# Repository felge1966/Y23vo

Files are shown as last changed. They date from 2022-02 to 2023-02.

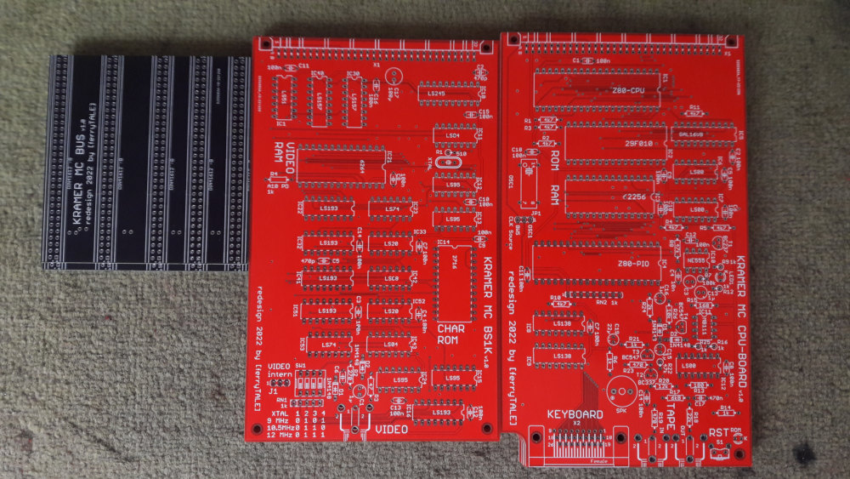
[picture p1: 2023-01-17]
Redesign-2022/KRAMER2022/KRAMER2022_v1.0.jpg

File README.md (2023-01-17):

# Y23vo
Neudesign des Mikrocomputers M.Kramer

Bisher sind folgende Baugruppen realisiert:
- CPU mit RAM und EPROM 
- BWS mit 2K Zeichengenerator 
- Floppycontroller mit u8272 (nach FA 07/1990)
- Grafikdisplaycontroller mit U82720 (nach FA 07/1990)
- 2PIO
- SIO mit U856, U857 und 8251
- Backplane mit 8 Steckplätzen

Alle Baugruppen können mit EFS 29 (A-B oder A-C) Steckverbindern oder alternativ mit DIN 41612 C 2*32 bestückt werden.

Bei CPU, 2PIO und SIO sind GALs als Decoder in Verwendung. 
Die Erstellung erfoolgte mit WinCUPL. Die Sourcen liegen im Verzeichnis

Die Verzeichnisse Redesign 2020 und Redesign 2022 stammen von der Nachetwicklung im Robotrontechnik-Forum.
-> ferrytale

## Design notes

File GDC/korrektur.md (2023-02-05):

GDC Korrektur

GDC U8 Pin 2 (DBin) zur U1 Pin11 Verbindung fehlt
U2720DC02 ist verwendbar

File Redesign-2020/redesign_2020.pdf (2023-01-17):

2022/12/17 14:11 | 1/7 | Redesign 2020

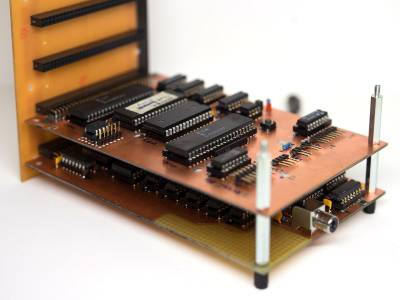
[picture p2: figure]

Homecomputer DDR - https://hc-ddr.hucki.net/wiki/

# Redesign 2020

Wie im robotron-Forum angekündigt (https://www.robotrontechnik.de/html/forum/thwb/showtopic.php?threadid=18678) möchte ich mein Redesign des Kramer-MCs aus dem ersten Corona-Lockdown 2020 gern veröffentlichen. Im Moment existieren 3 Platinen als als Quasi einseitige Layouts zum Selberätzen als Prototyp-Platinen um die etwas abgewandelte Schaltung zu testen und Korrekturen vorzunehmen, bevor dann zweiseitige Layouts zur professionellen Fertigung erstellt werden. Ich möchte damit einen einfachen Nachbau dieses interessanten Rechners auch für andere ermöglichen, ohne jedes mal ausgehend von den Originalschaltplänen von Vorne beginnen zu müssen. Die veröffentlichten Schaltplan- und Layoutdateien können anderen Bastlern gerne auch als Funktionsgrundlage für eigene Modifikationen und Erweiterungen dienen. Ich hoffe, es ist möglich, die Eagle-Dateien in andere Layout-Formate (KiCad, ) zu transformieren, denn aufgrund der Platinengröße sind die Dateien wohl nicht mehr mit der Free-Licence von Eagle veränderbar. Ich kann aber bis jetzt leider nichts anderes

als Eagle. Ich hoffe, ich schaffe es, bis Sommer 2021 die 3 hier präsentierten Module als zweiseitige, funktionierende Platinenlayouts zur Verfügung zu stellen.

Hier schon mal einiges zu dieser ersten Prototyp-Variante:

Eagle-Dateien: (https://hc-ddr.hucki.net/wiki/lib/exe/fetch.php/homecomputer/kramermc/redesign2020/kramermc_ferrytale2020_proto_eagle.zip)

kramermc_ferrytale2020_proto_eagle.zip

## CPU Board mit Tastaturinterface

einseitiges Layout auf zweiseitiger Platine, Top-Layer dient als GND, Durchkontaktierung an GND-Pins von Fassungen und Bauteilen, oder durch Draht
fehlende Verbindungen (später im 2. Layer) durch Drahtbrücken auf Leiterseite
ICs z.T. durch aktuellere Typen ersetzt:
RAM: 32kB 62256

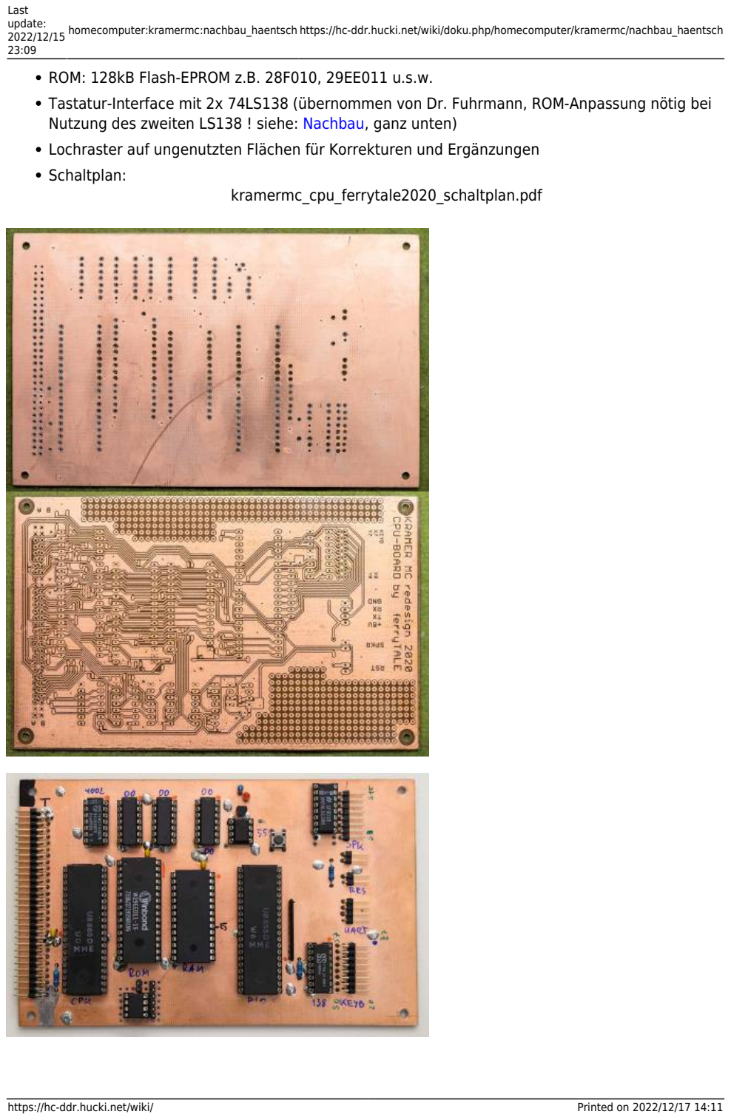
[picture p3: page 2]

Last
update:
homecomputer:kramermc:nachbau_haentsch https://hc-ddr.hucki.net/wiki/doku.php/homecomputer/kramermc/nachbau_haentsch
https://hc-ddr.hucki.net/wiki/ | Printed on 2022/12/17 14:11

ROM: 128kB Flash-EPROM z.B. 28F010, 29EE011 u.s.w.
Tastatur-Interface mit 2x 74LS138 (übernommen von Dr. Fuhrmann, ROM-Anpassung nötig bei Nutzung des zweiten LS138 ! siehe: Nachbau, (https://hc-ddr.hucki.net/wiki/doku.php/homecomputer/kramermc/nachbau) ganz unten)
Lochraster auf ungenutzten Flächen für Korrekturen und Ergänzungen
Schaltplan:
kramermc_cpu_ferrytale2020_schaltplan.pdf

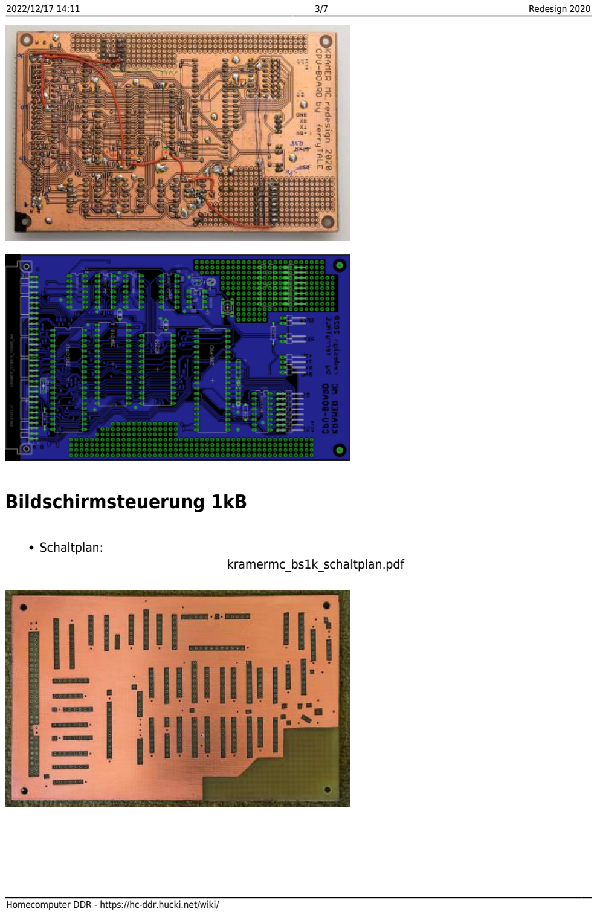
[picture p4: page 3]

2022/12/17 14:11 | 3/7 | Redesign 2020

## Bildschirmsteuerung 1kB

Schaltplan:
kramermc_bs1k_schaltplan.pdf

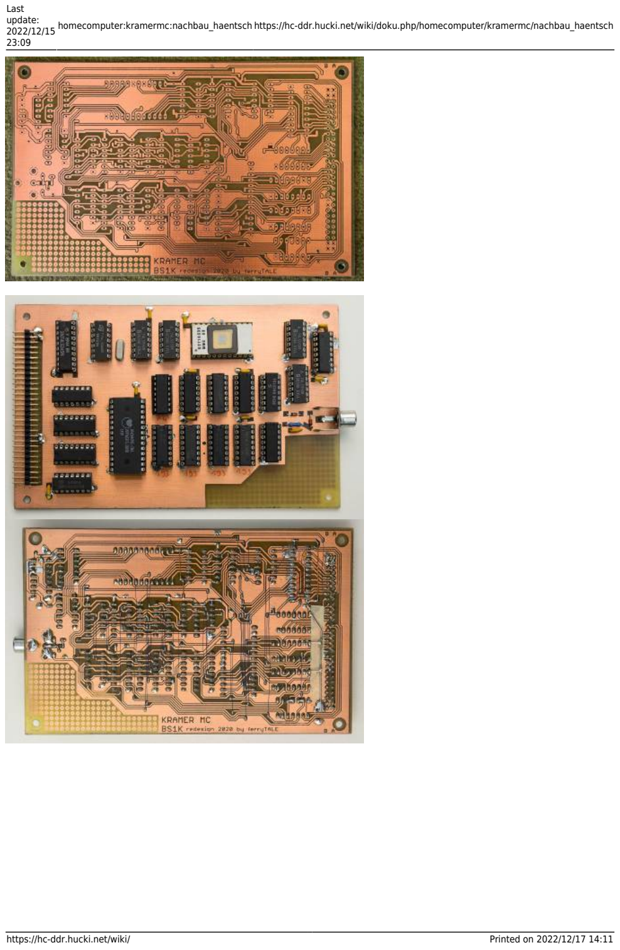
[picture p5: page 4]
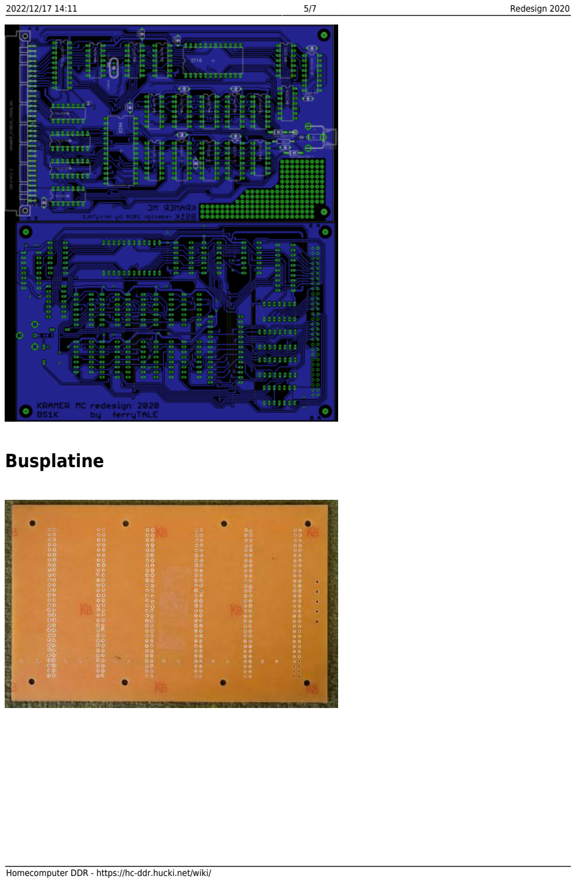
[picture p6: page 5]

2022/12/17 14:11 | 5/7 | Redesign 2020

## Busplatine

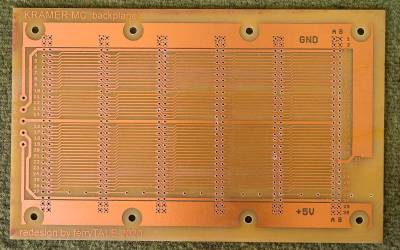
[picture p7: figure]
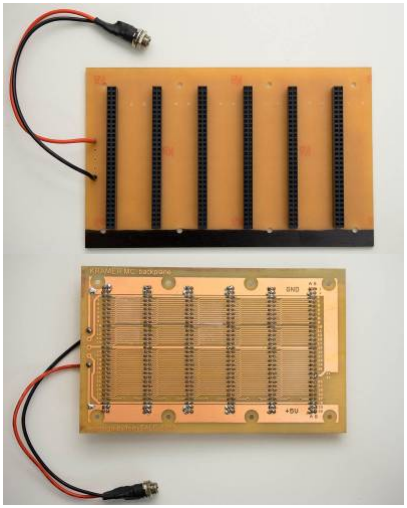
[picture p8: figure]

# 2-Layer Platinenlayouts 2022 v1.0

Ende 2022 habe ich es endlich geschafft, die zweiseitigen Platinenlayouts für CPU-Board, 1kB-Bildschirmansteuerung und eine Busplatine für 5 Karten fertigzustellen. Die ersten 5 Platinensätze sind heute, am 15.12.2022 bei mir eingetroffen. Sicher wird da noch der eine oder andere Fehler dabei sein, sicher ist noch hier und da was zu verbessern oder zu optimieren, aber zumindest kann

2022/12/17 14:11 | 7/7 | Redesign 2020
nun ein Basissystem relativ einfach reproduziert werden.

Auf dem CPU-Board habe ich nun noch das Kassetteninterface gemäß dem Schaltplan von Dr. Fuhrmann untergebracht
der Bestückungsdruck beinhaltet auch gleich die Bauteilwerte, so dass zum Aufbau kein Schaltplan benötigt wird (wenn alles gut geht)

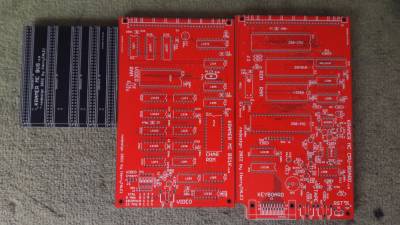
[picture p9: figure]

Eagle-Dateien und Schaltpläne als PDF: kramer2022.zip

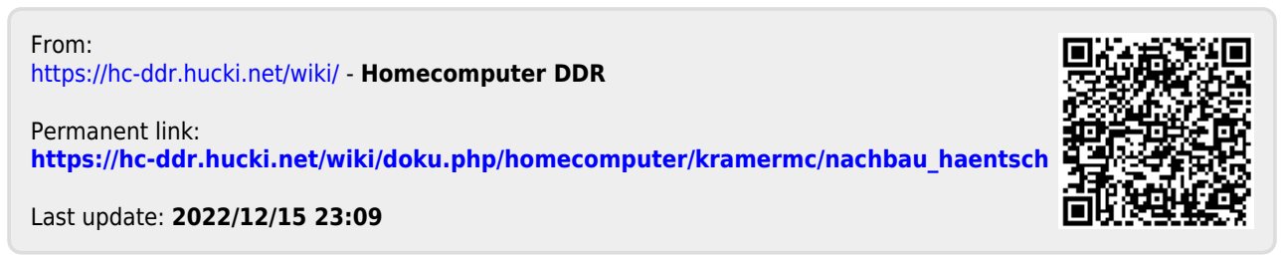
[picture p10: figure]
From: https://hc-ddr.hucki.net/wiki/ - Homecomputer DDR; Permanent link: https://hc-ddr.hucki.net/wiki/doku.php/homecomputer/kramermc/nachbau_haentsch; Last update: 2022/12/15 23:09

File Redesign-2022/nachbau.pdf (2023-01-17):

2022/12/12 14:16 | 1/4 | Nachbau

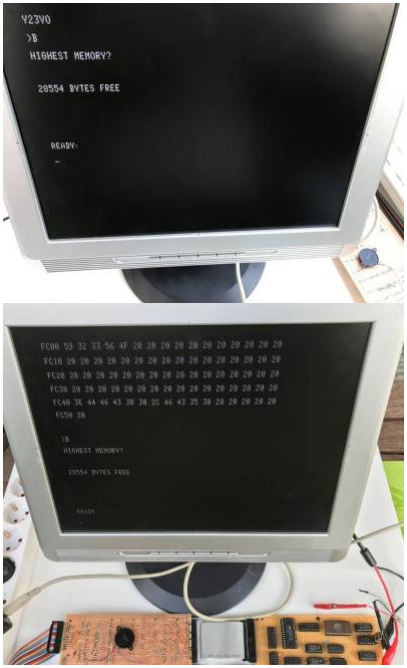
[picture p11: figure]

Homecomputer DDR - https://hc-ddr.hucki.net/wiki/

# Nachbau

Dr. B. Fuhrmann hat 2019 einen Kramer-PC aufbauend auf der im Buch beschriebenen Hardware original nachgebaut. Der Aufbau erfolgte auf Lochraster-Platinen mit Handverdrahtung. Es wurden teilweise modernere Schaltkreise verwendet (RAM, ROM). Zur Adressdekodierung kam ein GAL zum Einsatz.

Gut zu sehen ist die Bilderzeugung mit je einer Text- und einer Dunkelzeile.

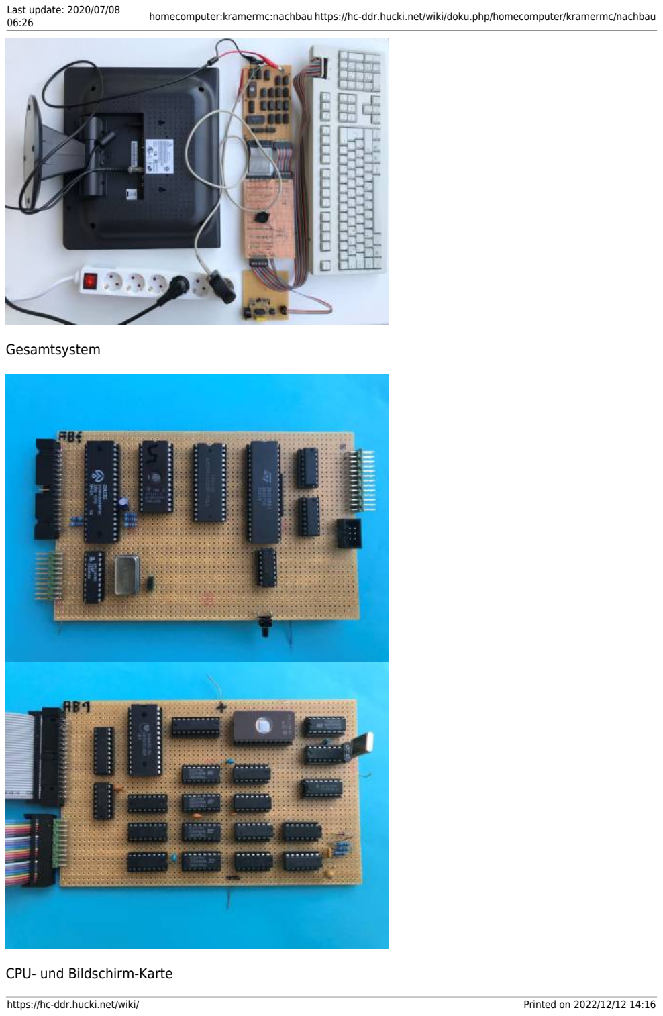
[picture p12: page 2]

Last update: 2020/07/08
06:26 | homecomputer:kramermc:nachbau https://hc-ddr.hucki.net/wiki/doku.php/homecomputer/kramermc/nachbau
https://hc-ddr.hucki.net/wiki/ | Printed on 2022/12/12 14:16

Gesamtsystem

CPU- und Bildschirm-Karte

2022/12/12 14:16 | 3/4 | Nachbau

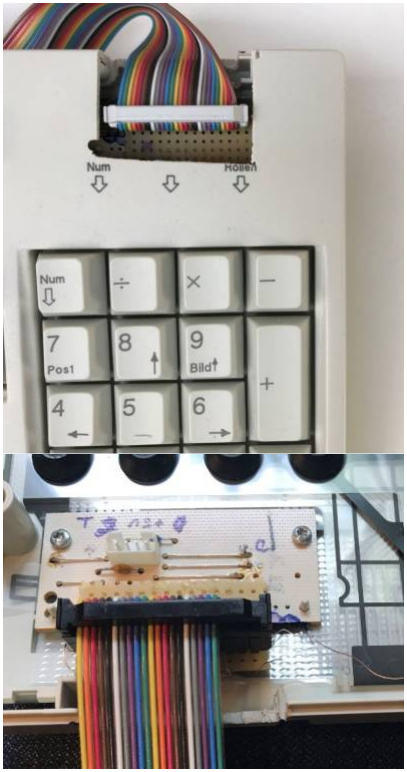
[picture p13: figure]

Homecomputer DDR - https://hc-ddr.hucki.net/wiki/

Last update: 2020/07/08
06:26 | homecomputer:kramermc:nachbau https://hc-ddr.hucki.net/wiki/doku.php/homecomputer/kramermc/nachbau

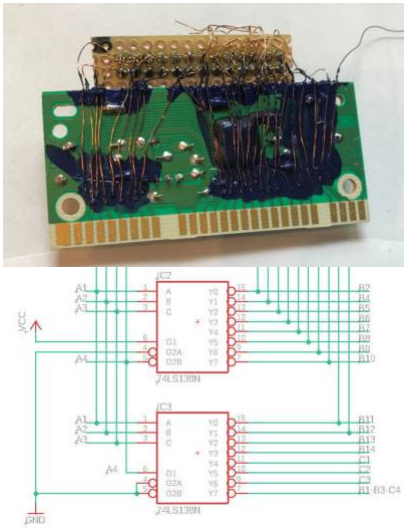
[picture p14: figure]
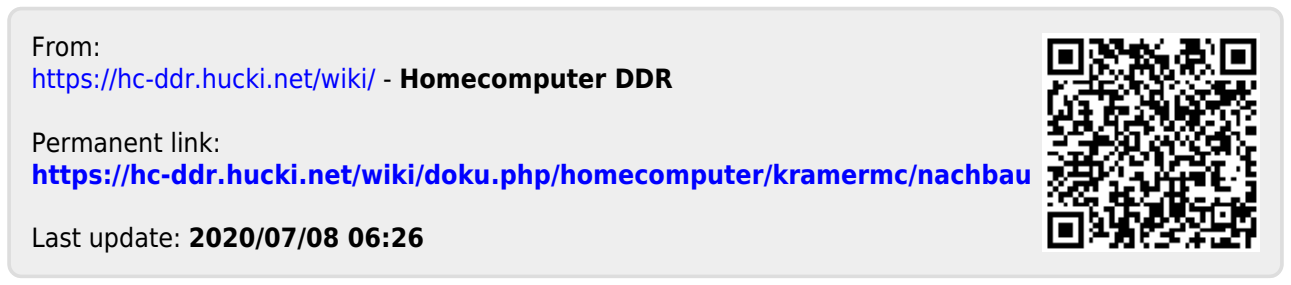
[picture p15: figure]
From: https://hc-ddr.hucki.net/wiki/ - Homecomputer DDR; Permanent link: https://hc-ddr.hucki.net/wiki/doku.php/homecomputer/kramermc/nachbau; Last update: 2020/07/08 06:26

https://hc-ddr.hucki.net/wiki/ | Printed on 2022/12/12 14:16

Als Tastatur wurde eine normale PC-Cherry-Tastatur genutzt. Der enthaltene Controller wird nicht genutzt. Im IO-System wurde die Tastaturmatrix entsprechend angepasst (neue TTAB).

* (https://hc-ddr.hucki.net/wiki/lib/exe/fetch.php/homecomputer/kramermc/tastatur_fuhrmann.zip)

tastatur_fuhrmann.zip
Unterlagen zum Tastaturanschluss

Aktuell ist die CP/M-Ausbaustufe (https://hc-ddr.hucki.net/wiki/doku.php/homecomputer/kramermc/ausbaustufe2) in Arbeit. Es gibt inzwischen 4 Platinen: CPU, Bildschirm, Floppymodul sowie Schrittbetrieb mit Anzeige. Das CP/M 2.2 ist mit dem Kramer-BIOS verheiratet.

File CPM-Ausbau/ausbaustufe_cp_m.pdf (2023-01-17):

2022/12/12 14:12 | 1/7 | Ausbaustufe CP/M

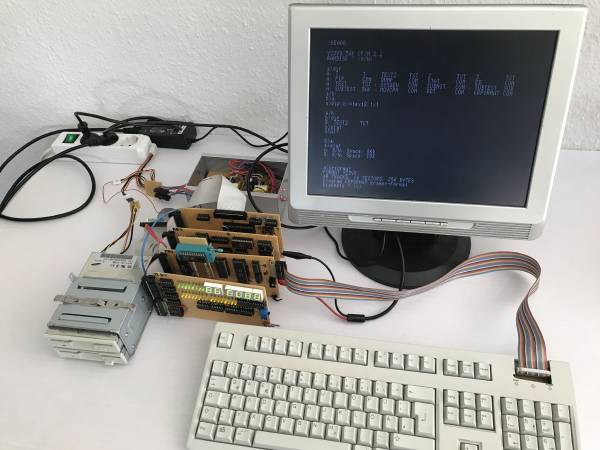
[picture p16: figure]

Homecomputer DDR - https://hc-ddr.hucki.net/wiki/

# Ausbaustufe CP/M

die Ausbaustufe CP/M ist im Buch nicht vollständig beschrieben. Die abgedruckten Programme passen nicht ganz zusammen. Das ganze ist eher ein Rezeptbuch als eine Nachbauanleitung, aber als solche ist es im Buch auch nicht gedacht. Dr. Fuhrmann hat seinen Nachbau 2019 (https://hc-ddr.hucki.net/wiki/doku.php/homecomputer/kramermc/nachbau) ausgebaut und CP/M-fähig gemacht.

Vielen Dank an Dr. Fuhrmann für die Arbeit, die Bilder und die ganzen Unterlagen!

Karten von vorn nach hinten:

Einzelschritt-Karte
CPU-Karte mit EPROM-Adapter Bildschirm-Karte
Floppy-Karte

Der Bus ist über Flachbandkabel realisiert.

## Beschreibung

April 2020. Dr. Fuhrmann schreibt:

Die Bildschirmkarte habe ich modifiziert, mittels Jumpern kann die Platine jetzt zwischen 1kB und 2kB

Last update:
2020/07/08 10:30 | homecomputer:kramermc:ausbaustufe2 https://hc-ddr.hucki.net/wiki/doku.php/homecomputer/kramermc/ausbaustufe2
https://hc-ddr.hucki.net/wiki/ | Printed on 2022/12/12 14:12

Bildwiederholspeicher, also 32 Zeilen x 64 Zeichen, umgesteckt werden, siehe Schaltplan. Eine ordentliche Anschlussbuchse für den Monitor gibt es noch immer nicht. Die CPU-Platine hat noch einen 4MHz Quarz bekommen, ein externes FF für die Speicherumschaltung und eine RESET-Taste. Neu sind die Platinen Einzelschrittsteuerung und natürlich die Floppy-Steuerung. Die Einzelschrittsteuerung hat eine einfache Anzeige mit einer Diode pro Bit sowie 7-Segmentanzeigen mit V40511 für Adress- und Datenbus. Als Diskettenlaufwerke benutze ich zwei nach https://honi.hucki.net/ umgebaute 3,5-Laufwerke. Das Kramer-CP/M benutzt nur ein Laufwerk, Ihr FORMATZ beide. Die Formatierung mit Ihrem Programm, hatte ich ja bereits erwähnt, funktioniert zur Zeit nur mit dem zweiten Laufwerk.

Die Platzierung der Bauelemente auf der Floppy-Platine habe ich dem Modul von Herrn Sander nachempfunden. https://www.sax.de/~zander/index2h.html

Anbei auch die Programme.

Es gibt jetzt 4 EPROM/GAL-Versionen:

1kB Bildwiederholspeicher (BWS) Ausbaustufe 1
2kB BWS Ausbaustufe 1
1kB BWS Ausbaustufe CP/M CTAB ab 0F800H Monitor-RAM ab 0FB00H
2kB BWS Ausbaustufe CP/M CTAB ab 0D000H Monitor-RAM ab 0D300H

Zur Erzeugung des EPROM-Abbildes gibt es jeweils Batch-Dateien mit dem JKCemu.

kramer-jkcemu-1k.bat
kramer-jkcemu-2k.bat
CPM-EPROM-1k.bat
CPM-EPROM-2k.bat

CP/M

Das CBIOS/CPP/BDOS sowie der Monitor werden mittels Kopierprogramm copy2.asm (Aufruf G1000) vom EPROM in den RAM geladen. Zur Zeit wird das CP/M danach durch zwqeimaligen Sprung auf 0EA00H (CBIOS) gestartet. Dadurch wird BDOS und CPP nochmal von der Systemdiskette geladen.

Formatierung einer Diskette:

G1000 CBIOS/CPP/BDOS und Hilfsprogramme in den RAM laden.
GEA00 einmal ausführen
G8800 Disketten-init starten

Erstellung der Systemdiskette:

CBIOS/CPP/BDOS mit G1000 in den RAM laden. Im CBIOS RFLOP Call zu WFLOP ändern wie in den Kommentaren im Kramer-CBIOS beschrieben:

Mit dem S(ubstitute) Kommando dazu ab 0EB0FH

CD 6C EB | CALL RFLOP | ändern in
CD C6 EB | CALL WFLOP

2022/12/12 14:12 | 3/7 | Ausbaustufe CP/M
und das CP/M mit GEA00 starten.Systemspuren werden auf die formatierte Diskette geschriebenkann man eine Systemdiskette erzeugen.

Einige transiente CP/M-Kommandos aus http://www.classiccmp.org/cpmarchives/cpm/Software/rlee/D/DIGITAL%20RESEARCH/CPM_2-2/SYSTEM/ (http://www.classiccmp.org/cpmarchives/cpm/Software/rlee/D/DIGITAL%20RESEARCH/CPM_2-2/SYSTEM/) habe ich zunächst nacheinander auf EPROM gebrannt, mit dem Monitorkommando Move auf Adresse 100H kopiert und dann im CP/M mit dem save-Kommando auf Diskette gespeichert. Ebenfalls auf der Diskette ist das Formatierungsprogramm aus dem Buch Disketten-Init (KRFORMAT.COM) ab Adresse 100H.

Mit dabei mein Z80-Crossassembler von 1991, mit Delphi7 neu übersetzt, sowohl für die Kommandozeile als auch mit grafischer Umgebung. Den habe ich aktualisiert, um die Listfiles zu erzeugen und bedingte Compilierung zu ermöglichen, weil das der JKCemu nicht leistet.

## Downloads

2020-04-14-assembler.zip

in den Ordnern mit jkcemu-0.9.7.txt muss der jkcemu-0.9.7.jar von http://www.jens-mueller.org/jkcemu/download.html abgelegt werden! 2020-04-14-eagle.zip
2020-04-14-gals.zip

## Bilder

Alle Karten sind auf Lochrasterplatten aufgebaut und handverdrahtet (gefädelt).

Einzelschritt-Karte
CPU-Karte mit EPROM-Adapter
Bildschirm-Karte
Floppy-Karte

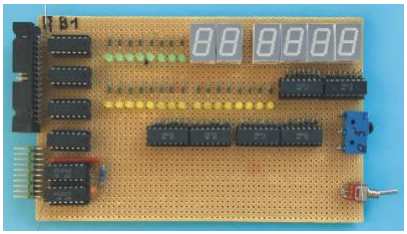
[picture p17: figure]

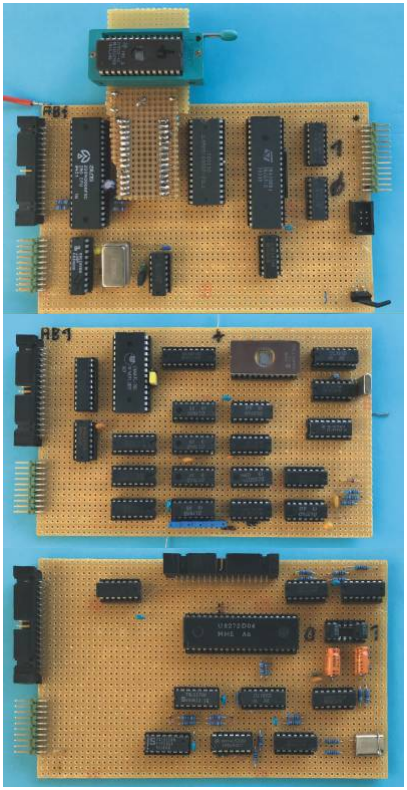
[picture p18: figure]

Der EPROM auf der CPU-Karte ist zum einfachen Wechsel über einen kleinen Adapter nach oben herausgeführt:

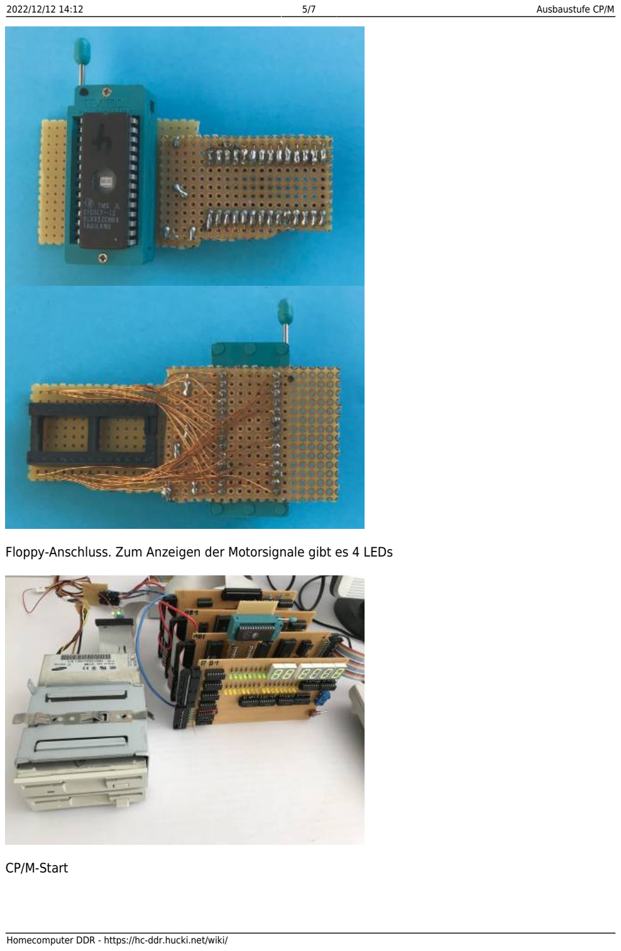
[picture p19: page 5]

2022/12/12 14:12 | 5/7 | Ausbaustufe CP/M

Floppy-Anschluss. Zum Anzeigen der Motorsignale gibt es 4 LEDs

CP/M-Start

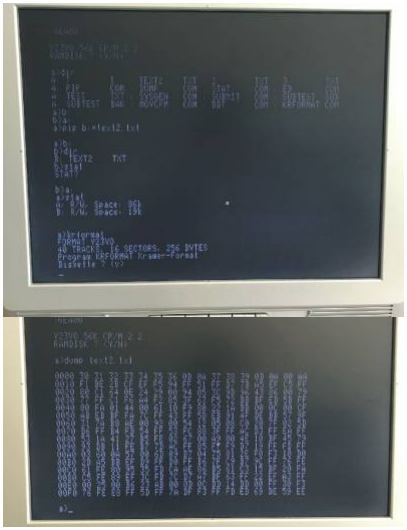
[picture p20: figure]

## Buch

Informationen aus dem Buch zur dort beschriebenen Ausbaustufe CP/M.

Die orig.Programme aus dem Buch (korrigiert bzw. ergänzt) sind im Basis-Download-Paket enthalten ( downloads) (https://hc-ddr.hucki.net/wiki/doku.php/homecomputer/kramermc#downloads)

Ausbaustufe CP/M (S.119)

Takt 2.625 MHz (10.5 MHz:4) RAM ab 0000
Monitor ab F000

Nach Einschalten ist Monitor auf 0000 ansprechbar, der RAM ist deaktiviert. Ein Sprung auf Adresse F003 schaltet den Monitor auf Adresse F000 und aktiviert den RAM.

Einbeziehung Kassetteninterface mit USART nach Bild 4.1 in die Monitorroutinen RI und WO. Das CBIOS wird von Kassette geladen.

FC00-FFFF Bildwiederholspeicher
F800-FBFF Monitor-RAM

2022/12/12 14:12 | 7/7 | Ausbaustufe CP/M
F000-F7FF Monitor (ohne Disassembler)
E200-EFFF CBIOS
D400-E1FF BDOS
CC00-D3FF CCP
0100-C000 freier RAM (TPA)
0000-00FF freier RAM (Zero-Page)

Das Listing im Buch auf S. 199 ist falsch. Der Bereich 400h-7FFh (rechtes Listing) ist DE.ASM der originalen Version. Das kann so nicht funktionieren!!

nicht beschriebene externe Kommandos:

Kdo A jp C800
Kdo Y jp F7B0

FDC-Laufwerk K5600.10 (MFS 1.2)

32 Records/Spur, 3 Systemspuren mit CP/M 74 Blöcke a 2K = 148K Disk Phys. Sektoren a 256 Byte, 40 Spuren mit 16 Sektoren

Port 78h, 7Ch, 7Dh FDC U8272 (S. 124)
Port 7eh, 7fh USART 8255 (Kassetteninterface S. 111)

RAM-Disk 7000h-BFFFh

26 Records/Spur, 20 Blöcke a 1K = 20K Disk

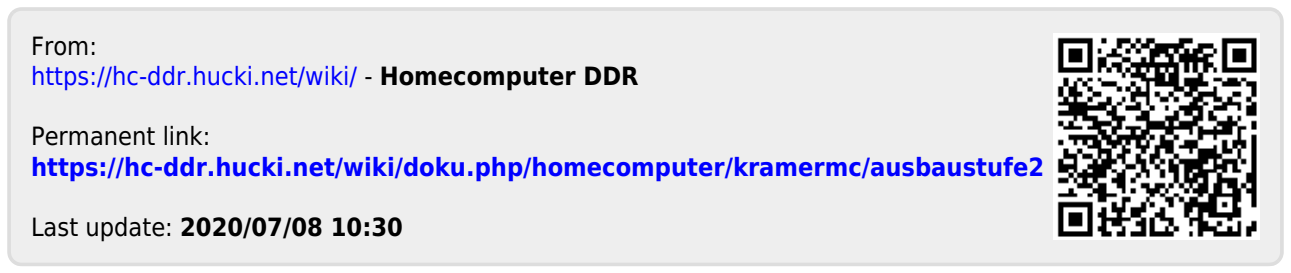
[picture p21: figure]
From: https://hc-ddr.hucki.net/wiki/ - Homecomputer DDR; Permanent link: https://hc-ddr.hucki.net/wiki/doku.php/homecomputer/kramermc/ausbaustufe2; Last update: 2020/07/08 10:30

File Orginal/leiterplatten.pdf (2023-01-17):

# Leiterplatten

## Besitzer: J. Felgentreu

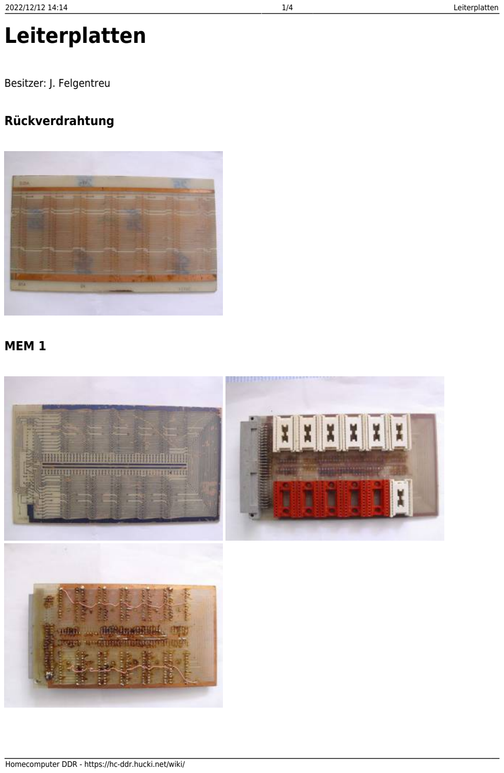
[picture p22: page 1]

2022/12/12 14:14 | 1/4 | Leiterplatten

Homecomputer DDR - https://hc-ddr.hucki.net/wiki/

## Rückverdrahtung

## MEM 1

## MEM 2

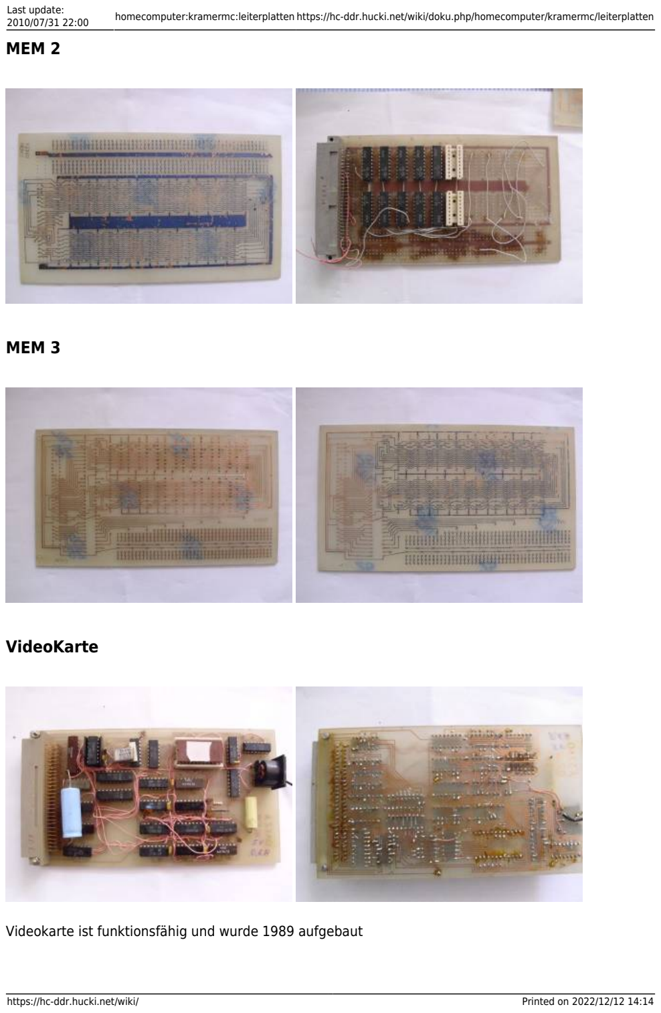
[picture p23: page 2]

Last update:
2010/07/31 22:00 | homecomputer:kramermc:leiterplatten https://hc-ddr.hucki.net/wiki/doku.php/homecomputer/kramermc/leiterplatten
https://hc-ddr.hucki.net/wiki/ | Printed on 2022/12/12 14:14

## MEM 3

## VideoKarte

## Videokarte ist funktionsfähig und wurde 1989 aufgebaut

## CPU-Karte

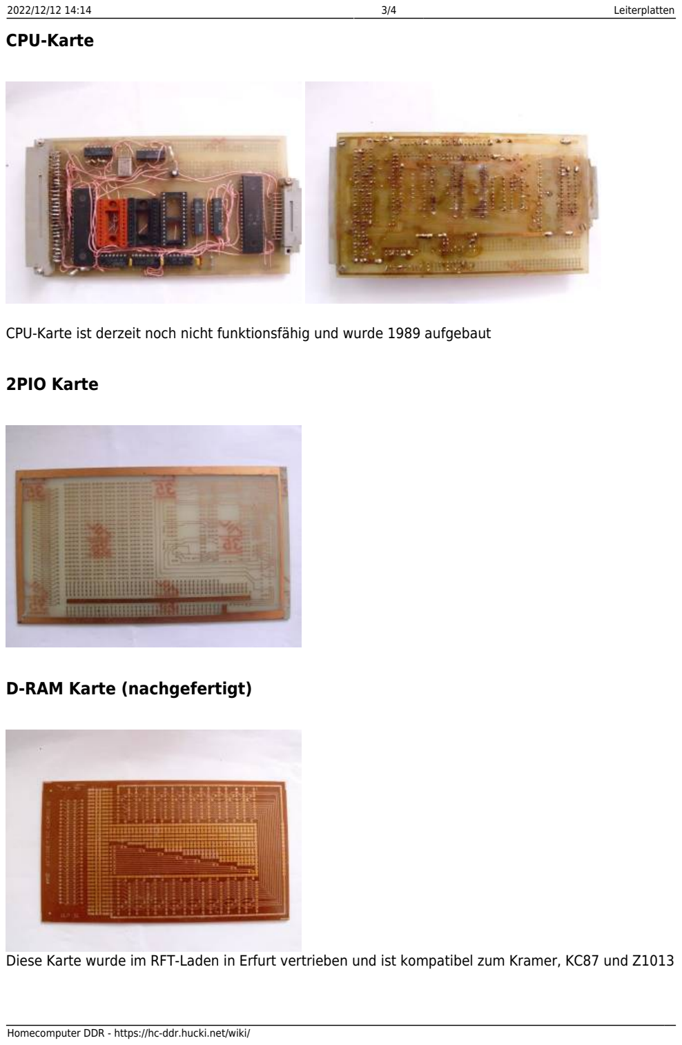
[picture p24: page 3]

2022/12/12 14:14 | 3/4 | Leiterplatten

Homecomputer DDR - https://hc-ddr.hucki.net/wiki/

## CPU-Karte ist derzeit noch nicht funktionsfähig und wurde 1989 aufgebaut

## 2PIO Karte

## D-RAM Karte (nachgefertigt)

Diese Karte wurde im RFT-Laden in Erfurt vertrieben und ist kompatibel zum Kramer, KC87 und Z1013

Last update:
2010/07/31 22:00 | homecomputer:kramermc:leiterplatten https://hc-ddr.hucki.net/wiki/doku.php/homecomputer/kramermc/leiterplatten

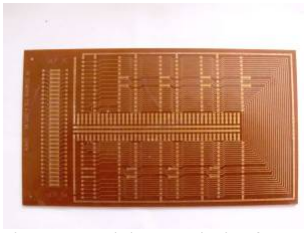
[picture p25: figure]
From:; Permanent link:; Last update: 2010/07/31 22:00

https://hc-ddr.hucki.net/wiki/ | Printed on 2022/12/12 14:14

## EPROM Karte (nachgefertigt)

Diese Karte wurde im RFT-Laden in Erfurt vertrieben und ist kompatibel zum Kramer, KC87 und Z1013

## Floppycontroller

unvollendeter Nachbau entsprechend der Beschreibung im Buch Praktische Mikrocomputertechnik

## vom M.Kramer

### https://hc-ddr.hucki.net/wiki/ - Homecomputer DDR

### https://hc-ddr.hucki.net/wiki/doku.php/homecomputer/kramermc/leiterplatten

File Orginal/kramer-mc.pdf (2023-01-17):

# Kramer-MC

## Systembeschreibung


2023/01/11 15:18 | 1/4 | Kramer-MC

Homecomputer DDR - https://hc-ddr.hucki.net/wiki/

Manfred Kramer http://www.dl2kmk.de veröffentlichte 1987 ein Buch Praktische Mikrocomputertechnik in der Reihe Amateurbibliothek des Militärverlags der DDR. In diesem wurde Hard- und Software eines 8-Bit-Mikrocomputers beschrieben.

Buch und originaler MC von OM Kramer Y23VO, erweitert um Floppy und Vollgrafik (aus FA 3/88, III US)

Bildschirmanzeige (B. Fuhrmann).

Last update: 2022/12/27 12:08 | homecomputer:kramermc https://hc-ddr.hucki.net/wiki/doku.php/homecomputer/kramermc
https://hc-ddr.hucki.net/wiki/ | Printed on 2023/01/11 15:18

Bilder der Leiterplatten siehe Leiterplatten (https://hc-ddr.hucki.net/wiki/doku.php/homecomputer/kramermc/leiterplatten) .

## technische Daten

Grundmodell lt. Kapitel 1 bis 3.1)

Merkmal | Beschreibung
CPU | U880
RAM/ROM | 64 KByte
Takt | 1.5 MHz
Anzeige | 64 x 16 Zeichen s/w Darstellung auf TV, 1 KByte Bildwiederholspeicher
Tastatur | alphanum.
Peripherie 1 PIO für Tastaturansteuerung, Beeper, und serielle Ein- und Ausgabe
Software | Monitor, Debugger, Reassembler, Editor, Assembler, BASIC

Speicheraufteilung

Speicherbereich Inhalt | | Buchhinweise
0000-03FF | Monitor | S. 44ff
0400-07ff | Debugger | S. 66
0800-0BFF | Reassembler
0C00-0FFF | System-RAM
1000-FBFF | freier RAM
4000-7FFF | Textspeicher f. Editor
8000-AFFF | BASIC | S. 41ff
C000-C3FF | Editor | S. 72
C400-DFFF | Assembler | S. 74
FC00-FFFF | Bildwiederholspeicher

Im Buch ist auch der Ausbau zum CP/M-Computer begonnen Ausbaustufe CP/M (https://hc-ddr.hucki.net/wiki/doku.php/homecomputer/kramermc/ausbaustufe2)

## Literatur

1. Manfred Kramer: Praktische Mikrocomputertechnik, Militärverlag der DDR, Reihe Amateurbibliothek, 1987, Softcover, ISBN 3327003610
2. Manfred Kramer: Praktische Mikrocomputertechnik, Militärverlag der DDR, Reihe Amateurbibliothek, 2. berichtigte Auflage 1988, Softcover, ISBN 3327003610

## Downloads

kramer.zip
8.12.2019
neu: Disassembler Source, 15.8. BASIC Source, Editor Source, Ausbaustufe 2 (nach Buch) Unterlagen aus dem Buch, Korrektur zum Buch (Funkamateur 8/87)

2023/01/11 15:18 | 3/4 | Kramer-MC

Homecomputer DDR - https://hc-ddr.hucki.net/wiki/

Software aus dem Buch (Dank an Torsten Paul fürs Abtippen des BASIC und Korrektur des ASSEMBLERs)
Einen Bitmap-Font mit dem Zeichensatz des KramerMC
Technische Daten zum Rechner

Mein Emulator für Windows incl. Hilfe krameremu.zip (https://hc-ddr.hucki.net/wiki/lib/exe/fetch.php/kramermc/krameremu.zip)
(Version test8, es geht schon einiges; KCEMU und JKCEMU emulieren auch den Kramer-MC) die aktuellste Software von Manfred Kramer y23vo.zip (https://hc-ddr.hucki.net/wiki/lib/exe/fetch.php/kramermc/y23vo.zip)

der Assembler funktioniert nicht. Falls jemand eine funktionierende Version hat oder im Vergleich mit dem Abdruck im Buch einen Fehler gefunden hat, möge mir bitte die Version zukommen lassen

## Bedienung

s. Bedienung (https://hc-ddr.hucki.net/wiki/doku.php/homecomputer/kramermc/bedienung)

Kurz:

>OT | Ausgabe auf Terminal (Bildschirm)
>IT | Eingabe von Terminal (Bildschirm)
>OL | Ausgabe auf Kassettenrekorder (Standard nach Reset)
>IL | Eingabe von Kassettenrekorder (Standard nach Reset)

>Waadr,eadr Ausgabe auf Out-Kanal (z.B. Kassettenrekorder)
>Esadr | Startadr. anfügen
>R | einlesen
>Radr | einlesen auf andere Adresse
>B | Basic, Ende mit Ctrl-X
>T | Texteditor

sonstiges:

Das BASIC ist das TDL-BASIC V2.1, angepasst an den Kramer-MC.
Der Assembler verarbeitet die robotron-SYPS-K1520-Mnemonik (s.a. syntax) (https://hc-ddr.hucki.net/wiki/doku.php/z9001/software/edas#syntax)

## Sonstiges

Last update: 2022/12/27 12:08 | homecomputer:kramermc https://hc-ddr.hucki.net/wiki/doku.php/homecomputer/kramermc

From: https://hc-ddr.hucki.net/wiki/ - Homecomputer DDR; Permanent link: https://hc-ddr.hucki.net/wiki/doku.php/homecomputer/kramermc; Last update: 2022/12/27 12:08

https://hc-ddr.hucki.net/wiki/ | Printed on 2023/01/11 15:18

mein Emulator, (https://hc-ddr.hucki.net/wiki/lib/exe/fetch.php/kramermc/krameremu.zip) die Bedienung des KramerMC ist in der Hilfe zum Emulator beschrieben. Den Sourcecode (Delphi) gibts auf Anfrage.

Ich habe es nie leider geschafft, einen wie im Buch beschriebenen Mikrorechner zu bauen (das war zum einen eine Materialfrage und zum anderen hatte ich ja meinen Z1013), aber die Ideen und vor allem die Software des Buches waren sehr interessant.

Mit modernerer Rechentechnik ist es heute wesentlich einfacher als vor 15 Jahren, die Listings zu digitalisieren (sprich zu scannen) und auch die Hardware kann in einem Emulator nachgebildet werden.

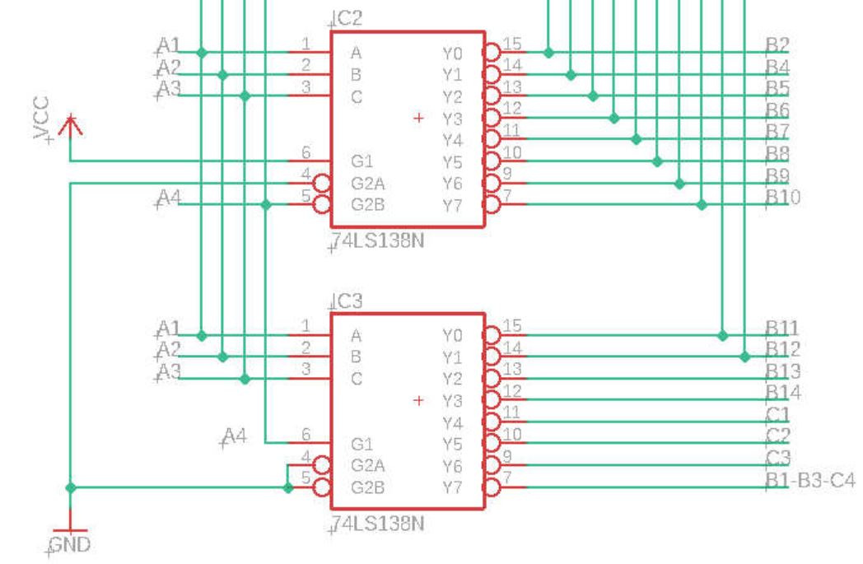
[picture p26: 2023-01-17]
Redesign-2020/tastatur_fuhrmann/Tastaturansteuerung.JPG

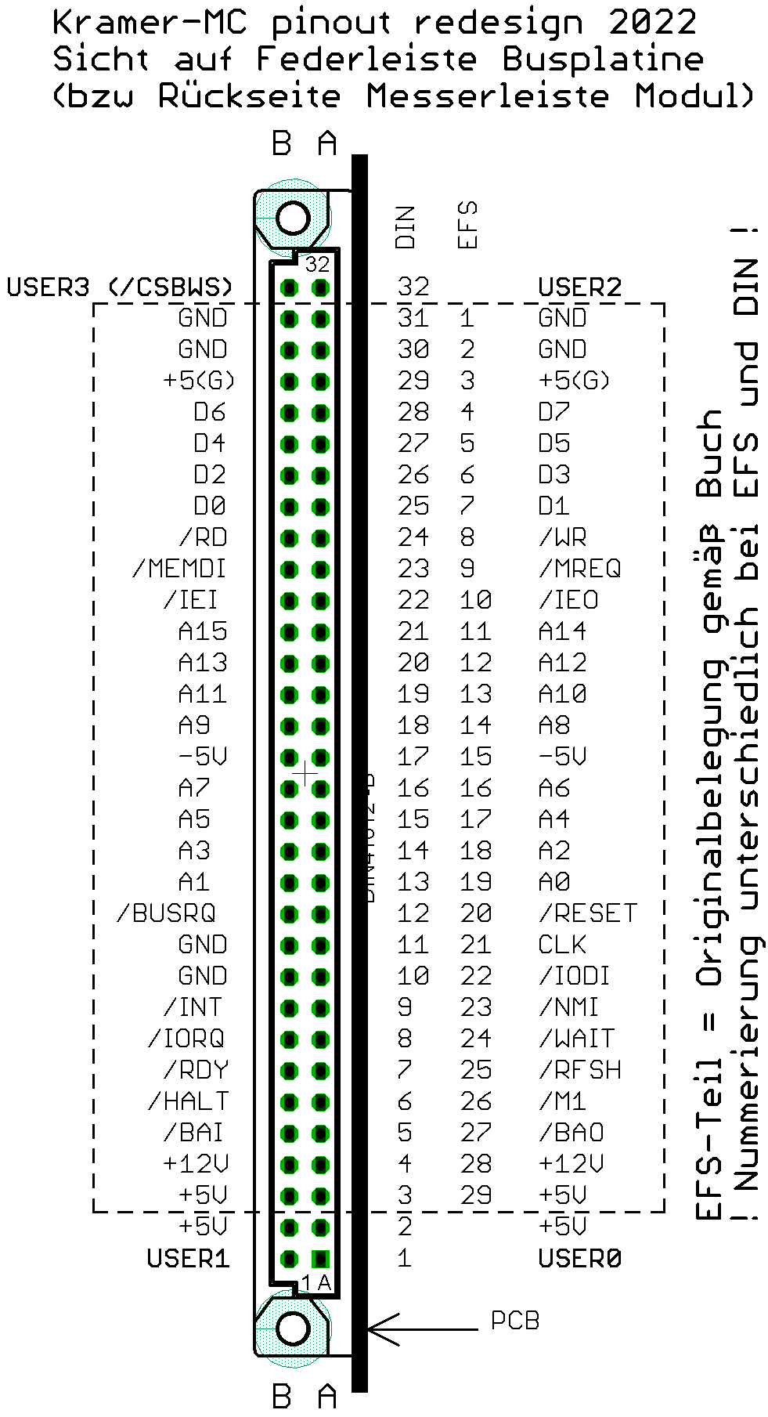
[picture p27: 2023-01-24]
Redesign-2022/kramermc_bus-pinout.png

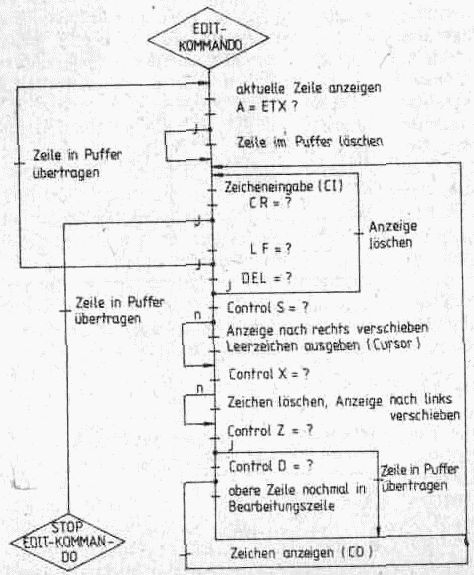
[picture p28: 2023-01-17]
Orginal/kramer/buch/bid 2.8.jpg

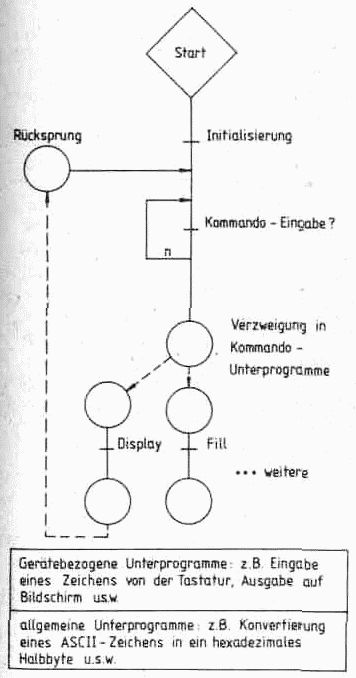
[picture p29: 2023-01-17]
Orginal/kramer/buch/bild 2.7.jpg

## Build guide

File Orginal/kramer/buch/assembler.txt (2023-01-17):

10C40000C3B0C4C345220040000F06000BDD461B2D
10C41000DD46B0DD70B1DD70BFDD365F01006F114C
10C42000007F21008F31001E3A007E2A00E1320099
10C43000E722006EED5B9FDD219EDD2AAEFD2A8E98
10C44000ED7BAFFD21E5ED43E6ED535EED4BE9DD20
10C4500022EAFD22E8ED731C0A001D1A00C1020049
10C46000D1120087F90089DDF98AFDF913ED57141F
10C47000ED5F31ED4741ED4F00000000000000008E
10C480004100420043004400450048004C00460083
10C49000490052004D0042434445414653505043E9
10C4A00049584959484C00000000000000000000B5
10C4B0002100C411001001AF00EDB02180C5118032
10C4C0001501AF18EDB0C30310FFFFFFFFFFFFFF23
10C4D000FFFFFFFFFFFFFFFFFFFFFFFFFFFFFFFF6C
10C4E000FFFFFFFFFFFFFFFFFFFFFFFFFFFFFFFF5C
10C4F000FFFFFFFFFFFFFFFFFFFFFFFFFFFFFFFF4C
10C50000FFFFFFFFFFFFFFFFFFFFFFFFFFFFFFFF3B
10C51000FFFFFFFFFFFFFFFFFFFFFFFFFFFFFFFF2B
10C52000FFFFFFFFFFFFFFFFFFFFFFFFFFFFFFFF1B
10C53000FFFFFFFFFFFFFFFFFFFFFFFFFFFFFFFF0B
10C54000FFFFFFFFFFFFFFFFFFFFFFFFFFFFFFFFFB
10C55000FFFFFFFFFFFFFFFFFFFFFFFFFFFFFFFFEB
10C56000FFFFFFFFFFFFFFFFFFFFFFFFFFFFFFFFDB
10C57000FFFFFFFFFFFFFFFFFFFFFFFFFFFFFFFFCB
10C5800000000000414443205B414444205A414E96
10C5900044205D4245522066424954205443414361
10C5A000203943414C4C3A43414D203B43414E439B
10C5B0003C43414E5A3D434150203E434150453F4C
10C5C0004341504F4043415A20414343462000439A
10C5D0004D50206143504420184350445219435059
10C5E00049201A435049521B43504C2001444120DA
10C5F00020654441412002444220206444454320B8
10C600005944454620684449202003444A4E5A3143
10C610004549202004454A454369454E44206B4521
10C6200051552067455820204A45584146054558F0
10C6300058200648414C5407494D30201C494D3183
10C64000201D494D32201E494E202037494E43209F
10C6500058494E44201F494E445220494E462023FB
10C66000494E492021494E4952224A4D5020574AAD
10C67000504320424A504D20434A504E43444A5072
10C680004E5A454A505020464A505045474A50500D
10C690004F484A505A20494A522020324A52432099
10C6A000334A524E43344A524E5A354A525A203631
10C6B0004C442020624C444420244C444452254C99
10C6C000444920264C444952274E454720284E4F86
10C6D0005020084F5220205F4F524720634F544450
10C6E000522A4F5449522C4F555420384F555444D8
10C6F000294F5554492B504E20206C504F50204B01
10C70000505553484C524320200C5245532055520B
10C7100045542009524554492F5245544E30524CED
10C7200020204D524C41200A524C43204E524C4343
10C73000410B524C44202D524D20200D524E43208F
10C740000E524E5A200F52502020105250452011A8
10C7500052504F2012525220204F52524120145218
10C76000524320505252434115525244202E5253AC
10C77000542017525A202013534243205C534346FF
10C7800020165345542056534C41205153524120BA
10C790005253524C2053535542205E5449544C6AD4
10C7A000584F5220603F2F27F3FB08D97600C91756
10C7B00007D8F8D0C0F0E8E0C81F0F37C7A9B9A163
10C7C000B146565EAABAA2B270A8B8A0B044ABBB3C
10C7D000A3B36F674D45101838302028DBD3DCCD6C
10C7E000FCD4C4F4ECE4CCDAFAD2C2F2EAE2CAE352
10C7F000C1C5100018082028384080C0E904058011
10C800008898A090B0A8B840000000000000000088
10C810000000381A17501A18951A31A51A37D41A69
10C8200039211B4A471B4BFA1B4D501C54AE1C5759
10C83000ED1C58501D5AE61D5B9D1E5DD91E627988
10C840001F63552164832165D22166EC2167732023
10C85000685E21695E216A5E216BDE206C101A6DB4
10C860001E40216E137EB7C001BF16CDC41860698B
10C87000016A131604CD08277E6069BE3810200AAD
10C88000CD1A2703231520ED7EC90E0118020E00D4
10C89000217810462366687B0F5F3003C601C90705
10C8A0000783477D0D2817803001244F443E17B879
10C8B000380720B73EA3B930B2CDC41818CC903099
10C8C000EA2518E7217810712370C921F9130E03A6
10C8D0000680780F47CDA52470CD5129CDB1240D08
10C8E00020F03601185516012130137E2C46823077
10C8F0000104702D771E8021F91373CD891A16005B
10C90000280ACD911A200CCD5129160121F9137254
10C91000C38319CD2D27160218F2160218CA160362
10C9200018C6160418C2210012AF4FCD9F24210053
10C930001436002336312106143600212C130ECD77
10C94000AFCD9F24CDE822CD6018280F1620CD1A38
10C95000220000000EC721321318E5FE6C20ED21E5
10C960006F137ECD962430E45F2C7ECD9624D48D3B
10C970002430D9213313772D732E2A36012C36001B
10C98000C35E212134130EC5AFCD9F242E2ACD774F
10C99000272E32541E59010200EDB02E31462D4E85
10C9A0002D702D71CDE8222164137EFE3BCA5E21DD
10C9B000FE20CA5E21FE1ECA331AFE00284D1E5BF1
10C9C00054010500EDB0CD60182045D667CA73202C
10C9D000D604DA5E21CADE202158137EFE08300517
10C9E000CD762D2805CD18221821CD6E282019CD01
10C9F000891A2005CD2D2218122160131E2E540EE7
10CA000002CD6F2420EE1803CDD828CD6018280B56
10CA1000CD35222134133604C3221921A5174785A9
10CA20006F7830012446211118235E235623BE302F
10CA3000F8EBE93600C35E21CDD81CCD441AC439C9
10CA400022C3E618216F137EB7C02195137EB7C9A4
10CA5000CDD81CCD891ACAE618CD5C2B2020CD106C
10CA600022201BCD4A1A2016790F0F0FFE08300E18
10CA700007070721341336012C8677C3E6182135C2
10CA8000133600CD3922C3E6180E01217B107EB982
10CA9000C90E0218F6CDE11C36ED2C70CD441AC437
10CAA0003922C31A19CDE11CCD5C2BC29C1B21FB82
10CAB00013462C7EB0200236FF05057EB7280FC630
10CAC00001C29C1BB0F29C1B2E3670C31A19B0FA1F
10CAD0009C1B18F4CD891ACA1A19CDE11CCD4A1A2B
10CAE000C29C1BCD5C2B201121FB13462C7EB7C2B0
10CAF0009C1B21361370C31A19CDEF2AC29C1B212F
10CB0000FE137EB7C29C1B2DCDAE1B472135137E75
10CB100036EDFEDB0E4028010C7807070781471829
10CB2000D1CDE51CCD4A1A2013CD5C2B200E21FB64
10CB3000131E3654010200EDB0C31E192135133601
10CB400000CD3922C31E19CDE11CCDEF2A204D2185
10CB50006F137EFE282EFE7E2031FE50203ECD5BE0
10CB60002D203921FE137EFE5806DD2806FE5906CB
10CB7000FD2006213513C32A1D1600FE4C201D2161
10CB8000341336012C7EB277C3E618FE45200DCD56
10CB90005B2D200821FE137E160818DF2135133681
10CBA00000CD3922C31A19CDAE1BC8FE06C97ED6E8
10CBB000412812D601FE043002BFC9D602FE04C8C5
10CBC000D603FE05C93E07C97E0E03FE46C80DFE0C
10CBD0004CC80DFE45C80DFE43C97E0E03FE50C86D
10CBE00018EC16017E0E03FE50C80D1516582802CB
10CBF0001659BAC818DC160018EACDE11CCD4A1A3D
10CC0000C29C1B2E6F7EFE28CA9C1BCDEF2AC29CA5
10CC10001B21FE13CDA524CDC81B200879070707CB
10CC200007C3731ACDB124CDE21B201706DD79FEB0
10CC300003CA9C1B070707072135134E702C817709
10CC4000C31A19CDB124CDF61B06FD28E1C39C1BE8
10CC5000CDE91CCD4A1AC29F1CCDEF2AC29F1C21D0
10CC60006F13CDA52421FE137EB720162DCDA71B53
10CC7000C29F1C21341336022C4636CB802377C347
10CC80001A19CDB1247EFE28C29F1C21FE13CDC1EE
10CC90001DC29F1C36CB2C712CC60677C3221921CE
10CCA00035133600CD392221341356C3E818CDE9A7
10CCB0001C2E707EB7C29F1C2D7ED630DA9F1CFEC4
10CCC00008D29F1C2135130707078677CD5B2DC23D
10CCD0009F1C219513C3621C0E01213413712C700B
10CCE000C90E0218F50E0318F10E0418EDCDE51C5F
10CCF000CD4A1AC23C1BCDEF2A203E21FD137EFEF9
10CD00004D20072E343601C3E618216F137EFE280E
10CD1000C23C1B2EFE7EFE5806DD201321FB137E37
10CD20002CB6C23C1B2E3436022C7E70C37D1CFEFA
10CD300059C23C1B06FDC31C1DCD5C2BC23C1B21F4
10CD4000FB134E2C462E3536C32C712C70C31E1986
10CD5000CDE51CCD4A1AC23C1BCDEF2AC23C1B219B
10CD6000FE137EB7200D2DCDA71BC23C1B07070766
10CD7000C3731A216F137EFE2828342E357E360B9E
10CD8000FE052802360321FE13CDDA1B20047907A5
10CD900018DB7E06DDFE582807FE5906FDC23C1B47
10CDA00021341336022C7E702CC62077C31A191634
10CDB0003021FE13CDC11DC23C1B82772C71C31ED6
10CDC000197EFE5806DD2805FE5906FDC021FB131D
10CDD0004E2C7EB7280CC601C0B1F02E357E702CCB
10CDE000BFC9B1F818F5CDE51CCD4A1A2042CDEFE8
10CDF0002A2821CD5C2BC2911E21FB13462C7EB725
10CE000028043CC2911E2E3436022C7EC646772C56
10CE100070C31A1921FE137EB720072DCDA71BC39F
10CE2000731A216F137EFE28C23C1B1606C3B11D68
10CE30002135133609CDEF2AC23C1B21FE137EFE9D
10CE40005816DD2806FE59203216FD21341336020D
10CE50002C46722C70CD5B2D20372135137E2EFE93
10CE6000FEDD2811CDF61B202879070707072E368F
10CE70008677C31A19CDE21BC3671EFE4C2012CD64
10CE80005B2D200D21FE13CDDA1B20057907C36D24
10CE90001D21341336022C2C3600C39C1BCDE51CFF
10CEA000CD4A1ACAEE1DCDEF2AC23C1B21FE137ECD
10CEB000FE4CC23C1BCD5B2DC23C1B21FE13CDDAC8
10CEC0001BC23C1B2E3436022C7E36EDFE980642E9
10CED0002802064A2C70C3691ECDE51CCD4A1AC231
10CEE0003C1BC3EE1D11FB13EB4E2C462E53712C35
10CEF00070EB160E7EFE283E00C814C9216F13CDBC
10CF0000A5242EFE7EB7201A2D7E1604FE52281070
10CF100015FE49280B15CDA71BFE06C815300115B7
10CF2000BFC9CDDA1B20153E058157CDB1247EFE49
10CF30002820073E06BAD8148257AFC9FE581609F2
10CF4000280114CDB1247EFE2820EF160BCDCD1D77
10CF5000C02137137118E32139133601C9CD5C2B79
10CF6000C4571F216F13CDE51E1825CD662DC4575C
10CF70001F219513CDE51E1831CDE91CCD441ACAE9
10CF80009F1CCDEF2A20D6CDFC1EDA6720C4571F88
10CF9000217C10722307070777CD5B2D20CD2195CB
10CFA00013CDFF1EDA6720C4571F217D10B6772BE3
10CFB0007EFE03300C82FE043E00380B7AFE0F2802
10CFC000067E07070707B24F210410062705CA6728
10CFD0002023237E23B920F53E26904756235E2149
10CFE0003613732D72160278FE20D25B2015FE1BBD
10CFF000D25B201604FE07DA0E200E37FE0F300239
10D00000150D2E535E2C7E69732C77C35B20FE06B4
10D01000CA192015FE02DA2E202E97FE04DA2220ED
10D020002E717E2E35FE58280236FD2C180616026B
10D03000B720011545217D107E261368B6772C791F
10D04000E60FFE0F2015B1EA4B202C4D2EFC7EB7CB
10D0500028043CC4571F2EFB5E69732E39AFB62ED1
10D0600034722003C3E818AF213613772C772C775E
10D07000C39F1CCD762D2806CD1822C35E212158D2
10D08000137EFE0830F22E5B7EB728ECCD4A1AC222
10D090005B212E581E4954010800EDB0CD5C2BC217
10D0A0005B212149131E5854010800EDB021FB13E8
10D0B0001E2E54010200EDB0CD6E28201BCD891A22
10D0C0002006CD2D22C35E21216013541E2E0E0298
10D0D000CD6F2420EDC35E21CDD828C35E2121640D
10D0E000137EB7C41822CD441AC43922CD911A2018
10D0F0002E21F9133604CD512921F82411201501D0
10D100001E00EDB02A2C13222813ED432C13CD6200
10D1100026211713113215010500EDB0CDE32A21A8
10D12000B722CDF72D000000CD4421CDE0DFFE5920
10D13000F54FCDE6DFF1CA5419217B107EB7CACA7C
10D1400027C35C22215313224913224B13000000F2
10D1500000C9000000CD4A1ACA6321CD39221E0839
10D16000C3F718CD5C2BC25B2121FB134E2C461E4E
10D1700008213013712C702E6A7EE6020F2EF8778C
10D18000C3F718CDD81CCD4A1A20442E6F7EFE2737
10D19000202C2C7E541E35120622132C7EB7282FED
10D1A000FE27280B1205F29A21CD412204180523EF
10D1B0007EB7201B3E23902E34774FAF1843CD5CB3
10D1C0002B200CCD1022200721351371C3E618C384
10D1D0007E1ACDE11CCD4A1AC29C1BCD5C2BC29C91
10D1E0001B21FB13462C7E2E35C32B1DCD4A1A283E
10D1F00008CD39221E04C3F718CD5C2B20F3CD10C7
10D2000022472E307E2C814F7E88471E04C3712119
10D2100021FB134E2C7EB7C9162121FA13723A7BDB
10D2200010B720062A3213221B15C35129162218C3
10D23000E9162318E5162418E1162518DD16261818
10D24000D9162718D52100312E00247E47AF77BE8E
10D250007028F7B7010D00ED42227E10CD1D2E2162
10D2600007130E103E30CD9F2421C322CDF72DCDC4
10D270004421CDE0DFFE51C84FCDE6DF79217B10A0
10D28000FE313601CA2619FE4F3600CA3619FE5045
10D290003602CACB1818D2000000000000000000BF
10D2A000000000000000000000000000000000007E
10D2B000000000000000000D0A4C494E4B3F2028A2
10D2C0005929000D0A415353454D424C45520D0A10
10D2D000504153533A20200000000000000000009D
10D2E00000000000000000002100150664482B36F5
10D2F0000010FB0663040D2823CD012EE67F00FEFF
10D300000C28F6FE0D2815FE0A2811FE1E280DFE1B
10D310000920023E20770528DC2318DD361E21FA7D
10D3200023362C21F1233620211E24363B21422492
10D33000362716640E47219C1406007EFE3BCA3138
10D3400024FE1E200A78B7204E216413361EC9FE23
10D3500020200678B72040181CFE3A20130E0678CD
10D36000B7C4BF23444DC602215813776069181A09
10D37000FE3B280504237E18C878B7201AEB2164E9
10D380001336202C363BEBC32D2406FF04237EFEF0
10D3900020202278B728F6EB0E04216E132D3620BC
10D3A0000D20FAEB78B728060E0553CDBF237EFE7D
10D3B0001EC82B1832FE1E28DEFE3B20CF18D8CD0B
10D3C000A5247D906F30012578B930014806005AB8
10D3D0001613EDB07BCDB1245F78B9C9EB36002BC5
10D3E0007EFE2028F8EBC9166F0E2606FF04237E6A
10D3F000FE20200478B728F67EFE2C2020545D21E4
10D40000FA23360021F12336002195133620626B72
10D41000166F78B7C4BF2316950E2718CEFE3B2093
10D420001C78B7C4BF23DCDC237EFE3BC016BC0ED9
10D430003C2B06FF04237EFE1E20F918E4FE1E2866
10D44000E0FE27200CAF32FA23321E243242241889
10D450009CFE2720983E3B321E241891FE40D8C6E1
10D46000F9C9E60F0707070777C9E60FB677C94678
10D47000EB78BEC023EB230D20F5C97E0F0F0F0FF5
10D48000E60FF630FE3AD8C607C97E18F3FE3AD04A
10D49000573E2FBA7AC9FE5BD0573E40BA7AC97759
10D4A000230D20FBC95D7C21BD24702371237323D0
10D4B0007721BD2446234E235E23666BC9000000FE
10D4C00000415353454D424C455250524F544F4BDF
10D4D0004F4C4C42465A20202020202020204F42F2
10D4E0002E434F4445202020205A45494C452020BA
10D4F0002020205155454C4C50524F4752414D4DE4
10D5000020454E544841454C542020202A2A2A20A8
10D510004645484C4552204845583D3D44455A21D2
10D5200028132D7EFE2028FAFE48CAA825000000F8
10D5300000000000000000FE42CA3726FE44200121
10D540002D7DFE1C3054CD9D25C847CD9C25C8B7E8
10D55000280778C60A471D18F7CD9C25C8B71600BE
10D56000280B78C664477ACE00571D18F3CD9C254A
10D57000C8B7280B78C6E8477ACE03571D18F3CDF5
10D580009C25C8B77A280D78C610477ACE27573819
10D59000091D18F12E28702C77C9AFC92D7ED63001
10D5A00038F8FE0A5FD8AFC97DFE1C30ED2DCDBF27
10D5B00025C8432DCDBF25C82E28702C731810CD3B
10D5C000D325C85F2DCDD325C807070707835F3E46
10D5D00001B7C97ED63038C2FE0AD8D607FE0A384F
10D5E000B9FE10D8AFC90000000000000000000024
10D5F000000000000000000000000000000000002B
10D60000000000000000000000000000000000001A
10D61000000000000000000000000000000000000A
10D6200000000000000000000000000000000000FA
10D6300000000000000000CD4726C847CD4726C89F
10D640002E28702C770CC90E08AF572D7ED630DAF5
10D650009A25FE02D29A25C6FF7ACE000F0D20EA47
10D660000CC9212913562D462116130E0078D61009
10D67000477ADE275738030C18F378C610477ACE5E
10D6800027CDC52678D6E8477ADE035738030C182D
10D69000F378C6E8477ACE03CDC52678D664477AB4
10D6A000DE005738030C18F378C664477ACE00CDF5
10D6B000C526CDCE26C60A477ACDC5263E30802C5B
10D6C000772C3644C95779C6302C770E00C978D6E6
10D6D0000A47D80CC3CE262129135E2D46211B13E1
10D6E00036482DCDEC262D43CDEC26C978E60FCD5E
10D6F00000277778E6F007070707CD00272D77C9C1
10D70000C630FE3AD8C607C9E5210013732C722C27
10D71000712C702CC1702C712C772106137E2D4E2C
10D720002D46C52D462D4E2D562D5EE1C9210614E0
10D730007EB7CC442821F8137EB7C27C272E347ED6
10D74000B7C821071436352105145E1C1C732E063C
10D7500036022E076E542613CD0328212E13CD77C3
10D7600027210814347EFE40CC9027210714342151
10D77000341335C24727C934C02334C92130135468
10D780001E2E010200EDB02106147EFE02C2C1274A
10D79000210814541E12CD03282E0836002E0636FA
10D7A00001CD14282E046EC54ECDE9DFC15D2E05D6
10D7B0006E2C2C2C7DBBCABE276B2CC3A727CD4457
10D7C00028212F13111414C309282106147EFE02E8
10D7D000CC90270E3ACDE9DF0E1E06150000CDFADB
10D7E00027CDF627CDF627CDF62700000000000054
10D7F000000000C35C22063216003E304ACDE9DF4D
10D8000010F8C946EB2CC3EC264BCDDA265901049F
10D8100000EDB0C921121406007ECD5C24E60F078E
10D820000707074F2C7ECD5C24E60FB180472D5DA6
10D830002E057EBB28056B2C2C18DEAF90475413A9
10D8400013C30428CDF627210814AF0E07CD9F245B
10D85000361E2C36202C363A2E0636012E140E0695
10D860003E30CD9F242E0536182E043611C921597D
10D87000131E05462C560E087A175778173002EEFD
10D8800031470D20F32C561D20EC21FF1370682624
10D89000127EB7281F256E6711581346EB7EB828F5
10D8A0001678C603300114835F300114EB7E2366C3
10D8B0006FB420E4F601C9234EEB237EB9EB200EB2
10D8C0000520F4EB23116013010200EDB0C904043C
10D8D000EB230520FCC3AD28212E13541E6001024A
10D8E00000EDB021FF136E26127EB72856256E6715
10D8F0007EC604300124856F3001247E2BB62806B5
10D900007E23666F18EAEB210014010200EDB021BE
10D9100000145E2C562158134E0C0600EDB0216009
10D9200013010400EDB0210014732C722A7E107CC8
10D93000BA280AD01628CD1A22C9C300007DBBDA46
10D940003429C9EB2100147E2C666FEB7225731805
10D95000C421F9137EFE01CABF2AFE02CAA72AFE0D
10D9600004CADB29FE08CA022AFE10CAA729FE2023
10D97000CA9929FE40CA8829FE80CABF29C9C3D4D2
10D980002D00000000000000CD7E2921C124111FC0
10D9900015011200EDB0C3E32A21D324110A1501A9
10D9A0002D00EDB0C3E32A2104153E3D0E4BCD9F63
10D9B00024211725110815010800EDB0C3E32A2121
10D9C0003413111315462CCD7B244FEB712CEBCD6A
10D9D0008A244FEB712C2CEB0520EB212E13541EC7
10D9E00028010200EDB0CDD726211713110715012C
10D9F0000400EDB0CD6226211713110C15010500AE
10DA0000EDB0212A13541E28010200EDB0CD62268C
10DA1000211713112015010500EDB02164137EFEBE
10DA20003B2862FE202866B728111127150606CD6F
10DA30009B2A28030520F8626B363A216A13112EBF
10DA4000150605CD9B2A28030520F8216F131133F5
10DA500015CD9B2A20FB2195137EB7280AEB362C87
10DA60002CEBCD9B2A20FB21BC13EB3E47BD38029B
10DA70002E47EB063CCD9B2A28697BFE703064055F
10DA8000C2752A185E1127150648C3752A2C7EFE1A
10DA90003B20A821471511BC1318D77EB7C84F2CBF
10DAA000EB712CEBF601C9212A131E285401020048
10DAB000EDB0CD62262E17112015010500EDB02125
10DAC0002C133420022C34210C25110415010B00D9
10DAD000EDB021FA13CD7B244FEB712CEBCD8A24D2
10DAE0004FEB71C3A22D00000000000000000021D8
10DAF0006F13CDA5240625CD372CC0CDB124CD691B
10DB00002CCAAF2BCDB1247EFE2820012CCDA5241C
10DB1000CD532C0405CAAF2B05281A05282D05283E
10DB20002ACDB12401020011FD13EDB07EB7C8FE6D
10DB300029C02C18F7CDB1242C2C7EFE2920E2EB35
10DB400021FD13364D2C3600EB18E121FB13360076
10DB50002C3600CD212BC8CDA5241819216F13CD4B
10DB6000A52406257EFE27285ACD372CC0CDB1240A
10DB7000CD692C283D21FB1336002C3600CDB12475
10DB8000CDA5247EFE28282E0600FE2D200104218E
10DB9000021470CDB1247EFE2D2821FE2B281DFEFF
10DBA000232835CD2B2CDA7F2CCD312CDA0B2DF61A
10DBB00001C9CDB1242C2CCDA52418B92CCDA52478
10DBC0007E18DC2C11FB13010100EDB0EB3600EBED
10DBD0007EFE27C02C7EB7C92CCDA524212E134E46
10DBE0002C462102147EB72807AF914F3E0098477C
10DBF00021FB137E81772C7E8877CDB1247EFE2B8E
10DC0000CA802BFE2DCA802BFE2920022C7EB7C095
10DC10002103147EB7C8FE48280721FC133600AF45
10DC2000C921FC137E36002D77AFC94ACD96245109
10DC3000C94ACD8D2451C90E007EFE28280BFE292D
10DC4000280D2C0520F379B7C90C0DC00C18F30D65
10DC5000C018EF562C5E218010061405C87E234E96
10DC600023BA20F779BB20F3C97EFE482804FE4C76
10DC700020054F2C7EFE282103143600C071C92CCC
10DC80002C7EFE2ECAED2C2132131E5954010200A7
10DC9000EDB0CDB1241E5B547ECD2B2CD2AF2B0129
10DCA0000100EDB0CDCC2C2034CDCC2C2030CDCC0F
10DCB0002C202CCDCC2C2028CDA5243E07902158FB
10DCC0001377CD6E28C0216013C3DF2B7ECD2B2CA4
10DCD000D4312CD2AF2B010100EDB0AFC904040444
10DCE00004EB4836002C0D20FAEBC3B82CCDB12440
10DCF0001E5954010100EDB07ECD2B2CD4312CD215
10DD0000AF2B010100EDB02CC3952C1E175401114F
10DD100000EDB0CDB1241E175406117ECD2B2CD4AE
10DD2000312C302A2C1C0520F2CDA5242117137E7E
10DD3000FE30200E1E1854EB011000EDB0EB362023
10DD400018EACD1F25CAAF2B212813C3DF2BEB36D2
10DD5000202C0520FAEBCDA52418D1219513CDA5B3
10DD6000240626C3F72A3ABB13B7C0219513CDA5C5
10DD7000240626C3642B21641306047ECD2B2CD2EB
10DD8000AF2B2C7EB7280CCD2B2CD4312CD2AF2B23
10DD90000520EF78FE0338082E64CD532C0405C906
10DDA000AFC9210415C5F5018000E5097E2BFE20D1
10DDB00028FAE5D1E1E5EBED52450404E14ECDEC66
10DDC000DF2310F92104153E20770180001105158D
10DDD000EDB0F1C1C50E0DCDECDF0E0ACDECDFC10B
10DDE000CDEFDFE6C0C0D90DD9C0D90E0ED9CDE038
10DDF000DFFE20C8C35C227EB7C84FCDE6DF231804
10DE0000F6CDEFDFE60FC2E3DFD97DB420030000DB
10DE1000007E2BCB77C41A2ED9C9CBAFC9D92A30F3
10DE20000D0E0ED9C9000000000000000000000027
10DE300000000000000000000000000000000000E2
10DE400000000000000000000000000000000000D2
10DE500000000000000000000000000000000000C2
10DE600000000000000000000000000000000000B2
10DE700000000000000000000000000000000000A2
10DE80000000000000000000000000000000000092
10DE90000000000000000000000000000000000082
10DEA0000000000000000000000000000000000072
10DEB0000000000000000000000000000000000062
10DEC0000000000000000000000000000000000052
10DED0000000000000000000000000000000000042
10DEE0000000000000000000000000000000000032
10DEF0000000000000000000000000000000000022
10DF00000000000000000000000000000000000011
10DF10000000000000000000000000000000000001
10DF200000000000000000000000000000000000F1
10DF300000000000000000000000000000000000E1
10DF400000000000000000000000000000000000D1
10DF500000000000000000000000000000000000C1
10DF600000000000000000000000000000000000B1
10DF700000000000000000000000000000000000A1
10DF80000000000000000000000000000000000091
10DF90000000000000000000000000000000000081
10DFA0000000000000000000000000000000000071
10DFB0000000000000000000000000000000000061
10DFC0000000000000000000000000000000000051
10DFD0000000000000000000000000000000000041
10DFE000C3E000C3E300C3E600C3E900C3EC00C321
10DFF000F20000000000000000000000000000002F

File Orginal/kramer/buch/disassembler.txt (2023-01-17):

10180000CDC704C103DDE1110000DDE5E17D917C80
1018100098D0193AFF0FFEC0C4900AD93E03CD46B6
101820000A1E00DD7E00FEDD20041E801806FEFD7F
10183000200A1EC0DD7E0208DD2318E721ED08FE28
10184000ED2813FECB2018CBC32E7ECB7B280BDDDF
1018500023DD7E0118092E9E1E20DD23DD7E00572C
10186000CB7E2328FB7AAE23A62320F4CDEA09CD34
10187000420ADD23D918937A0F0F0FA1C9FDE900A1
10188000C07B02F440C042495402682CF480C0522C
10189000455302682CF4C0C053455402682CF440F0
1018A000C71A03F641C71B02F642CF1F02122CEBE8
1018B0004ACF1D02122CEB4BCF016B0A70A943CF0C
1018C0000128700BEB44C74E45C74DCF08C945CF23
1018D00008CE46FF0DB056FF0DB15EFF0DB247E7D3
1018E00001F867F777C4A0E46AFA00002AF276FFED
1018F00048414CD440C001762CF406C701762CEF49
1019000002E701F93AFF01410A70A932FF0128708C
101910000BC101CF016B2CF02AFF01750A70A922BF
10192000FF0128700BF5F9FF01132CF5F5FF058475
10193000C5CF05EBF1FF0684C1CF06EB20E74A5285
101940007E20F118FF4A5203F110FF444A4E5A20FC
10195000F1CDFF07F0C4C743417D20F0C9FF88C027
10196000C752FDE9FF4A4D5020ED04C669F609CF84
101970001C02752CEB03CF16EB0BCF17EB80C07F4F
1019800002F4C6C77F02EFC3FF4A4D5002F0C2C740
101990000C7D20F0EBFF09112C92D9FF4558D80897
1019A000FF455884E3FF0928130BF507E77CC1DBEB
1019B000FF1A03306FC8D3FF1B02306FC827FF44E4
1019C00041C12FFF19CC3FFF4343C6F3FF44C9FB7E
1019D000FF45C937FF5343C6C7C7525354026CC8AB
1019E00000FF4E4FD0E1CB7E23C07EE5E67F21E5B0
1019F00009E5FE203850FE60384A0E07C6893807D0
101A0000212A0A856F6EE9213B0B856F6ECD770821
101A10003CCB7E2328FB3D20F818CF2AA1A6B14B52
101A20006567546A793342CBADC6CD7708C5CD958D
101A3000041865CB7B2806DD7EFECD4E0A6A26EDB6
101A4000184E3E1E185021430B18C57AE638C5CDF6
101A5000B504C1C9DD233E30CD960ADD7E00CD4EF2
101A60000A3E481831AF08791864DD23DD23CD9D87
101A70000ADD6600DD6EFF1817DD23D9D5D9E1DD5B
101A8000E5C10923CD9D0A0A4F170600300105095B
101A9000C5CDB004C1C9C54FCDEC00C1C93E4D187C
101AA000F521720B180321800B7AA1189C3E0218B5
101AB00004CD77081F216E0BFE02208DCB7B28EB17
101AC000C602CB7328E5CD770818017A3CA1CB7B01
101AD0002827CB43204FFE05381F477AEE70E67863
101AE000283D7AEE46E6C7283678B92004CBCBDD10
101AF00023C603CB732802C60321E80BCD100ACB03
101B00004BC8CB8B08B72813473E2BF2140B78ED4C
101B100044473E2DCD960A78CD4E0A3E291880784E
101B2000B928CA18D4F579CDED0AF1B9C8477AEECB
101B300040E640C8AFCD460A7818BE9ADCCCABA3CD
101B40009FBCB6892681188320A002A041C65055AB
101B50005348A0504F508243414C4CA05245D4456D
101B600058832CA829AC4AD0494D8352CC52D2423A
101B7000C344C548CC53D049D849D91A43821143EC
101B8000824CC443D049CE4F55D44144C44144C390
101B90005355C25390414EC4584FD24F52A019A032
101BA000FBFB8E8F0EC30FC30EA00FA0534CC1536F
101BB00052C1534CD3538EC9C449D244D24EDA5A7F
101BC000A04EC343A050CF50C550A04DA028100B2D
101BD000C1410A10A928110BC1410A11A9492CC100
101BE000522CC1412CC9412CD2C1C2C3C4C5C8CCDE
101BF0002812A948D84CD8289448D94CD92895FF00

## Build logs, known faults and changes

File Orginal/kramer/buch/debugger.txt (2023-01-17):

10140000F3E5D5C5F5DDE5FDE5ED57F508D9E5D5FD
10141000C5F5D90821180039060BEB21E40F2B7212
101420002B73D110F9C10BF921EB0F7E912320040E
101430007E98280C23237E912320047E9828010384
1014400021E50F7323722EE9712370C5CD21014070
10145000E1CDB00421EB0F16024EAF772346772380
1014600079B028027E02231520EFC34800D1C1F1D4
10147000DDE1FDE108D9F1ED47E1D1C1F1D908E1A4
10148000F9C3E40F237CB537C87B957A9CC9E34E3A
1014900023E3C3E900E60FC69027CE40274FC923B8
1014A0005E160F2346231ACDB50405F81B1A18053E
1014B0007CCDB5047DF50F0F0F0FCD9504CDEC005D
1014C000F1CD9504C3EC00CDD704E3E50D30032046
1014D00003C920F3C34100CD180528F8C521000039
1014E0004C47CD060538134779291729172917299D
1014F000174F78B56FCD0C0118E778CD1B0520D4B8
10150000E360E379C1C9D630D8C6E9D8C606F2147B
1015100005C607D8C60AB7C9CD0C01FE20C8FE2CE7
10152000C8FE0D37C83FC9C5CDE300CD0605070786
1015300007074FCDE300CD0605B14F825779C1C9EA
101540007CCD45057D5F0F0F0F0FCD9504CDE900D4
101550007BCD9504CDE9007B8257C9CD8E040DCD9E
101560008E040AC9CDC704D1E1CDFB02CDB0040E73
1015700020CD02037ECDB504CD8404DAFB027DE6E6
101580000F20EC18E40DCDC704CD8E043AAF57CD33
101590004505E1CD40053E01CD4505AF92CD450560
1015A000063CCD8E040010FAC90CCDC704C1D1E1B0
1015B00071CD840430FAC9216D04E3CD1805280AE1
1015C000CDDC04EB21EA0F722B733825110200CD1C
1015D00021012DCDD704E51438061D20F2D241009B
1015E00021EB0FC1712370230A77233EFF021520E0
1015F000F2C32D03CDC704CD2D03D1E1E519CDB044
1016000004CDFD01E1B7ED52C3B0040CCDC704C158
10161000D1E17E0203CD6D00CD840430F5C90DCD3E
10162000C704CD2D03CDE300FE3A20F9AF57CD27F7
1016300005282F5FCD270567CD27056FCD27054BE3
10164000E52100FF39CD270577231D20F8CD27059B
10165000C24100D1E3EB19060009EBE32B1BEDB807
1016600018C321EA0FCD2705772BCD270577E1C9D0
10167000CDD704D87ECDB504CD21012DCD1805D808
101680002807EBCDDC04EB73D82318E8CDC704069C
1016900000D1E1E57DACA877CD840430F7E17DACE5
1016A000A8BE2057CD840430F5C9CDC704CD2D0385
1016B000D1E1CD8E043A011000E5040D2805CD845A
1016C0000430F7E1D5160078CD4505CD4005AFCD06
1016D00045057ECD45052310F9AF92CD4505D12BAB
1016E000CD5B05CD840430CAC90CCDC704C1D1E19E
1016F0000ABE200703CD840430F6C9CD2D03CDB03A
1017000004C9215707CD180538370E0BBE28092309
1017100023230D20F7C34100CDFD01CD9F04CD2132
10172000012DCD1805D82810E5C5CDDC047D12F1BA
10173000B7FA3707137C12E1AFB6F878FE0DC81878
10174000DACD2D03CDFD01AFB6F84ECDE600CD21AB
10175000013DCD9F0418ED41D30042D10043D0009C
1017600044CF0045CE0046D20048E6004CE5004D8F
10177000E60150EA0153E301FF218607CD18053841
10178000C00E0BC30C0741E10042DF0043DE004402
10179000DD0045DC0046E00048DB004CDA0049D9BA
1017A0000058D50159D701FFFFFFFFFFFFFFFFFFE3
1017B000FFFFFFFFFFFFFFFFFFFFFFFFFFFFFFFF39
1017C000FFFFFFFFFFFFFFFFFFFFFFFFFFFFFFFF29
1017D000FFFFFFFFFFFFFFFFFFFFFFFFFFFFFFFF19
1017E000FFFFFFFFFFFFFFFFFFFFFFFFFFFFFFFF09
1017F000FFFFFFFFFFFFFFFFFFFFFFFFFFFFFFFFF9

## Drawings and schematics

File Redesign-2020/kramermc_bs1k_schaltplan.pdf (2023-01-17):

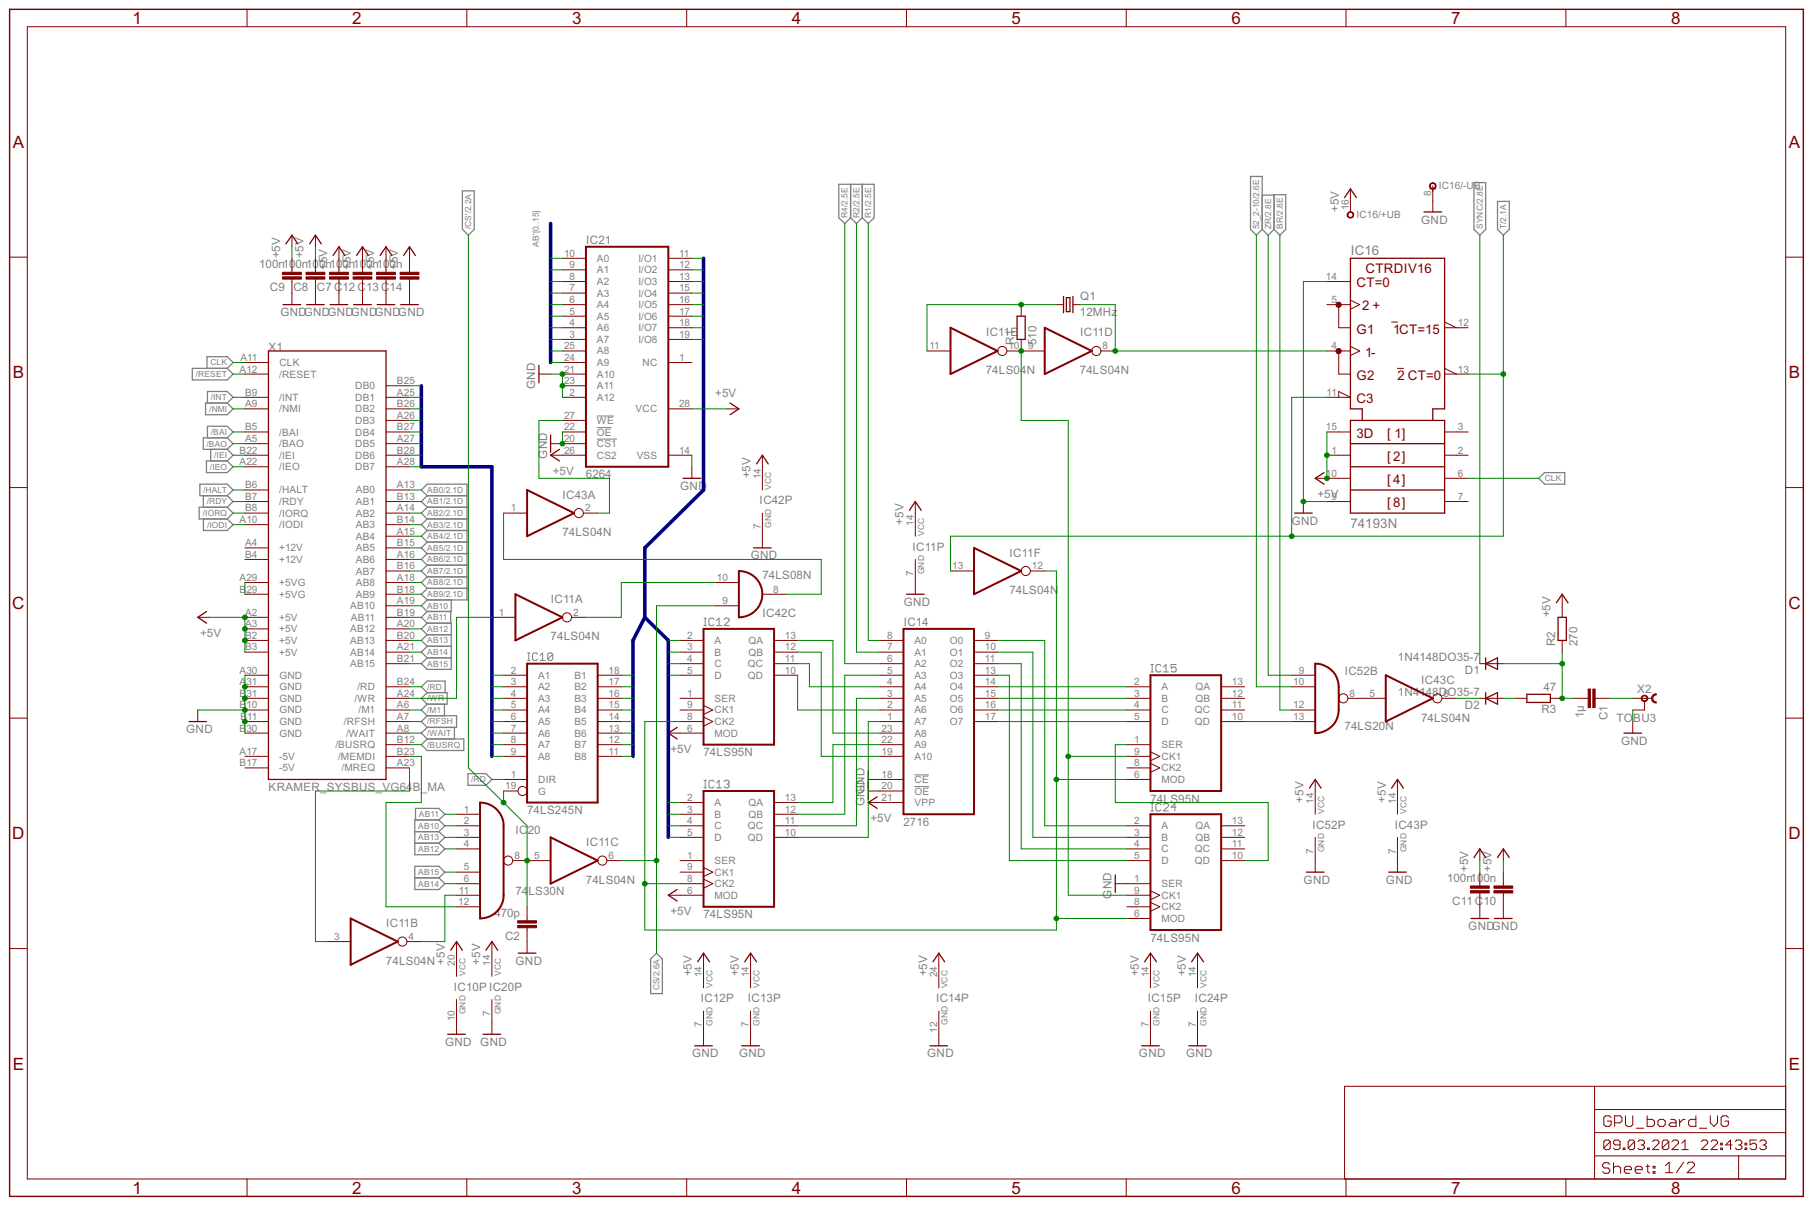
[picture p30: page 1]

1µ 470p +5V GND KRAMER_SYSBUS_VG64B_MA 100n+5V GND 100n+5V GND 100n+5V GND 100n+5V GND 6264 74LS245N 2716 74LS95N 74LS95N 74LS95N 74LS95N 74193N 12MHz 510 74LS04N 74LS04N 74LS04N 74LS04N 74LS04N 74LS04N 74LS30N 74LS20N 74LS08N 74LS04N 74LS04N 270 47 1N4148DO35-7 1N4148DO35-7 TOBU3 +5V GND GNDGND GND +5V GND GND +5V +5V +5V +5V GND GND +5V +5V +5V +5V +5V +5V +5V +5V +5V +5V +5V GND GND GND GND GND GND GND GND GND GND +5V GND GND 100n+5V GND 100n+5V GND 100n+5V GND 100n+5V GND +5V GND C1 C2 GND A30 GND A31 GND B31 +5VG A29 DB7 A28 DB5 A27 GND B10 +5VG B29 DB6 B28 DB4 B27 DB3 A26 DB2 B26 DB1 A25 /WR A24 /MREQ A23 /IEO A22 DB0 B25 /RD B24 /MEMDI B23 /IEI B22 AB14 A21 AB15 B21 AB12 A20 AB10 A19 AB8 A18 -5V A17 AB13 B20 AB11 B19 AB9 B18 -5V B17 AB6 A16 AB7 B16 AB4 A15 AB2 A14 AB0 A13 /RESET A12 AB5 B15 AB3 B14 AB1 B13 /BUSRQ B12 CLK A11 GND B11 /IODI A10 /NMI A9 /WAIT A8 /RFSH A7 GND B30 /INT B9 /IORQ B8 /RDY B7 /M1 A6 /HALT B6 /BAO A5 +12V A4 +5V A2 +5V B2 /BAI B5 +12V B4 +5V A3 +5V B3 X1C9 C8 C11 C10 IC21A0 10 A1 9 A2 8 A3 7 A4 6 A5 5 A6 4 A7 3 A8 25 A9 24 A10 21 A11 23 A12 2 WE 27 OE 22 CS1 20 I/O1 11 I/O2 12 I/O3 13 I/O4 15 I/O5 16 I/O6 17 I/O7 18 I/O8 19 VSS 14 VCC 28 NC 1 CS2 26 DIR 1 A1 2 A2 3 A3 4 A4 5 A5 6 A6 7 A7 8 A8 9 B8 11 B7 12 B6 13 B5 14 B4 15 B3 16 B2 17 B1 18 G 19 IC14A7 1 A6 2 A5 3 A4 4 A3 5 A2 6 A1 7 A0 8 O0 9 O1 10 O2 11 O3 13 O4 14 O5 15 O6 16 O7 17 CE 18 A10 19 OE 20 VPP 21 A9 22 A8 23 SER 1 A 2 B 3 C 4 D 5 MOD 6 CK2 8 CK1 9 QD 10 QC 11 QB 12 QA 13 SER 1 A 2 B 3 C 4 D 5 MOD 6 CK2 8 CK1 9 QD 10 QC 11 QB 12 QA 13 SER 1 A 2 B 3 C 4 D 5 MOD 6 CK2 8 CK1 9 QD 10 QC 11 QB 12 QA 13 SER 1 A 2 B 3 C 4 D 5 MOD 6 CK2 8 CK1 9 QD 10 QC 11 QB 12 QA 13 IC16 910115 3267 11514 12 4 13 Q1 R1 IC11A 1 2 IC11B 3 4 IC11C 5 6 IC11D 9 8 IC11E 11 10IC11F 13 12 IC20 123456 8 1112 9 IC52B 101213 8 IC42C 910 8 IC43A 1 2 IC43C 5 6 R2 R3 D1 D2 X2 IC16/+UB 16 IC16/-UB 8 IC11P GND VCC 7 14 IC42P GND VCC 7 14 IC20P GND VCC 7 14 IC12P GND VCC 7 14 IC13P GND VCC 7 14 IC14P GND VCC 12 24 IC15P GND VCC 7 14 IC24P GND VCC 7 14 IC52P GND VCC 7 14 IC43P GND VCC 7 14 C7 C12 C13 C14 IC10P GND VCC 10 20 AB'[0..15] CLK CLK /RESET /INT /NMI /BAI /BAO/IEI /IEO /HALT /RDY /IORQ /IODI /RD /RD /WR /M1 /RFSH /WAIT /BUSRQ AB15 AB15 AB13 AB13 AB14 AB14 AB0/2.1D AB1/2.1D AB2/2.1D AB3/2.1D AB4/2.1D AB5/2.1D AB6/2.1D AB7/2.1D AB8/2.1D AB9/2.1D AB10 AB10 AB11 AB11 AB12 AB12 /CS'/2.2A CS/2.6A R4/2.5E R2/2.5E R1/2.5E T/2.1A SYNC/2.8E BR/2.8E ZR/2.8E 52_2-10/2.6E CT=0[ 1] [ 2] [[ ]] 48 3DC3 1 G2 2 1G12-+ CT=0 CTRDIV16 CT=15 ABCDE 1 2 3 4 5 6 7 8 ABCDE 1 2 3 4 5 6 7 8

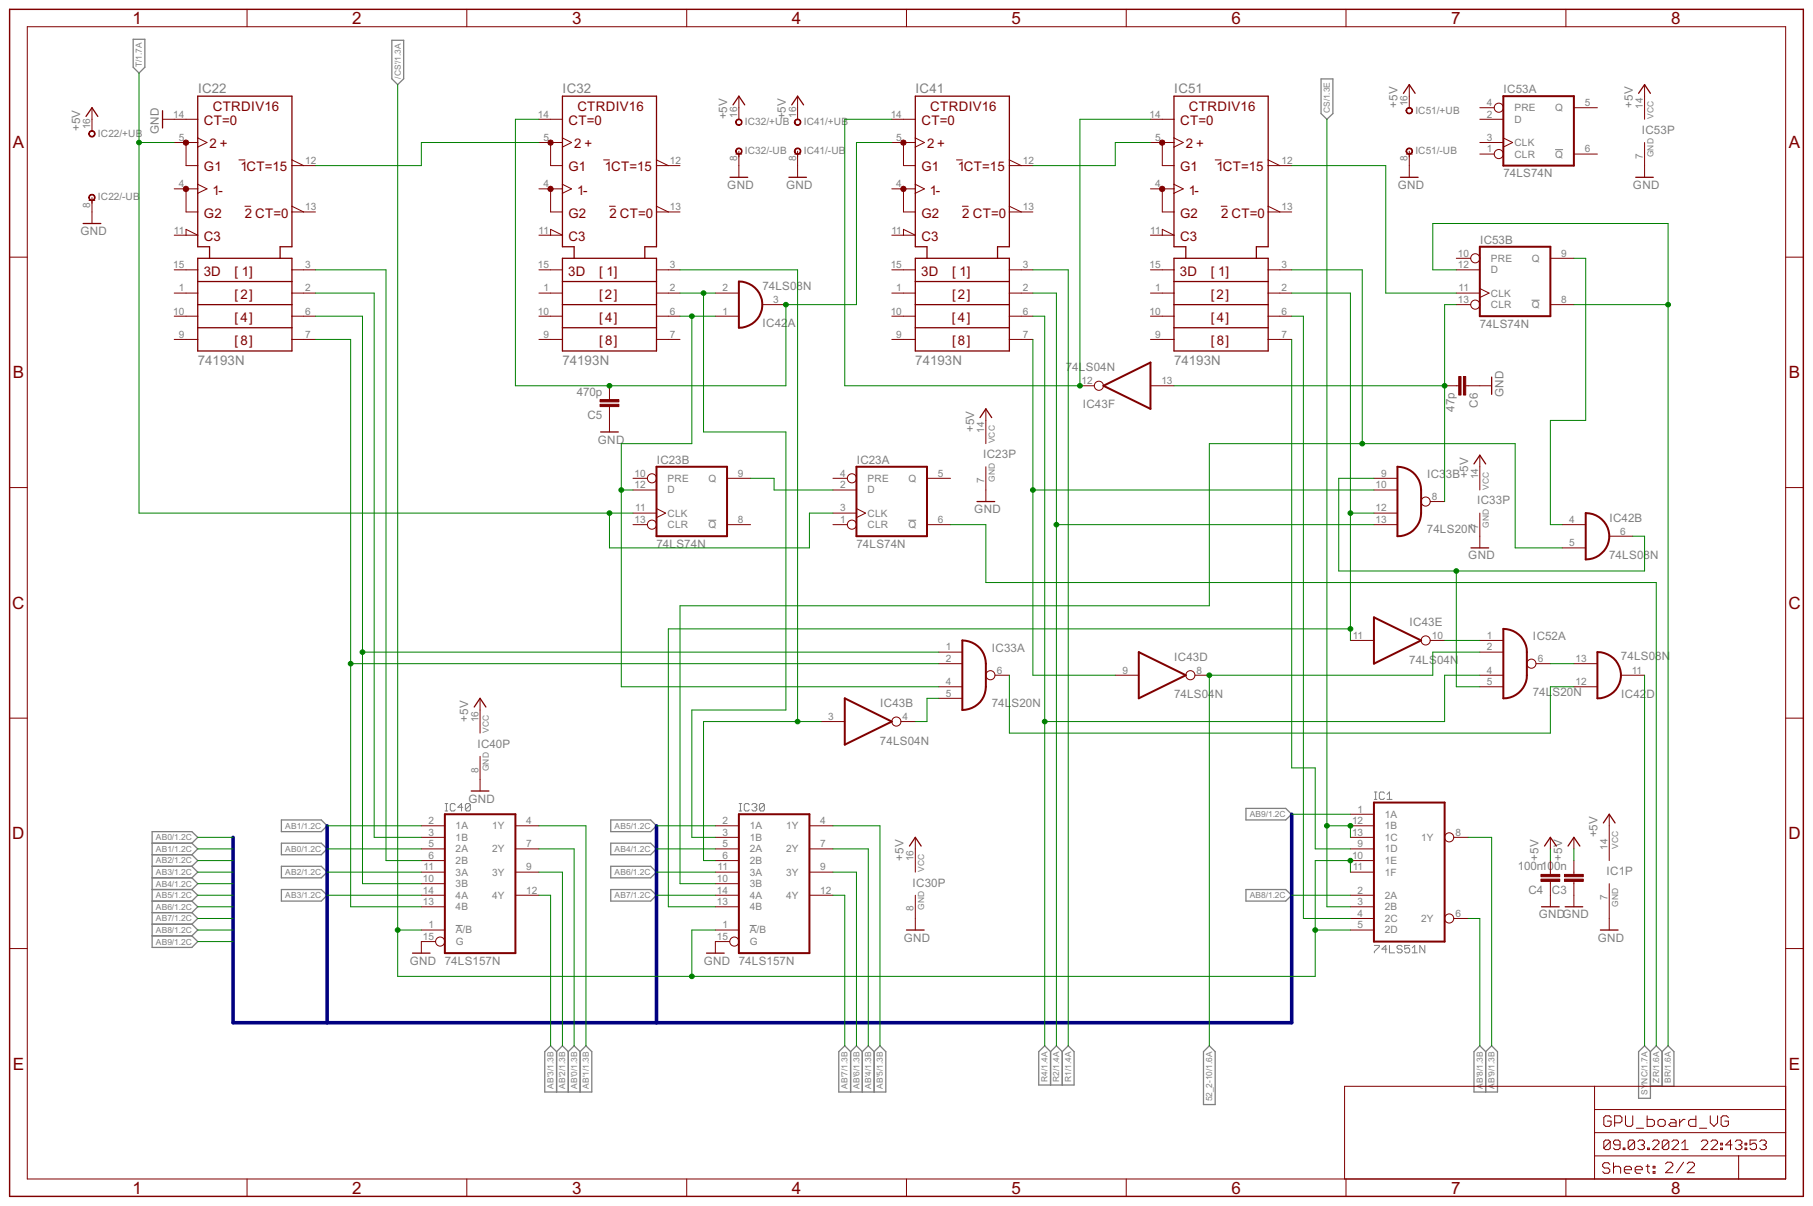
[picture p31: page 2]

IC40P GND | 4

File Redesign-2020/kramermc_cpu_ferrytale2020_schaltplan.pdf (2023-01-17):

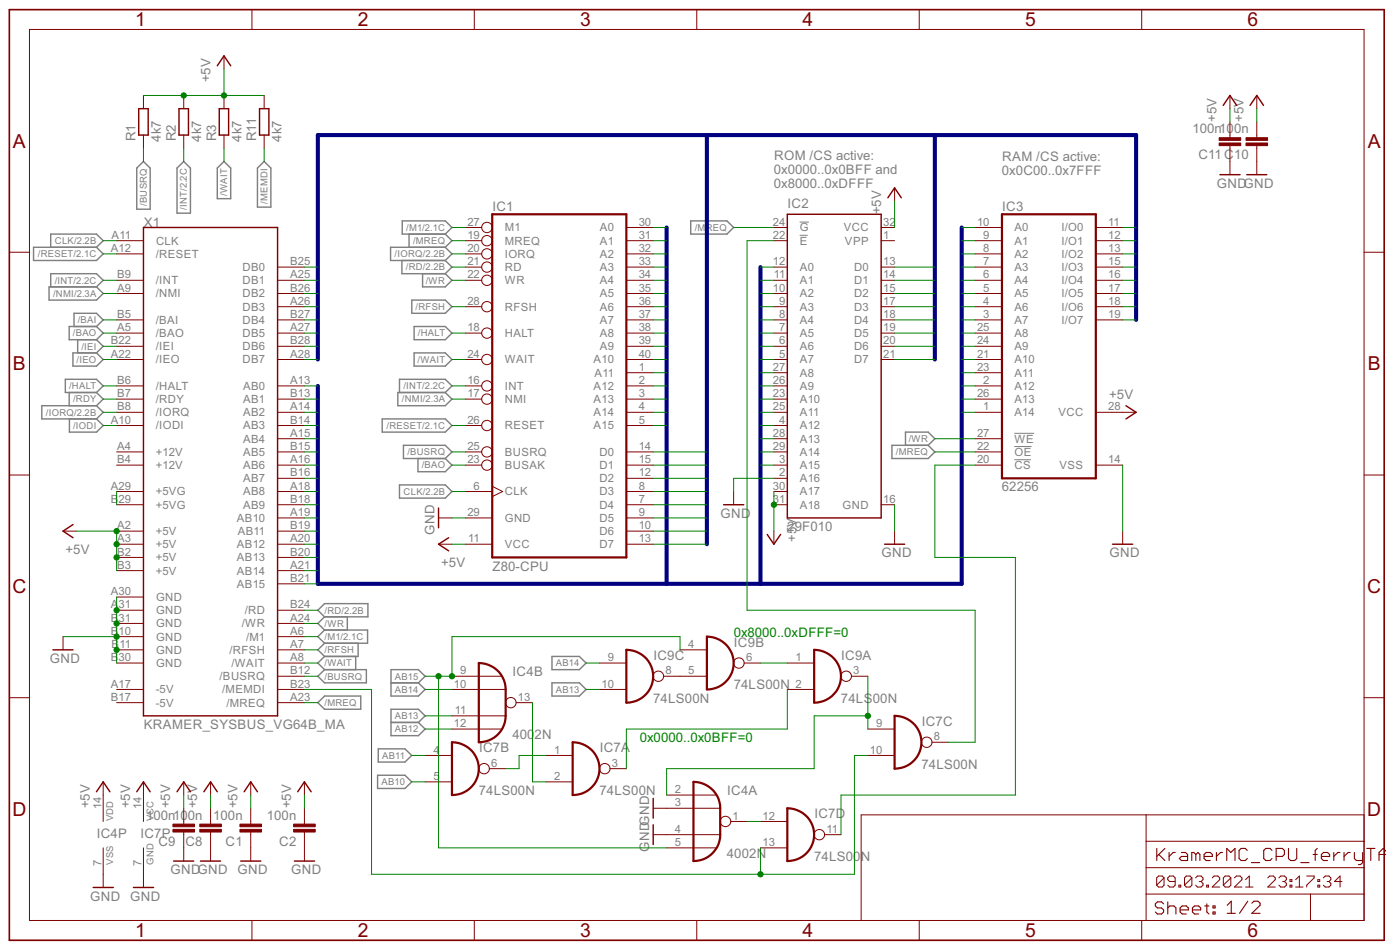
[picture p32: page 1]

ROM /CS active: 0x0000..0x0BFF and

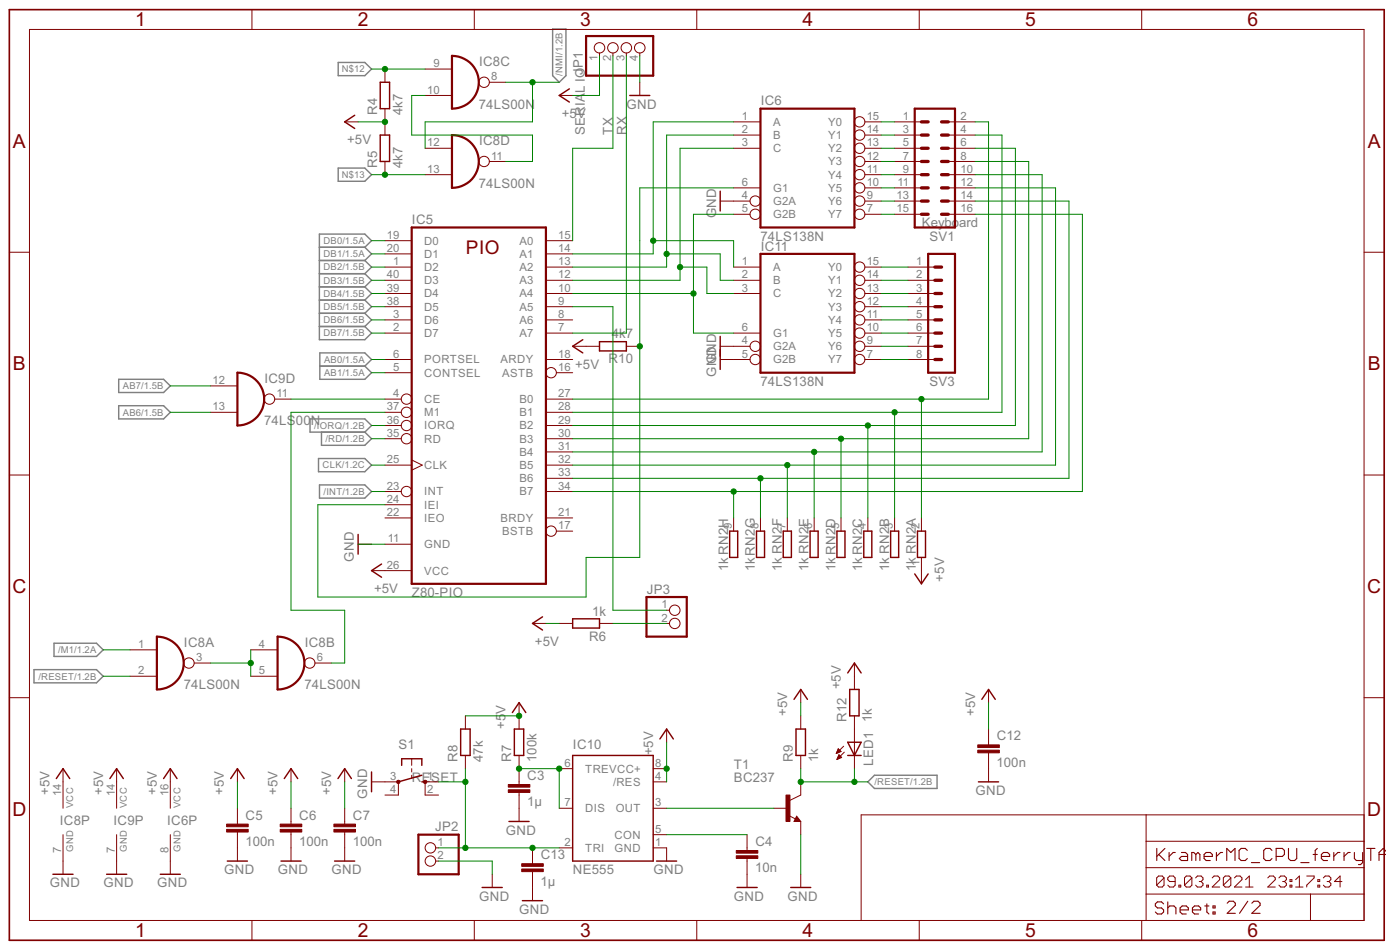
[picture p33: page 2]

SERIAL IO TXRX Keyboard RESET Z80-PIO 74LS138N 4k7 74LS00N 74LS00N 4k7 +5VGND +5V +5V GND74LS00N 74LS00N +5V GND GND +5V 1k1k1k1k1k1k1k1k +5V NE555 100k 1µ GND GND +5V +5V 10n GND 47k BC237 1k GND +5V +5V GND +5V GND GND 100n 100n 100n +5V +5V +5V GND GND GND 1k +5V 74LS00N 4k7 100n +5V GND 1µ GND 1k +5V GND 74LS138N GND GND IC5D0 19 D1 20 D2 1 D3 40 D4 39 D5 38 D6 3 D7 2 A0 15 A1 14 A2 13 A3 12 A4 10 A5 9 A6 8 A7 7 B0 27 B1 28 B2 29 B3 30 B4 31 B5 32 B6 33 B7 34 ARDY 18 ASTB 16 BRDY 21 BSTB 17 PORTSEL 6 CONTSEL 5 CE 4 M1 37 IORQ 36 RD 35 CLK 25 INT 23 IEI 24 IEO 22 GND 11 VCC 26 IC6A 1 B 2 C 3 G2A 4 G2B 5 G1 6 Y7 7 Y6 9 Y5 10 Y4 11 Y3 12 Y2 13 Y1 14 Y0 15 SV1 135 246 79 810 111315 121416 IC6PGND VCC 8 16 R4 12 IC8D 13 11 9 IC8C 10 8 R5 1 IC8A 2 3 4 IC8B 5 6 IC8PGND VCC 7 14 RN2A 1 2 RN2B3 RN2C4 RN2D5 RN2E6 RN2F7 RN2G8 RN2H9 IC10TRE 6 OUT 3 DIS 7 TRI 2 VCC+ 8 GND 1 CON 5 /RES 4 R7 C3 C4 R8 T1 R9 IC9PGND VCC 7 14 JP11234 JP2 12 C5 C6 C7 JP312 R6 12 IC9D 13 11 R10 C12 C13 R12 LED1 S1 3 1 4 2 IC11A 1 B 2 C 3 G2A 4 G2B 5 G1 6 Y7 7 Y6 9 Y5 10 Y4 11 Y3 12 Y2 13 Y1 14 Y0 15 SV3 12345678 DB0/1.5A DB1/1.5A DB2/1.5B DB3/1.5B DB4/1.5B DB5/1.5B DB6/1.5B DB7/1.5B AB0/1.5A AB1/1.5A /IORQ/1.2B /RD/1.2B CLK/1.2C /INT/1.2B /NMI/1.2B N$12 N$13 AB7/1.5B AB6/1.5B /M1/1.2A /RESET/1.2B /RESET/1.2B ABCD 1 2 3 4 5 6 ABCD 1 2 3 4 5 6 PIO

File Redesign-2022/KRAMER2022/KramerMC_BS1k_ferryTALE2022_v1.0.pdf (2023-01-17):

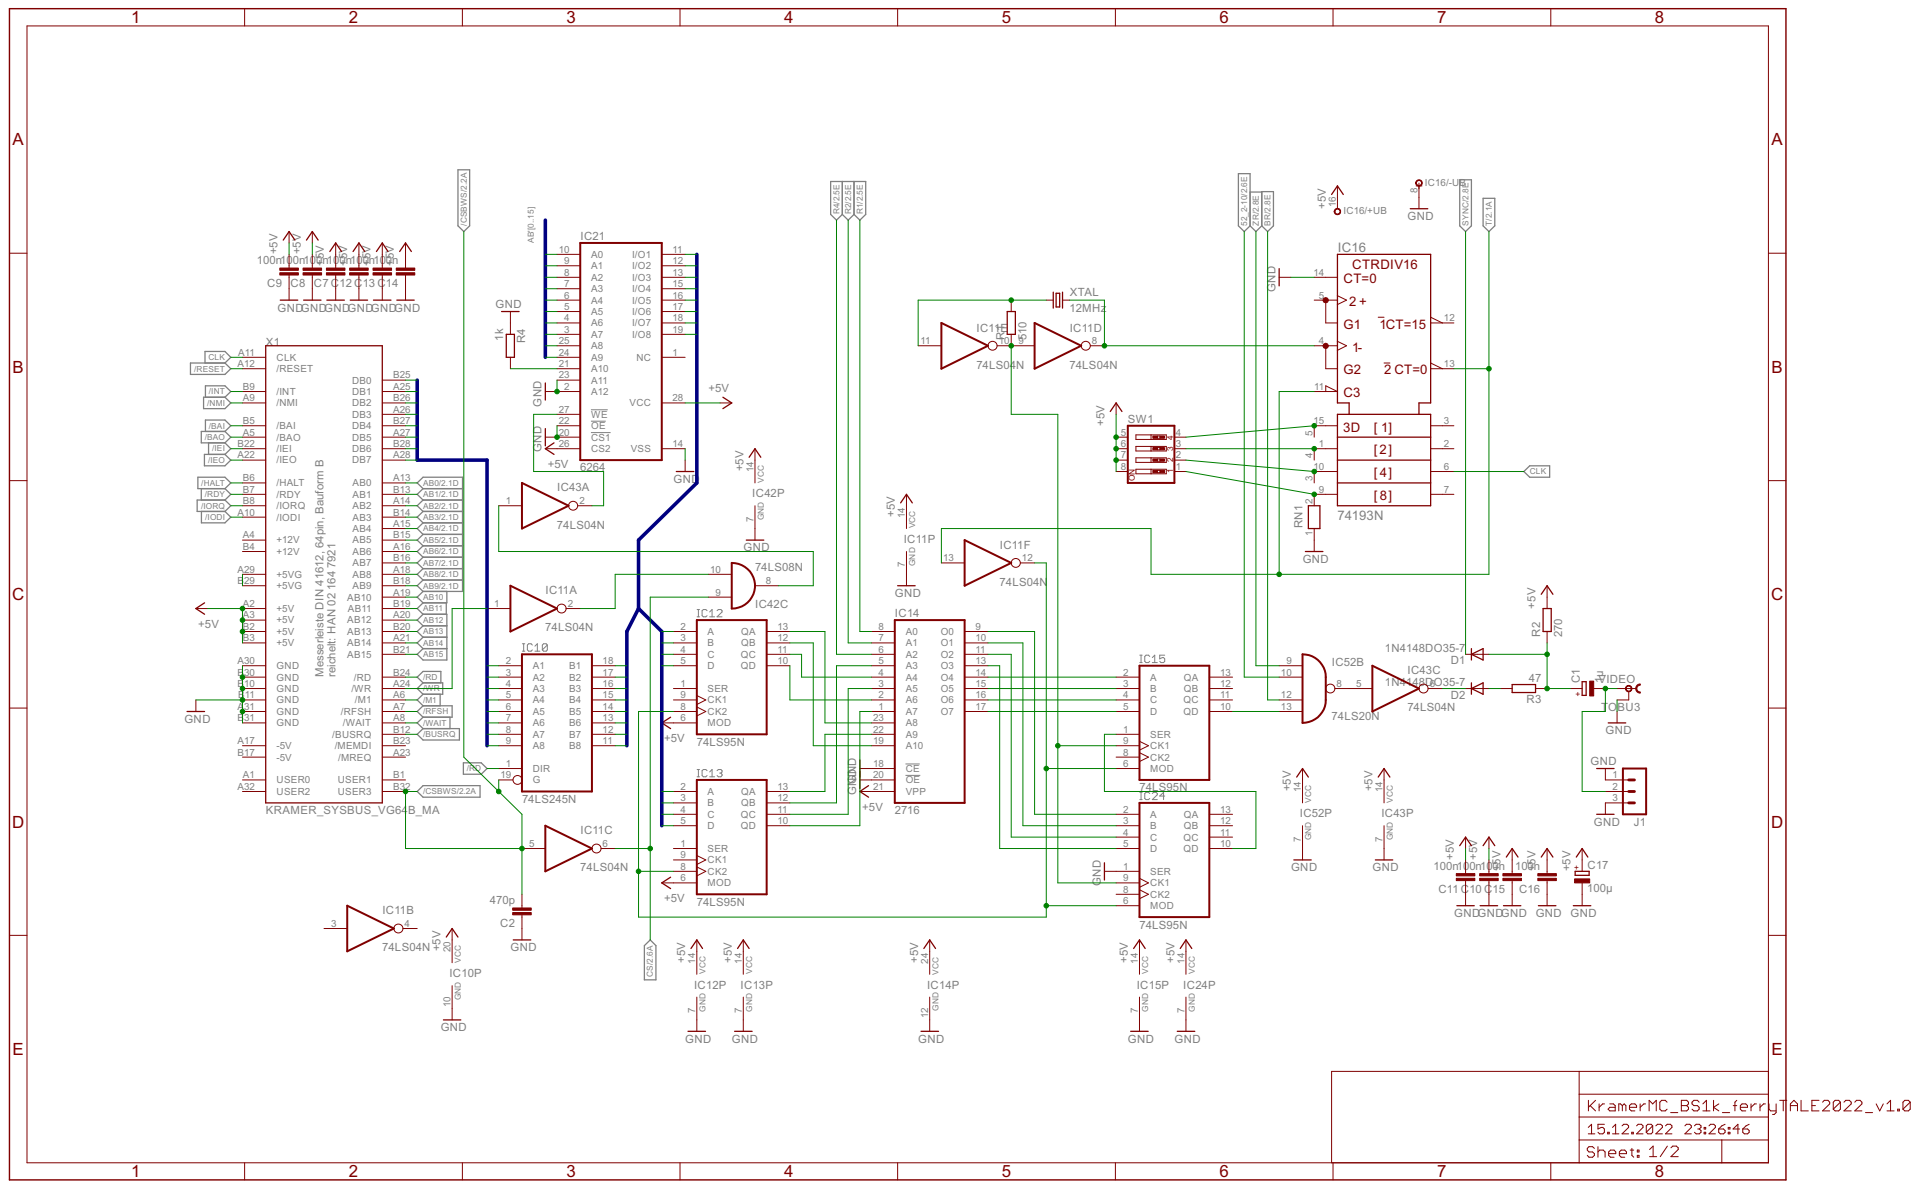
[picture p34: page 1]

Messerleiste DIN 41612, 64pin, Bauform B reichelt: HAN 02 164 7921 1µ 470p +5V GND KRAMER_SYSBUS_VG64B_MA 100n+5V GND 100n+5V GND 100n+5V GND 100n+5V GND 6264 74LS245N 2716 74LS95N 74LS95N 74LS95N 74LS95N 74193N 12MHz 510 74LS04N 74LS04N 74LS04N 74LS04N 74LS04N 74LS04N 74LS20N 74LS08N 74LS04N 74LS04N 270 47 1N4148DO35-7 1N4148DO35-7 TOBU3 GND GND GND +5V GND GND +5V +5V +5V +5V GND GND +5V +5V +5V +5V +5V +5V +5V +5V +5V +5V GND GND GND GND GND GND GND GND GND +5V GND GND 100n+5V GND 100n+5V GND 100n+5V GND 100n+5V GND +5V GND 100n+5V GND GND +5V 100n+5V GND 100µ +5V GNDGND GND GND 1k GND C1 C2 GND A30 GND B30 GND B10 +5VG A29 DB7 A28 DB5 A27 GND B11 +5VG B29 DB6 B28 DB4 B27 DB3 A26 DB2 B26 DB1 A25 /WR A24 /MREQ A23 /IEO A22 DB0 B25 /RD B24 /MEMDI B23 /IEI B22 AB14 A21 AB15 B21 AB12 A20 AB10 A19 AB8 A18 -5V A17 AB13 B20 AB11 B19 AB9 B18 -5V B17 AB6 A16 AB7 B16 AB4 A15 AB2 A14 AB0 A13 /RESET A12 AB5 B15 AB3 B14 AB1 B13 /BUSRQ B12 CLK A11 GND A31 /IODI A10 /NMI A9 /WAIT A8 /RFSH A7 GND B31 /INT B9 /IORQ B8 /RDY B7 /M1 A6 /HALT B6 /BAO A5 +12V A4 +5V A2 +5V B2 /BAI B5 +12V B4 +5V A3 +5V B3 X1USER0 A1 USER1 B1 USER2 A32 USER3 B32 C9 C8 C11 C10 IC21A0 10 A1 9 A2 8 A3 7 A4 6 A5 5 A6 4 A7 3 A8 25 A9 24 A10 21 A11 23 A12 2 WE 27 OE 22 CS1 20 I/O1 11 I/O2 12 I/O3 13 I/O4 15 I/O5 16 I/O6 17 I/O7 18 I/O8 19 VSS 14 VCC 28 NC 1 CS2 26 DIR 1 A1 2 A2 3 A3 4 A4 5 A5 6 A6 7 A7 8 A8 9 B8 11 B7 12 B6 13 B5 14 B4 15 B3 16 B2 17 B1 18 G 19 IC14A7 1 A6 2 A5 3 A4 4 A3 5 A2 6 A1 7 A0 8 O0 9 O1 10 O2 11 O3 13 O4 14 O5 15 O6 16 O7 17 CE 18 A10 19 OE 20 VPP 21 A9 22 A8 23 SER 1 A 2 B 3 C 4 D 5 MOD 6 CK2 8 CK1 9 QD 10 QC 11 QB 12 QA 13 SER 1 A 2 B 3 C 4 D 5 MOD 6 CK2 8 CK1 9 QD 10 QC 11 QB 12 QA 13 SER 1 A 2 B 3 C 4 D 5 MOD 6 CK2 8 CK1 9 QD 10 QC 11 QB 12 QA 13 SER 1 A 2 B 3 C 4 D 5 MOD 6 CK2 8 CK1 9 QD 10 QC 11 QB 12 QA 13 IC16 910115 3267 11514 12 4 13 XTAL R1 IC11A 1 2 IC11B 3 4 IC11C 5 6 IC11D 9 8 IC11E 11 10IC11F 13 12 9 IC52B 101213 8 IC42C 910 8 IC43A 1 2 IC43C 5 6 R2 R3 D1 D2 VIDEO IC16/+UB 16 IC16/-UB 8 IC11P GND VCC 7 14 IC42P GND VCC 7 14 IC12P GND VCC 7 14 IC13P GND VCC 7 14 IC14P GND VCC 12 24 IC15P GND VCC 7 14 IC24P GND VCC 7 14 IC52P GND VCC 7 14 IC43P GND VCC 7 14 C7 C12 C13 C14 IC10P GND VCC 10 20 C15 SW1 5678 1234 RN1 1 2 3 4 5 C16 C17 J1 123 R4 AB'[0..15] CLK CLK /RESET /INT /NMI /BAI /BAO/IEI /IEO /HALT /RDY /IORQ /IODI /RD /RD /WR /M1 /RFSH /WAIT /BUSRQ AB15 AB13 AB14 AB0/2.1D AB1/2.1D AB2/2.1D AB3/2.1D AB4/2.1D AB5/2.1D AB6/2.1D AB7/2.1D AB8/2.1D AB9/2.1D AB10 AB11 AB12 CS/2.6A R4/2.5E R2/2.5E R1/2.5E T/2.1A SYNC/2.8E BR/2.8E ZR/2.8E 52_2-10/2.6E /CSBWS/2.2A /CSBWS/2.2A + CT=0[ 1] [ 2] [[ ]] 48 3DC3 1 G2 2 1G12-+ CT=0 CTRDIV16 CT=15 ABCDE 1 2 3 4 5 6 7 8 ABCDE 1 2 3 4 5 6 7 8 1 2 3 4 ON +

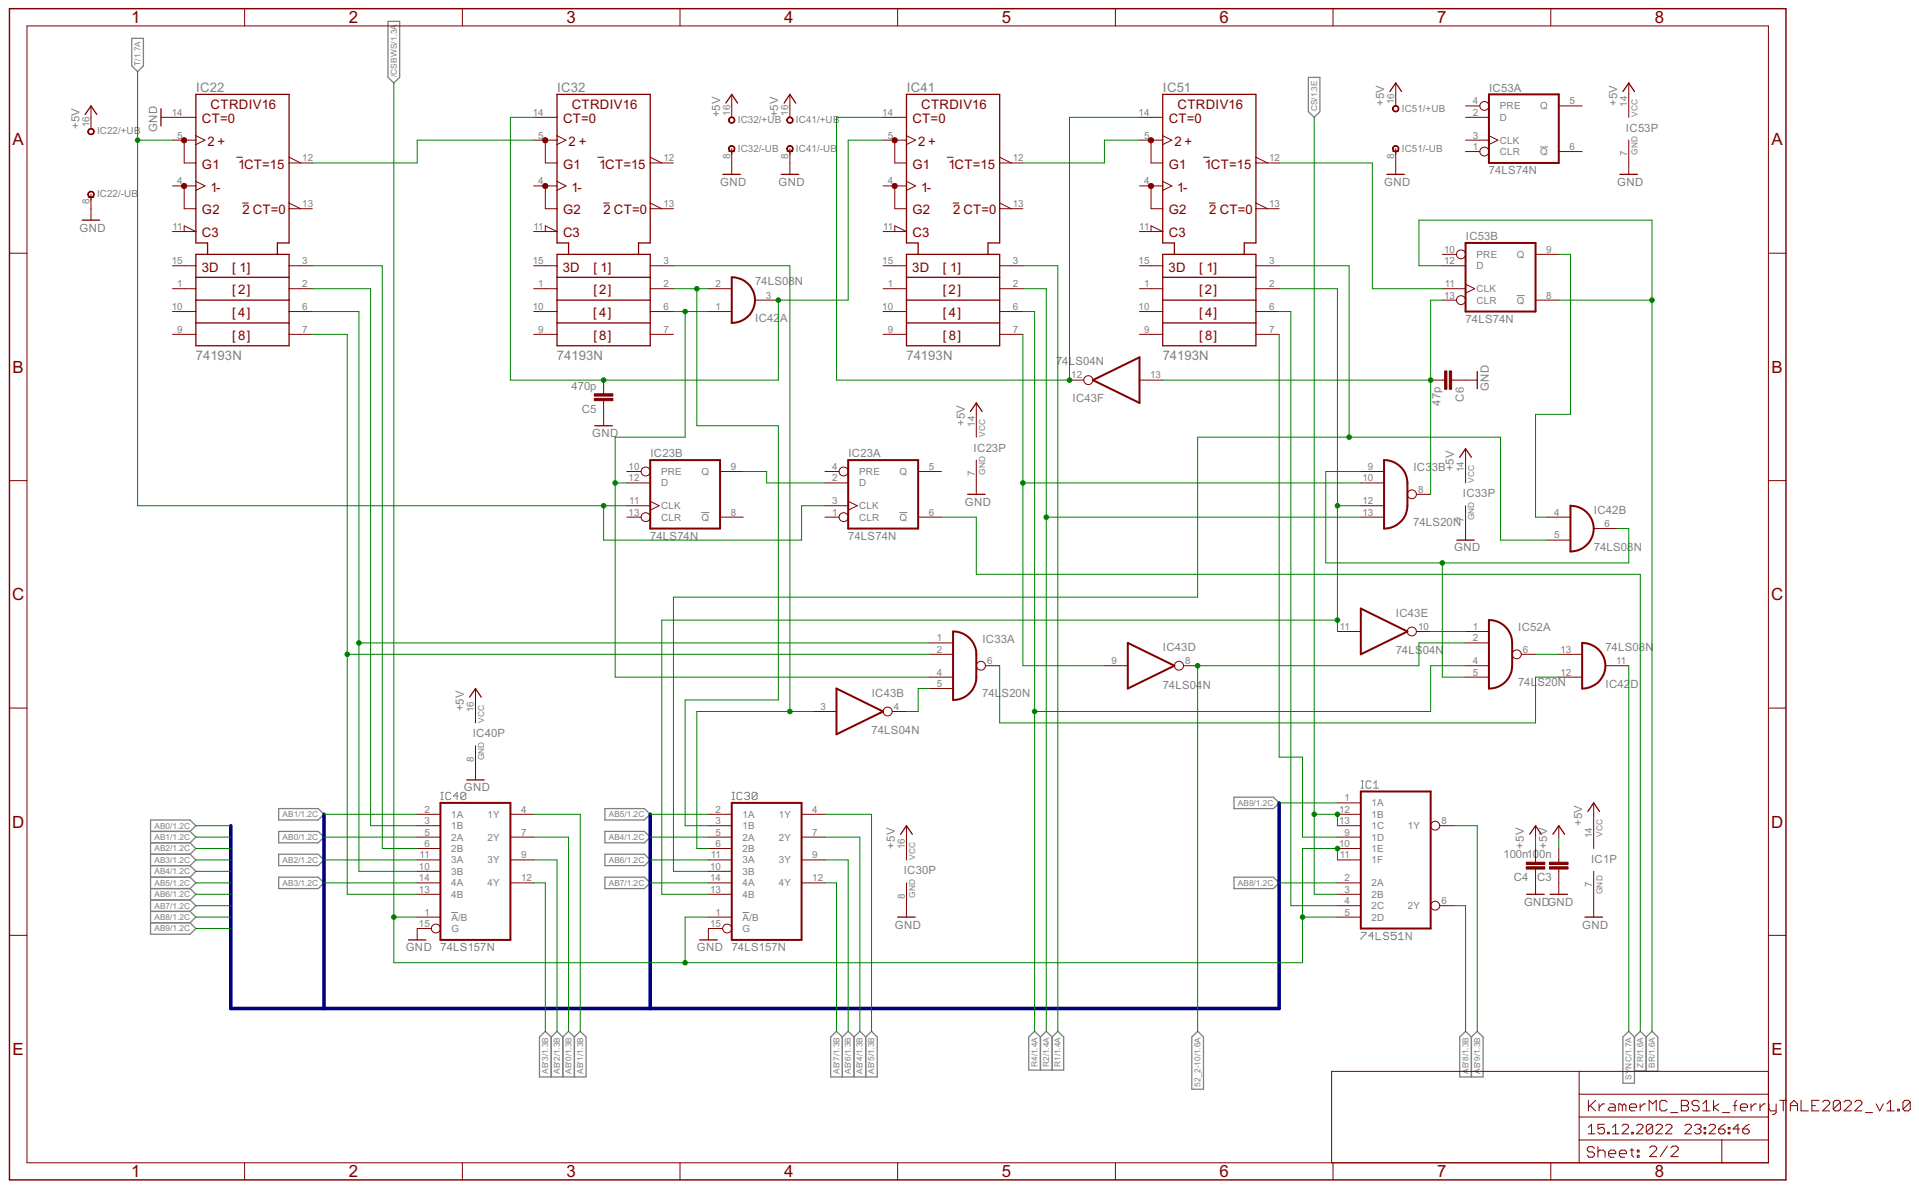
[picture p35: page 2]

IC40P GND | 4

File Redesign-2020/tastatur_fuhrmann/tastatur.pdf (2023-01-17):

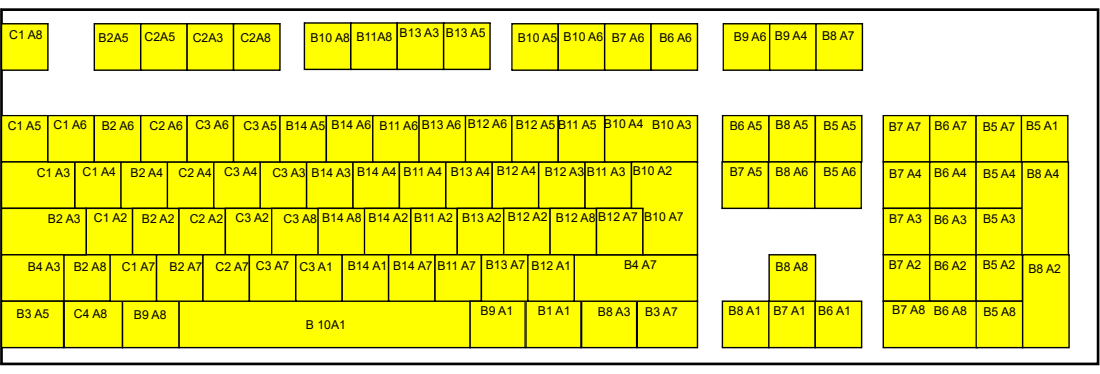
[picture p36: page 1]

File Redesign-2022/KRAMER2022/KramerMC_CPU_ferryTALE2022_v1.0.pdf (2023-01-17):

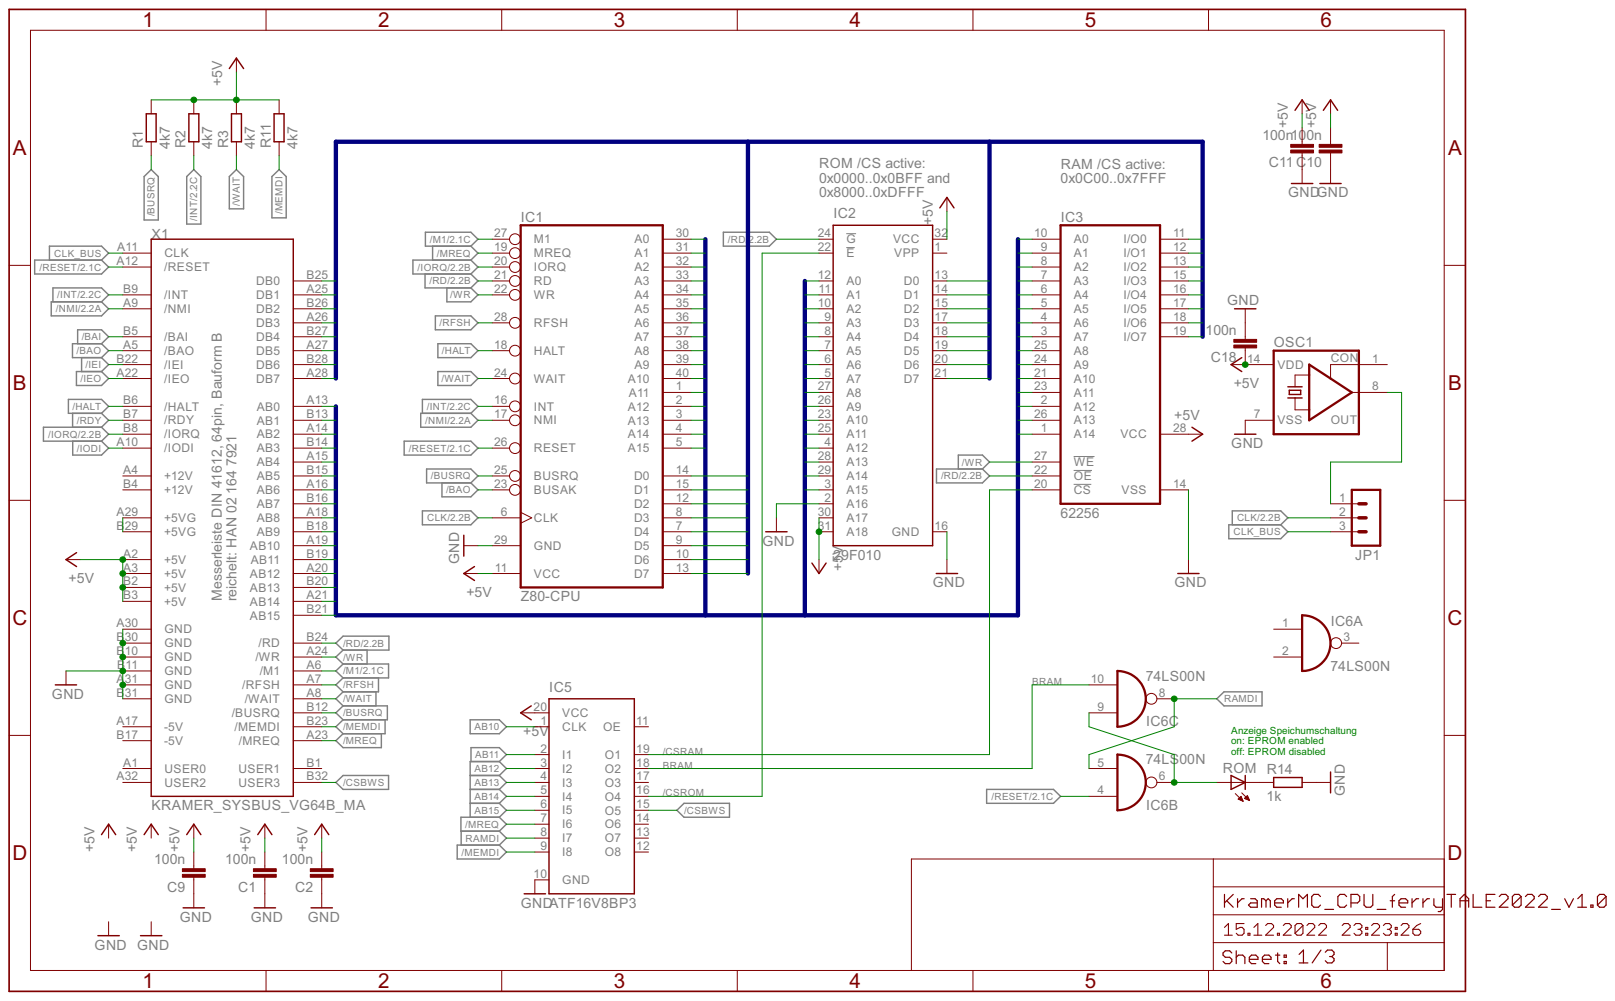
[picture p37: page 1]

ROM /CS active: 0x0000..0x0BFF and

9 D6
10 D7

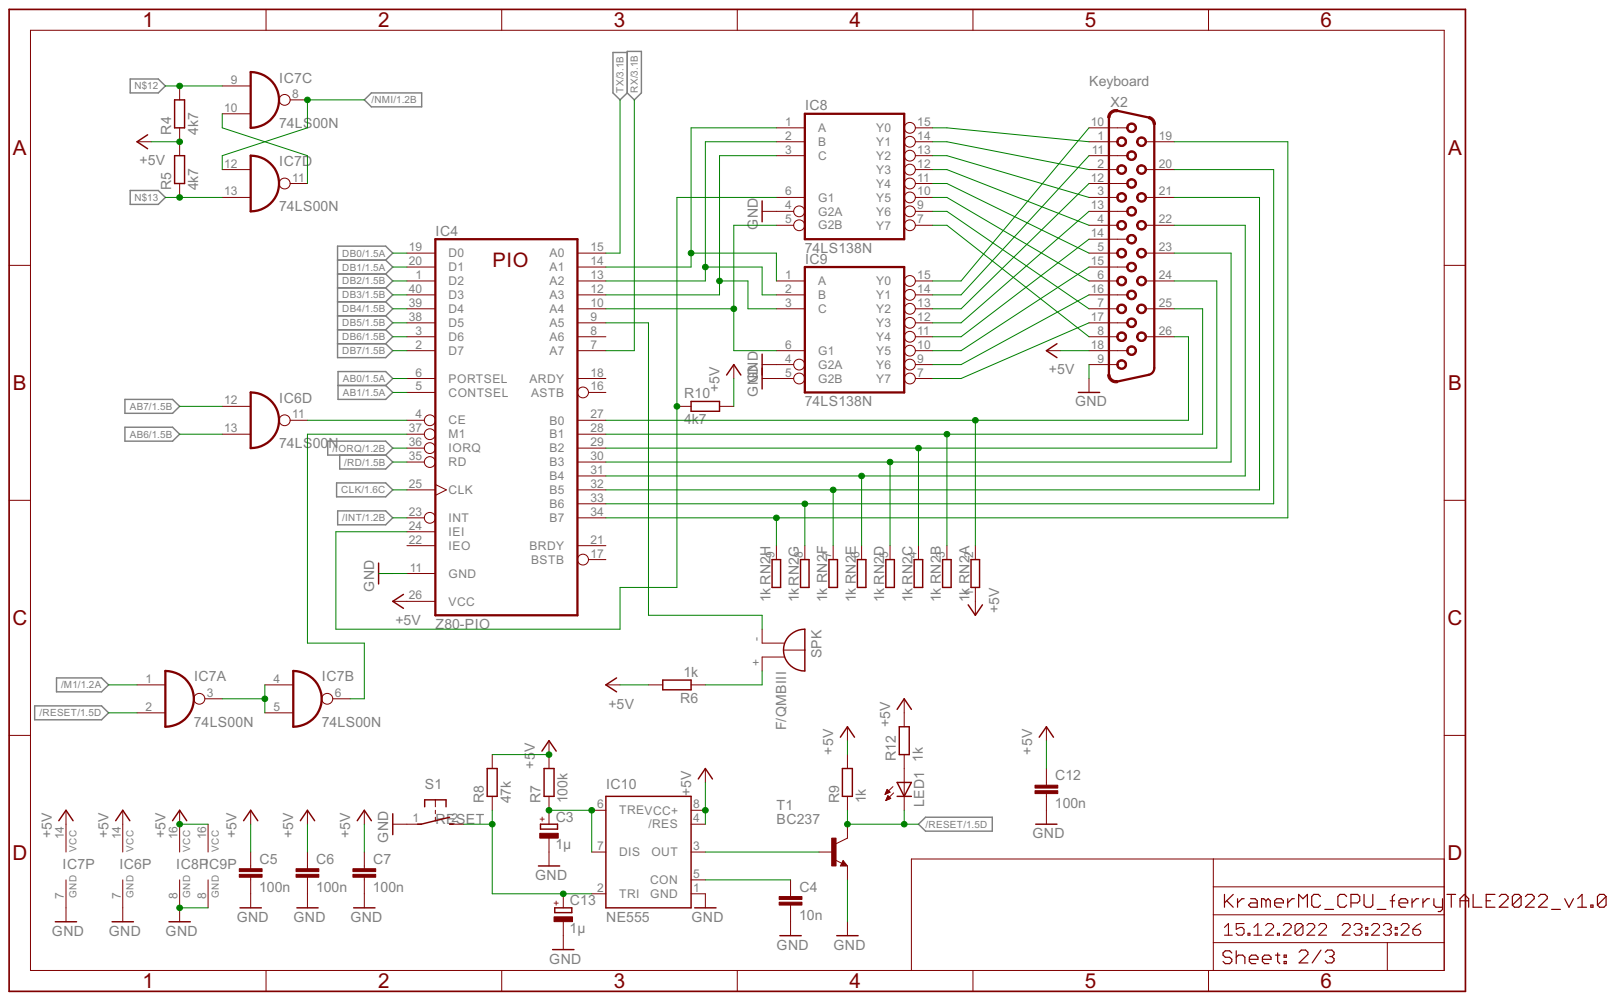
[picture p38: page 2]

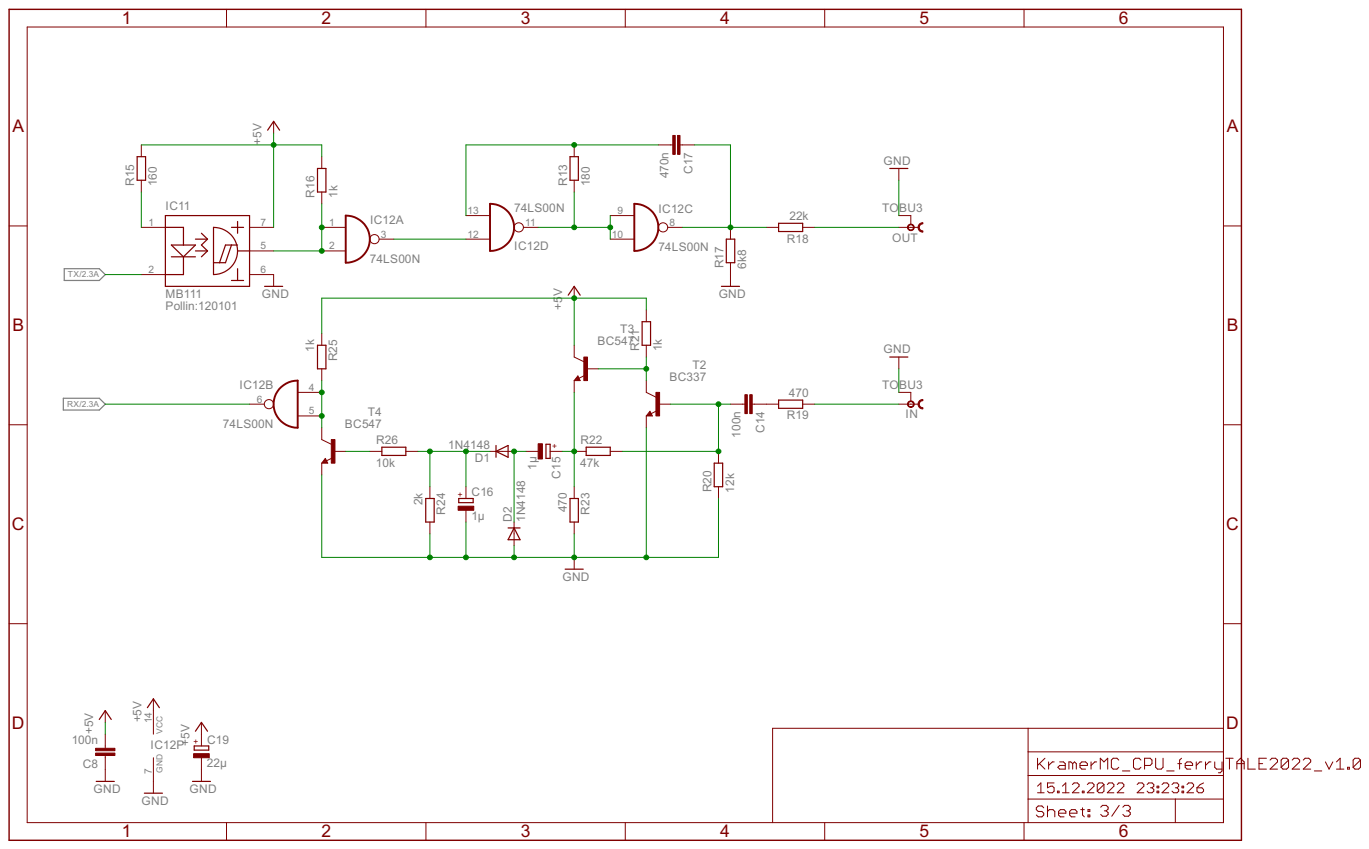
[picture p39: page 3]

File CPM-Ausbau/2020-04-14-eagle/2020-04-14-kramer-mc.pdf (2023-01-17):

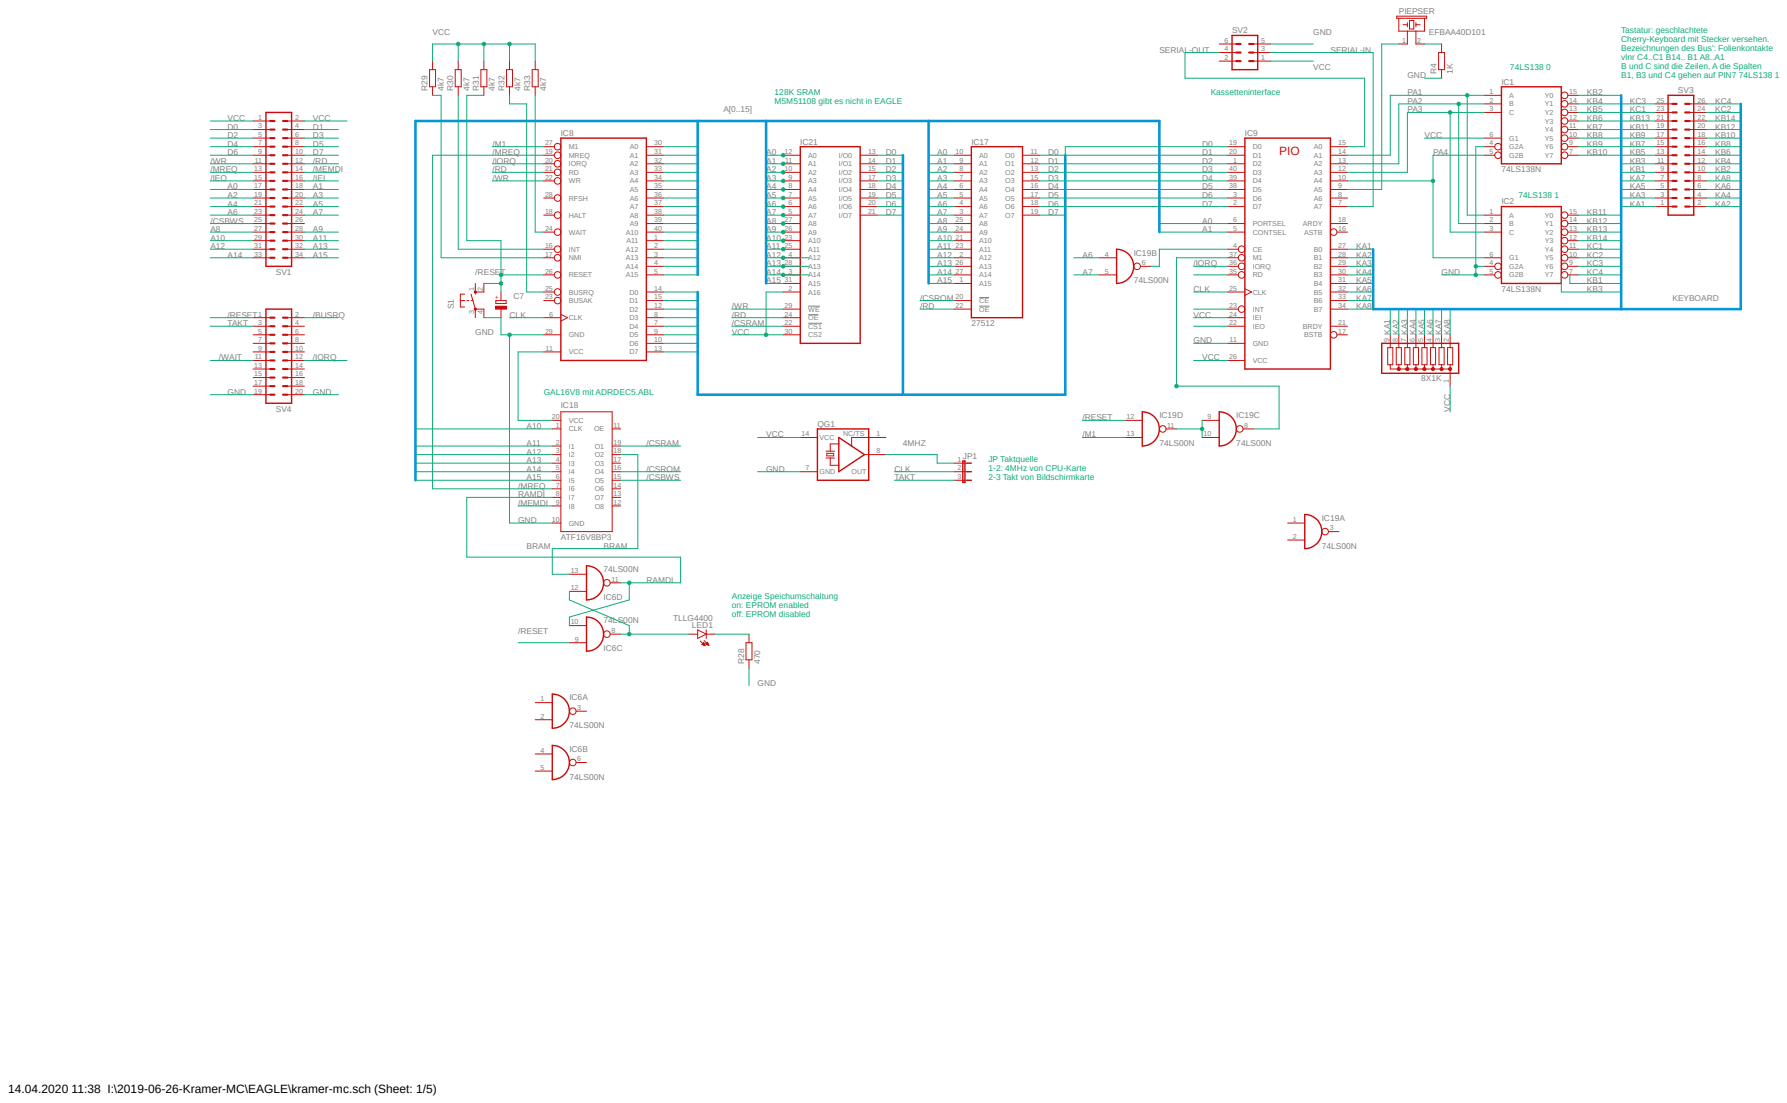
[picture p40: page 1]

Tastatur: geschlachtete
Cherry-Keyboard mit Stecker versehen.
Bezeichnungen des Bus': Folienkontakte
vlnr C4..C1 B14.. B1 A8..A1
B und C sind die Zeilen, A die Spalten
B1, B3 und C4 gehen auf PIN7 74LS138 1

M5M51108 gibt es nicht in EAGLE

PA2 | B 2
PA3 | | C 3

/M1 /MREQ | IC8 | IC21 | IC17

VCC | | | G1 6

A14
A15 | /CSBWS
/MREQ

14.04.2020 11:38 I:\2019-06-26-Kramer-MC\EAGLE\kramer-mc.sch (Sheet: 1/5)

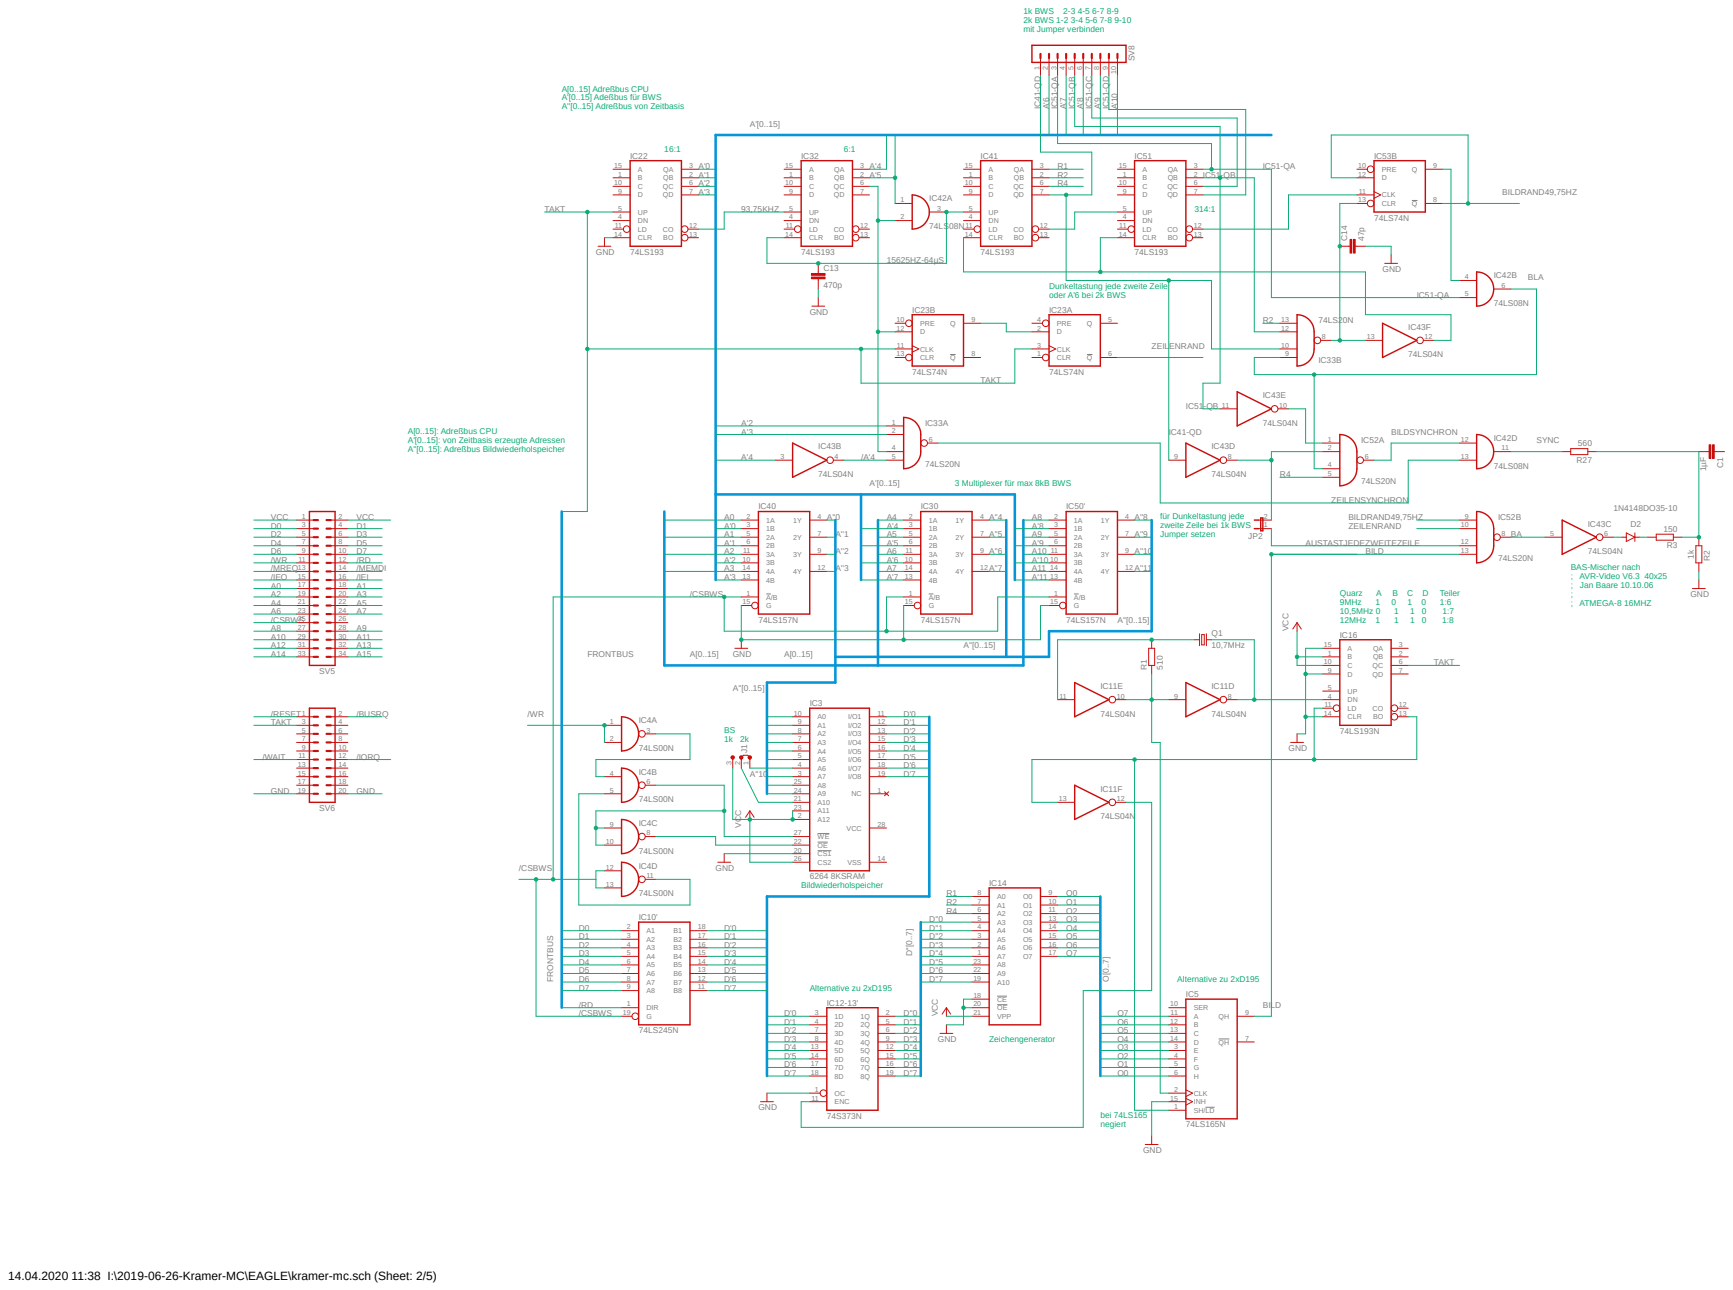
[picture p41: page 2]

Dunkeltastung jede zweite Zeile
oder A'6 bei 2k BWS

A[0..15]: Adreßbus CPU
A'[0..15]: von Zeitbasis erzeugte Adressen
A''[0..15]: Adreßbus Bildwiederholspeicher

3 Multiplexer für max 8kB BWS

für Dunkeltastung jede
zweite Zeile bei 1k BWS
Jumper setzen

14.04.2020 11:38 I:\2019-06-26-Kramer-MC\EAGLE\kramer-mc.sch (Sheet: 2/5)


14.04.2020 11:38 I:\2019-06-26-Kramer-MC\EAGLE\kramer-mc.sch (Sheet: 3/5)


14.04.2020 11:38 I:\2019-06-26-Kramer-MC\EAGLE\kramer-mc.sch (Sheet: 4/5)


Bit-Anzeige
24x für Daten- und Adreßbus
hier gezeigt A0
8x LED grün für DB
16x LED gelb für AB

Hex-Anzeige wie Bild 1.28
6x für Daten- und Adreßbus
hier gezeigt A0-A3

tastender Umschalter für Schritt

14.04.2020 11:38 I:\2019-06-26-Kramer-MC\EAGLE\kramer-mc.sch (Sheet: 5/5)

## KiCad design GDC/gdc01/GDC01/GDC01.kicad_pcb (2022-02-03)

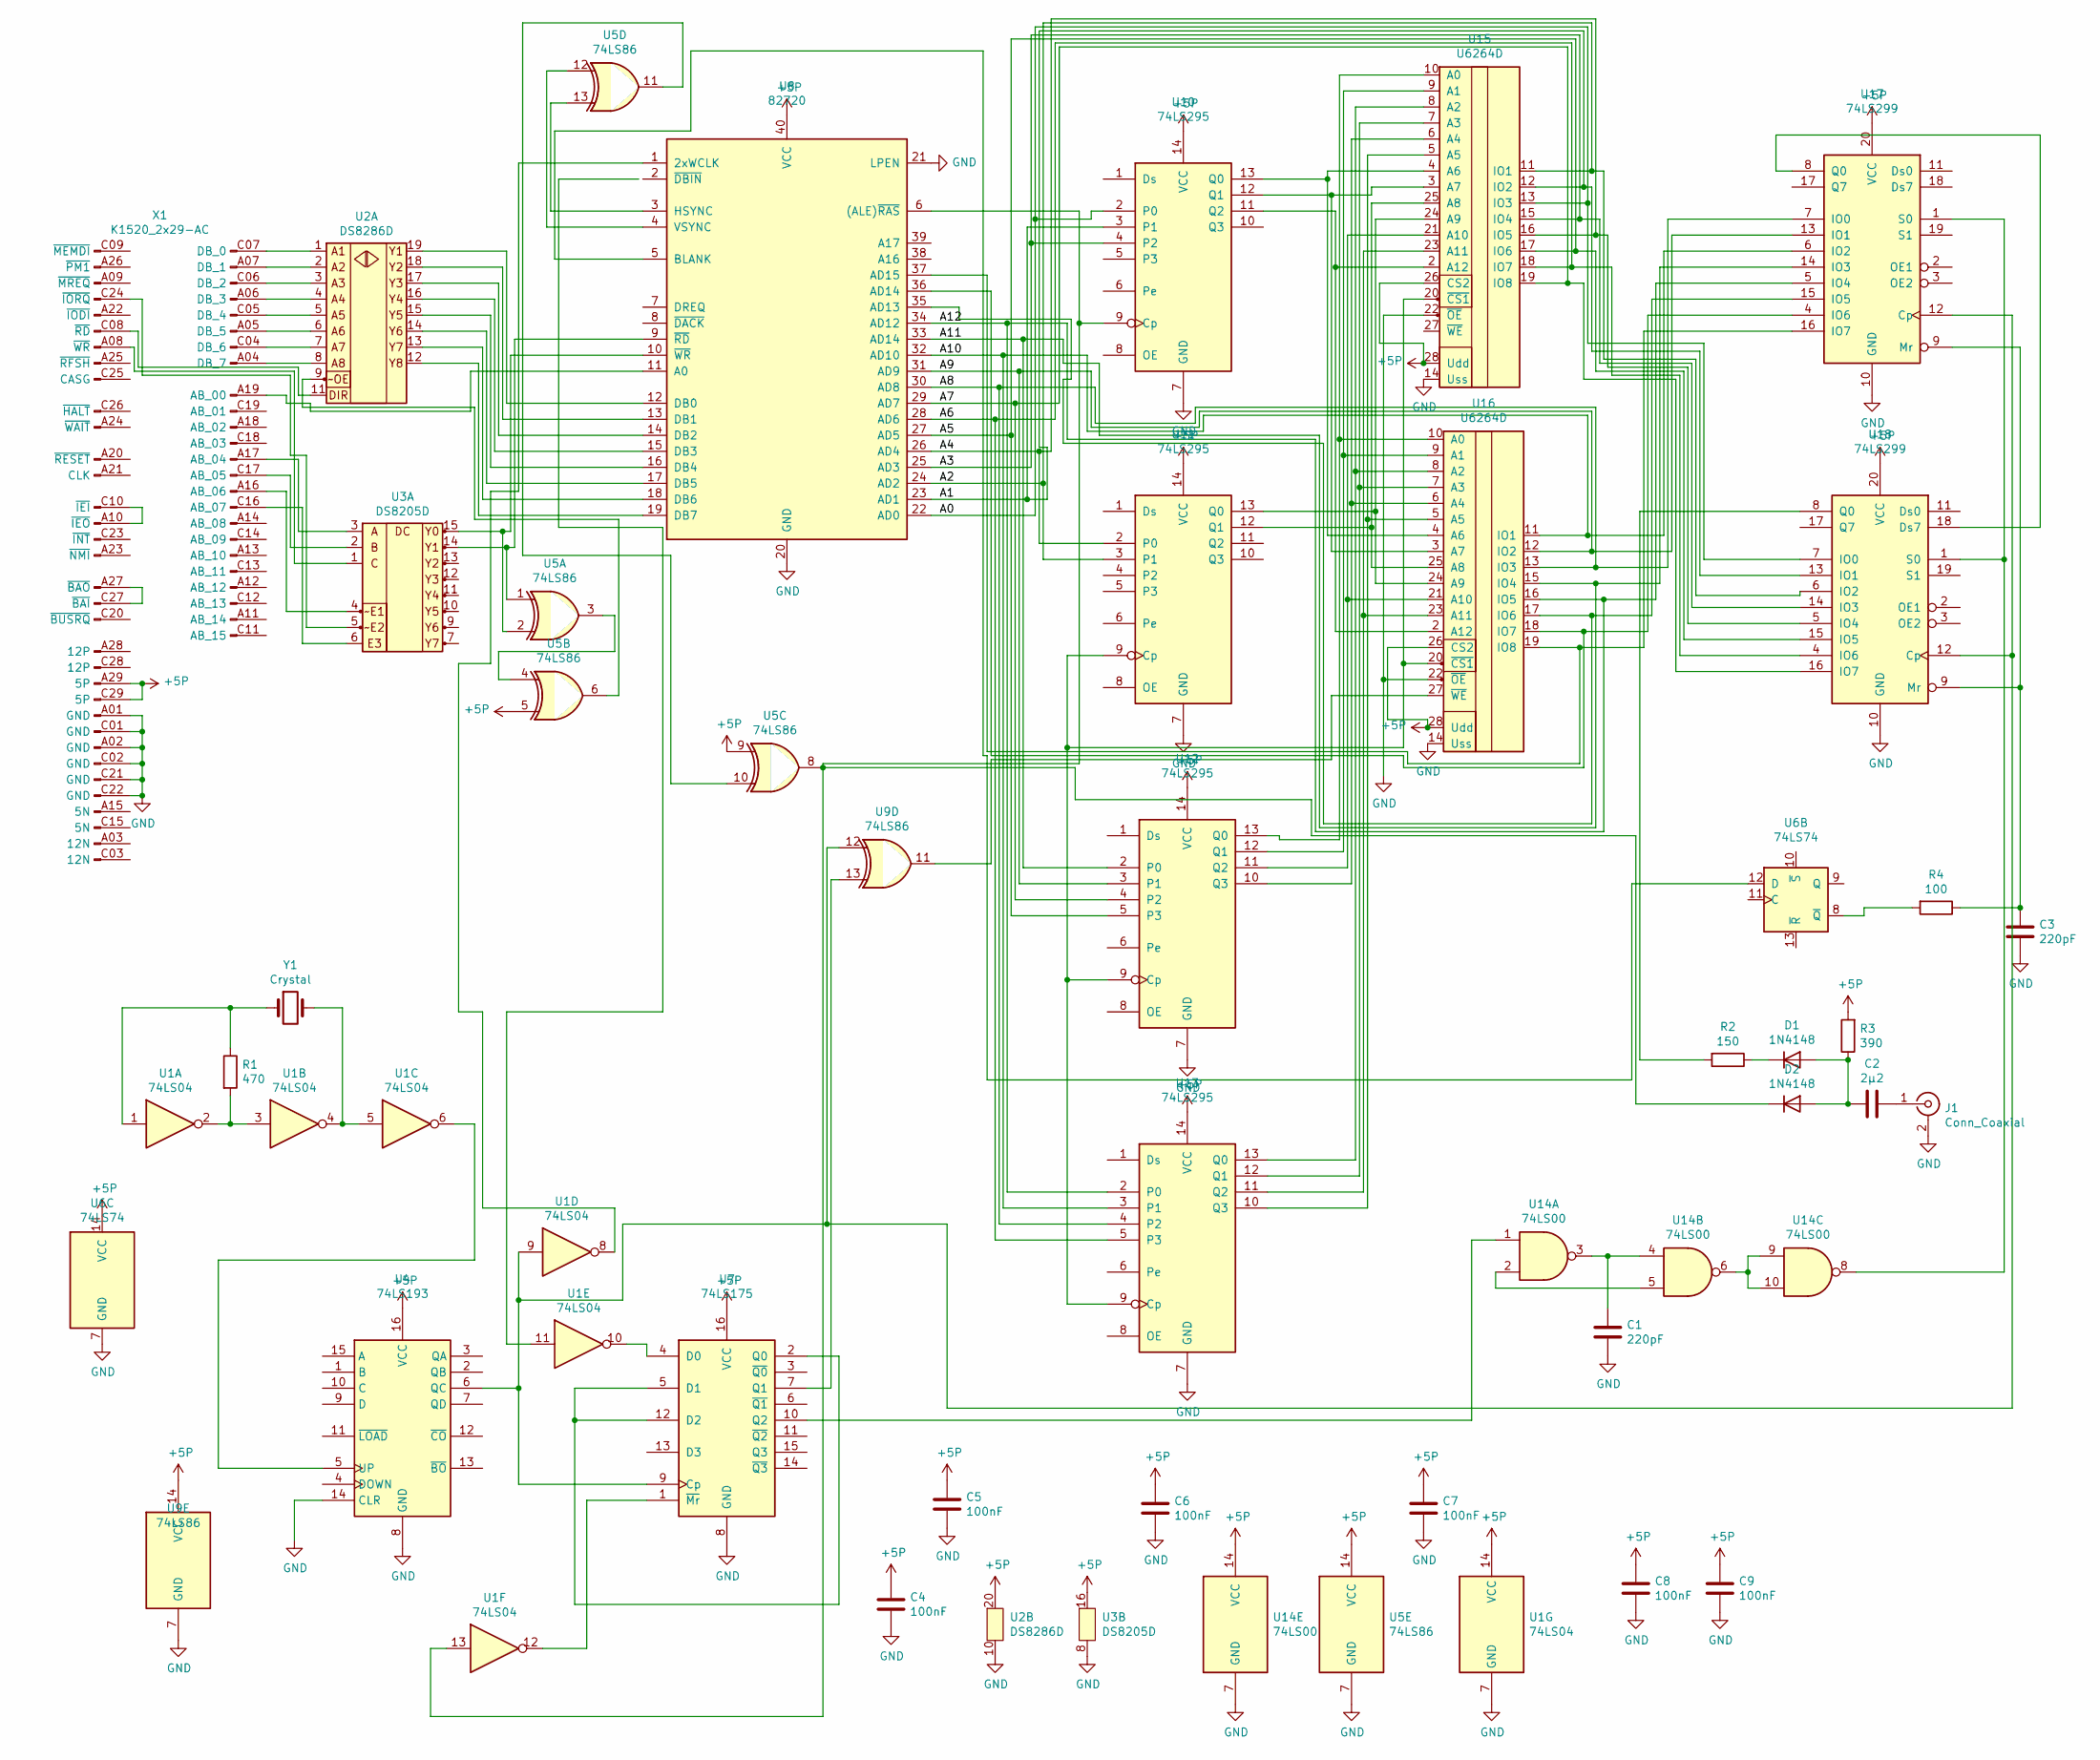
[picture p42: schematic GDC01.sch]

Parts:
C1, C3: 220pF; C_Disc_D3.0mm_W1.6mm_P2.50mm
C2: 2µ2; C_Axial_L22.0mm_D9.5mm_P27.50mm_Horizontal
C4, C5, C6, C7, C8, C9: 100nF; C_Disc_D3.0mm_W1.6mm_P2.50mm
D1, D2: 1N4148; D_DO-15_P10.16mm_Horizontal
J1: Conn_Coaxial; chinch
R1: 470; R_Axial_DIN0207_L6.3mm_D2.5mm_P10.16mm_Horizontal
R2: 150; R_Axial_DIN0207_L6.3mm_D2.5mm_P10.16mm_Horizontal
R3: 390; R_Axial_DIN0207_L6.3mm_D2.5mm_P10.16mm_Horizontal
R4: 100; R_Axial_DIN0207_L6.3mm_D2.5mm_P10.16mm_Horizontal
U1: 74LS04; DIP-14_W7.62mm_LongPads
U2: DS8286D; DIP-20_W7.62mm_LongPads
U3: DS8205D; DIP-16_W7.62mm_LongPads
U4: 74LS193; DIP-16_W7.62mm_LongPads
U5, U9: 74LS86; DIP-14_W7.62mm_LongPads
U6: 74LS74; DIP-14_W7.62mm_LongPads
U7: 74LS175; DIP-16_W7.62mm_LongPads
U8: 82720; DIP-40_W15.24mm
U10, U11, U12, U13: 74LS295; DIP-14_W7.62mm_LongPads
U14: 74LS00; DIP-14_W7.62mm_LongPads
U15, U16: U6264D; DIP-28_W15.24mm_LongPads
U17, U18: 74LS299; DIP-20_W7.62mm_LongPads
X1: K1520_2x29-AC; K1520_EFS2x29_DIN_male
Y1: Crystal; Crystal_HC49-U_Vertical

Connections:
+5P: C4.1, C5.1, C6.1, C7.1, C8.1, C9.1, R3.2, U1.14 (VCC), U2.20 (Vcc), U3.16 (Vcc), U4.16 (VCC), U5.5, U5.9, U5.14 (VCC), U6.14 (VCC), U7.16 (VCC), U8.40 (VCC), U9.14 (VCC), U10.14 (VCC), U11.14 (VCC), U12.14 (VCC), U13.14 (VCC), U14.14 (VCC), U15.26 (CS2), U15.28 (Udd), U16.26 (CS2), U16.28 (Udd), U17.20 (VCC), U18.20 (VCC), X1.A29 (5P), X1.C29 (5P)
/A0: U8.22 (AD0), U10.2 (P0), U15.13 (IO3), U18.7 (IO0)
/A1: U8.23 (AD1), U10.3 (P1), U15.12 (IO2), U18.13 (IO1)
/A2: U8.24 (AD2), U11.3 (P1), U15.11 (IO1), U18.6 (IO2)
/A3: U8.25 (AD3), U10.4 (P2), U15.15 (IO4), U18.14 (IO3)
/A4: U8.26 (AD4), U11.2 (P0), U15.16 (IO5), U18.5 (IO4)
/A5: U8.27 (AD5), U12.5 (P3), U15.17 (IO6), U18.15 (IO5)
/A6: U8.28 (AD6), U13.5 (P3), U15.18 (IO7), U18.4 (IO6)
/A7: U8.29 (AD7), U12.4 (P2), U15.19 (IO8), U18.16 (IO7)
/A8: U8.30 (AD8), U13.4 (P2), U16.13 (IO3), U17.7 (IO0)
/A9: U8.31 (AD9), U12.3 (P1), U16.12 (IO2), U17.13 (IO1)
/A10: U8.32 (AD10), U13.3 (P1), U16.11 (IO1), U17.6 (IO2)
/A11: U8.33 (AD14), U12.2 (P0), U16.15 (IO4), U17.14 (IO3)
/A12: U8.34 (AD12), U13.2 (P0), U16.16 (IO5), U17.5 (IO4)
GND: C1.2, C3.2, C4.2, C5.2, C6.2, C7.2, C8.2, C9.2, J1.2 (Ext), U1.7 (GND), U2.10 (GND), U3.8 (GND), U4.8 (GND), U4.14 (CLR), U5.7 (GND), U6.7 (GND), U7.8 (GND), U8.20 (GND), U8.21 (LPEN), U9.7 (GND), U10.7 (GND), U11.7 (GND), U12.7 (GND), U13.7 (GND), U14.7 (GND), U15.14 (Uss), U15.22 (~OE), U16.14 (Uss), U16.22 (~OE), U17.10 (GND), U18.10 (GND), X1.A01 (GND), X1.A02 (GND), X1.C01 (GND), X1.C02 (GND), X1.C21 (GND), X1.C22 (GND)
unnamed: C1.1, U14.3, U14.4
unnamed: C2.1, J1.1 (In)
unnamed: C2.2, D1.2 (A), D2.2 (A), R3.1
unnamed: C3.1, R4.1, U17.9 (Mr), U18.9 (Mr)
unnamed: D1.1 (K), R2.1
unnamed: D2.1 (K), U1.13, U5.8, U8.6 ((ALE)~RAS~), U10.9 (Cp)
unnamed: R1.1, U1.1, Y1.1
unnamed: R1.2, U1.2, U1.3
unnamed: R2.2, U18.8 (Q0)
unnamed: R4.2, U6.8 (~Q)
unnamed: U1.4, U1.5, Y1.2
unnamed: U1.6, U4.5 (UP)
unnamed: U1.8, U8.1 (2xWCLK)
unnamed: U1.9, U4.6 (QC), U7.9 (Cp), U9.12, U17.12 (Cp), U18.12 (Cp)
unnamed: U1.10, U7.4 (D0)
unnamed: U1.12, U7.1 (~Mr)
unnamed: U2.1 (A1), X1.C07 (DB_0)
unnamed: U2.2 (A2), X1.A07 (DB_1)
unnamed: U2.3 (A3), X1.C06 (DB_2)
unnamed: U2.4 (A4), X1.A06 (DB_3)
unnamed: U2.5 (A5), X1.C05 (DB_4)
unnamed: U2.6 (A6), X1.A05 (DB_5)
unnamed: U2.7 (A7), X1.C04 (DB_6)
unnamed: U2.8 (A8), X1.A04 (DB_7)
unnamed: U2.9 (~OE), U5.6
unnamed: U2.11 (STB), X1.C08 (~RD)
unnamed: U2.12 (Y8), U8.19 (DB7)
unnamed: U2.13 (Y7), U8.18 (DB6)
unnamed: U2.14 (Y6), U8.17 (DB5)
unnamed: U2.15 (Y5), U8.16 (DB4)
unnamed: U2.16 (A4), U8.15 (DB3)
unnamed: U2.17 (Y3), U8.14 (DB2)
unnamed: U2.18 (Y2), U8.13 (DB1)
unnamed: U2.19 (Y1), U8.12 (DB0)
unnamed: U3.1 (C), X1.A08 (~WR)
unnamed: U3.2 (B), X1.C17 (AB_05)
unnamed: U3.3 (A), X1.A17 (AB_04)
unnamed: U3.4 (~E1), X1.A16 (AB_06)
unnamed: U3.5 (~E2), X1.C24 (~IORQ)
unnamed: U3.6 (E3), X1.C16 (AB_07)
unnamed: U3.14 (Y1), U5.1, U8.9 (~RD~)
unnamed: U3.15 (Y0), U5.2, U8.10 (~WR~)
unnamed: U5.3, U5.4
unnamed: U5.10, U5.11
unnamed: U5.12, U8.4 (VSYNC)
unnamed: U5.13, U8.3 (HSYNC)
unnamed: U6.12 (D), U8.5 (BLANK)
unnamed: U7.7 (Q1), U9.13
unnamed: U7.2 (Q0), U7.5 (D1), U7.12 (D2)
unnamed: U8.11 (A0), X1.A19 (AB_00)
unnamed: U10.11 (Q2), U15.2 (A12), U16.2 (A12)
unnamed: U10.12 (Q1), U15.3 (A7), U16.3 (A7)
unnamed: U10.13 (Q0), U15.4 (A6), U16.4 (A6)
unnamed: U11.9 (Cp), U12.9 (Cp), U13.9 (Cp), U15.20 (~CS1), U16.20 (~CS1)
unnamed: U11.12 (Q1), U15.25 (A8), U16.25 (A8)
unnamed: U11.13 (Q0), U15.24 (A9), U16.24 (A9)
unnamed: U12.10 (Q3), U15.6 (A4), U16.6 (A4)
unnamed: U12.11 (Q2), U15.21 (A10), U16.21 (A10)
unnamed: U12.12 (Q1), U15.9 (A1), U16.9 (A1)
unnamed: U12.13 (Q0), U15.10 (A0), U16.10 (A0)
unnamed: U13.10 (Q3), U15.5 (A5), U16.5 (A5)
unnamed: U13.11 (Q2), U15.23 (A11), U16.23 (A11)
unnamed: U13.12 (Q1), U15.7 (A3), U16.7 (A3)
unnamed: U13.13 (Q0), U15.8 (A2), U16.8 (A2)
unnamed: U7.10 (Q2), U14.1
unnamed: U14.2, U14.5
unnamed: U14.8, U17.1 (S0), U18.1 (S0)
unnamed: U14.6, U14.9, U14.10
unnamed: U8.35 (AD13), U16.17 (IO6), U17.15 (IO5)
unnamed: U8.36 (AD14), U16.18 (IO7), U17.4 (IO6)
unnamed: U8.37 (AD15), U16.19 (IO8), U17.16 (IO7)
unnamed: U9.11, U16.27 (~WE)
unnamed: U17.8 (Q0), U18.18 (Ds7)
unnamed: X1.A10 (~IEO), X1.C10 (~IEI)
unnamed: X1.A27 (~BAO), X1.C27 (~BAI)

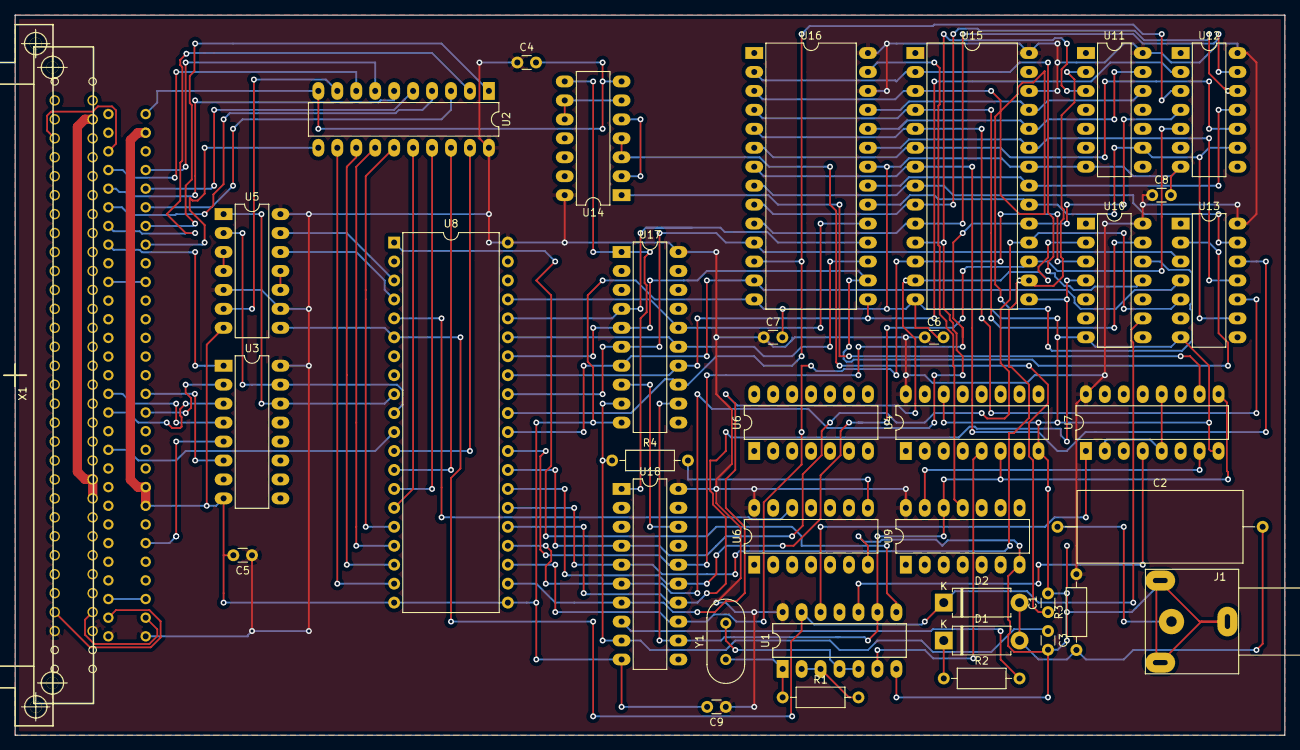
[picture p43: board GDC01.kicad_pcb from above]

Board: 2 copper layers, 170.2 x 96.5 mm, 37 parts (0 on the bottom side), 90 nets.

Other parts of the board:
U6#2: 74LS74; DIP-14_W7.62mm_LongPads

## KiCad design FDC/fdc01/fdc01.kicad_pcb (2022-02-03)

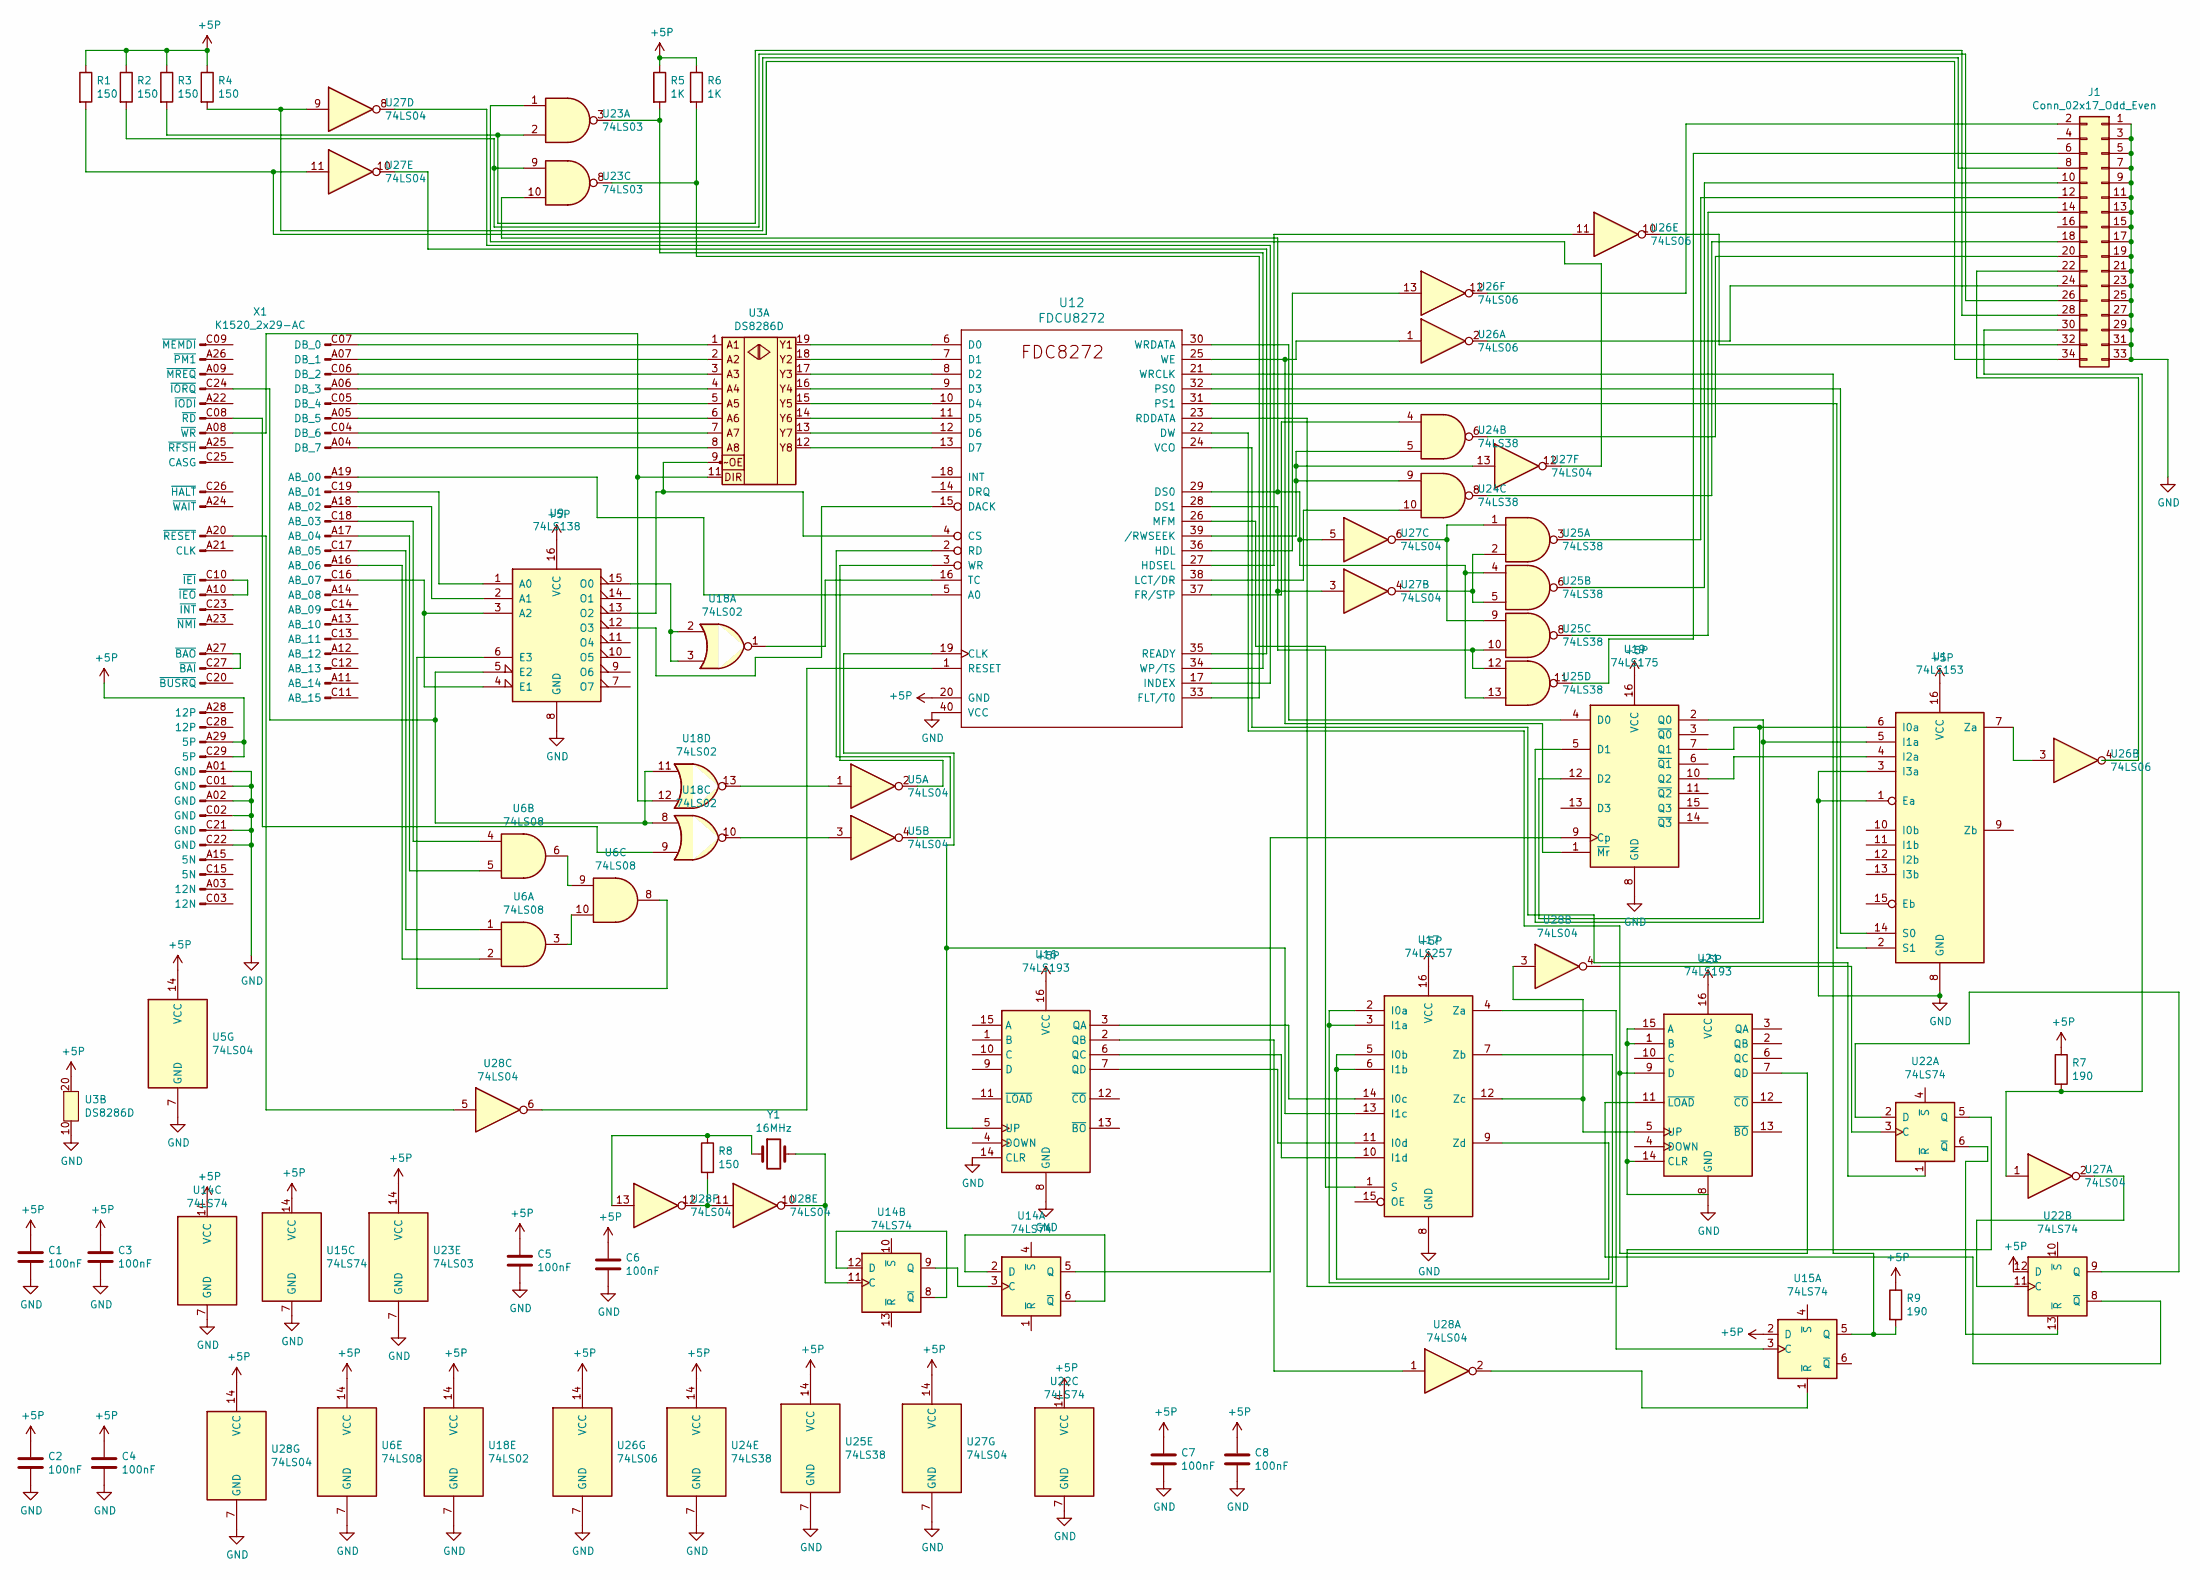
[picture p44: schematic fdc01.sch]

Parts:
C1, C2, C3, C4, C5, C6, C7, C8: 100nF; C_Disc_D3.0mm_W2.0mm_P2.50mm
J1: Conn_02x17_Odd_Even; PinSocket_2x17_P2.54mm_Horizontal
R1, R2, R3, R4, R8: 150; R_Axial_DIN0207_L6.3mm_D2.5mm_P10.16mm_Horizontal
R5, R6: 1K; R_Axial_DIN0207_L6.3mm_D2.5mm_P10.16mm_Horizontal
R7, R9: 190; R_Axial_DIN0207_L6.3mm_D2.5mm_P10.16mm_Horizontal
U1: 74LS153; DIP-16_W7.62mm_LongPads
U3: DS8286D; DIP-20_W7.62mm_LongPads
U5, U27, U28: 74LS04; DIP-14_W7.62mm_LongPads
U6: 74LS08; DIP-14_W7.62mm_LongPads
U9: 74LS138; DIP-16_W7.62mm_LongPads
U12: FDCU8272; DIP-40_W15.24mm_LongPads
U14, U15, U22: 74LS74; DIP-14_W7.62mm_LongPads
U16, U21: 74LS193; DIP-16_W7.62mm_LongPads
U17: 74LS257; DIP-16_W7.62mm_LongPads
U18: 74LS02; DIP-14_W7.62mm_LongPads
U19: 74LS175; DIP-16_W7.62mm_LongPads
U23: 74LS03; DIP-14_W7.62mm_LongPads
U24, U25: 74LS38; DIP-14_W7.62mm_LongPads
U26: 74LS06; DIP-14_W7.62mm_LongPads
X1: K1520_2x29-AC; K1520_EFS2x29_DIN_male
Y1: 16MHz; Crystal_HC49-U_Vertical

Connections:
+5P: C1.1, C2.1, C3.1, C4.1, C5.1, C6.1, C7.1, C8.1, R1.1, R2.1, R3.1, R4.1, R5.1, R6.1, R7.1, R9.1, U1.16 (VCC), U3.20 (Vcc), U5.14 (VCC), U6.14 (VCC), U9.16 (VCC), U12.20 (GND), U14.14 (VCC), U15.2 (D), U15.14 (VCC), U16.16 (VCC), U17.16 (VCC), U18.14 (VCC), U19.16 (VCC), U21.16 (VCC), U22.12 (D), U22.14 (VCC), U23.14 (VCC), U24.14 (VCC), U25.14 (VCC), U26.14 (VCC), U27.14 (VCC), U28.14 (VCC), X1.A29 (5P), X1.C29 (5P)
GND: C1.2, C2.2, C3.2, C4.2, C5.2, C6.2, C7.2, C8.2, J1.1, J1.3, J1.5, J1.7, J1.9, J1.11, J1.13, J1.15, J1.17, J1.19, J1.21, J1.23, J1.25, J1.27, J1.29, J1.31, J1.33, U1.1 (Ea), U1.3 (I3a), U1.8 (GND), U3.10 (GND), U5.7 (GND), U6.7 (GND), U9.8 (GND), U12.40 (VCC), U14.7 (GND), U15.7 (GND), U16.8 (GND), U16.14 (CLR), U17.8 (GND), U18.7 (GND), U19.8 (GND), U21.8 (GND), U22.7 (GND), U23.7 (GND), U24.7 (GND), U25.7 (GND), U26.7 (GND), U27.7 (GND), U28.7 (GND), X1.A01 (GND), X1.A02 (GND), X1.C01 (GND), X1.C02 (GND), X1.C21 (GND), X1.C22 (GND)
unnamed: J1.2, U26.12
unnamed: J1.6, U25.11
unnamed: J1.8, R4.2, U27.9
unnamed: J1.10, U25.6
unnamed: J1.12, U25.3
unnamed: J1.14, U25.8
unnamed: J1.18, U24.8
unnamed: J1.20, U24.6
unnamed: J1.24, U26.2
unnamed: J1.26, R2.2, U23.9
unnamed: J1.28, R3.2, U23.2
unnamed: J1.30, R7.2, U27.1
unnamed: J1.32, U26.10
unnamed: J1.34, R1.2, U27.11
unnamed: R5.2, U12.34 (WP/TS), U23.3
unnamed: R6.2, U12.33 (FLT/T0), U23.8
unnamed: R8.1, U28.13, Y1.1
unnamed: R8.2, U28.11, U28.12
unnamed: R9.2, U12.21 (WRCLK), U15.5 (Q)
unnamed: U1.2 (S1), U12.31 (PS1)
unnamed: U1.4 (I2a), U19.10 (Q2)
unnamed: U1.5 (I1a), U19.2 (Q0), U19.5 (D1)
unnamed: U1.6 (I0a), U19.7 (Q1), U19.12 (D2)
unnamed: U1.7 (Za), U26.3
unnamed: U1.14 (S0), U12.32 (PS0)
unnamed: U3.1 (A1), X1.C07 (DB_0)
unnamed: U3.2 (A2), X1.A07 (DB_1)
unnamed: U3.3 (A3), X1.C06 (DB_2)
unnamed: U3.4 (A4), X1.A06 (DB_3)
unnamed: U3.5 (A5), X1.C05 (DB_4)
unnamed: U3.6 (A6), X1.A05 (DB_5)
unnamed: U3.7 (A7), X1.C04 (DB_6)
unnamed: U3.8 (A8), X1.A04 (DB_7)
unnamed: U6.1, X1.C17 (AB_05)
unnamed: U6.2, X1.A16 (AB_06)
unnamed: U6.4, X1.C18 (AB_03)
unnamed: U6.5, X1.A17 (AB_04)
unnamed: U6.6, U6.9
unnamed: U6.8, U9.6 (E3)
unnamed: U6.3, U6.10
unnamed: U9.1 (A0), X1.C19 (AB_01)
unnamed: U9.2 (A1), X1.A18 (AB_02)
unnamed: U9.3 (A2), U9.4 (E1), X1.C16 (AB_07)
unnamed: U12.1 (RESET), U28.6
unnamed: U5.4, U12.2 (RD)
unnamed: U5.2, U12.3 (WR)
unnamed: U3.9 (~OE), U9.13 (O2), U12.4 (CS)
unnamed: U12.5 (A0), X1.A19 (AB_00)
unnamed: U3.19 (Y1), U12.6 (D0)
unnamed: U3.18 (Y2), U12.7 (D1)
unnamed: U3.17 (Y3), U12.8 (D2)
unnamed: U3.16 (A4), U12.9 (D3)
unnamed: U3.15 (Y5), U12.10 (D4)
unnamed: U3.14 (Y6), U12.11 (D5)
unnamed: U3.13 (Y7), U12.12 (D6)
unnamed: U3.12 (Y8), U12.13 (D7)
unnamed: U9.12 (O3), U12.15 (DACK)
unnamed: U12.16 (TC), U18.1
unnamed: U12.17 (INDEX), U27.8
unnamed: U12.19 (CLK), U16.5 (UP), U17.13 (I1c)
unnamed: U12.22 (DW), U21.7 (QD), U21.9 (D)
unnamed: U12.23 (RDDATA), U22.5 (Q)
unnamed: U12.24 (VCO), U22.1 (~R)
unnamed: U12.25 (WE), U19.1 (~Mr), U26.1
unnamed: U12.26 (MFM), U17.1 (S)
unnamed: U12.27 (HDSEL), U26.11
unnamed: U12.28 (DS1), U25.10, U25.12, U27.3
unnamed: U12.29 (DS0), U23.10, U25.4, U25.13, U27.5
unnamed: U12.30 (WRDATA), U19.4 (D0)
unnamed: U12.35 (READY), U27.10
unnamed: U12.36 (HDL), U26.13
unnamed: U12.37 (FR/STP), U24.4
unnamed: U12.38 (LCT/DR), U24.10
unnamed: U12.39 (/RWSEEK), U24.5, U24.9, U27.13
unnamed: U14.2 (D), U14.6 (~Q)
unnamed: U14.3 (C), U14.9 (Q)
unnamed: U14.5 (Q), U19.9 (Cp)
unnamed: U14.11 (C), U28.10, Y1.2
unnamed: U14.8 (~Q), U14.12 (D)
unnamed: U15.1 (~R), U28.2
unnamed: U15.3 (C), U17.4 (Za)
unnamed: U16.2 (QB), U28.1
unnamed: U16.3 (QA), U17.14 (I0c)
unnamed: U16.6 (QC), U17.10 (I1d)
unnamed: U16.7 (QD), U17.11 (I0d)
unnamed: U17.2 (I0a), U17.3 (I1a), U17.7 (Zb)
unnamed: U17.5 (I0b), U17.6 (I1b), U17.9 (Zd)
unnamed: U17.12 (Zc), U21.5 (UP), U28.3
unnamed: U9.15 (O0), U18.2, U18.3
unnamed: U18.9, X1.C08 (~RD)
unnamed: U5.3, U18.10
unnamed: U9.5 (E2), U18.8, U18.11, X1.C24 (~IORQ)
unnamed: U3.11 (STB), U18.12, X1.A08 (~WR)
unnamed: U5.1, U18.13
unnamed: U21.1 (B), U21.14 (CLR), U21.15 (A)
unnamed: U21.11 (~LOAD), U22.8 (~Q)
unnamed: U22.2 (D), U22.9 (Q)
unnamed: U22.3 (C), U28.4
unnamed: U22.11 (C), U27.2
unnamed: U22.6 (~Q), U22.13 (~R)
unnamed: U23.1, U27.12
unnamed: U25.1, U25.9, U27.6
unnamed: U25.2, U25.5, U27.4
unnamed: U28.5, X1.A20 (~RESET)
unnamed: X1.A10 (~IEO), X1.C10 (~IEI)
unnamed: X1.A27 (~BAO), X1.C27 (~BAI)

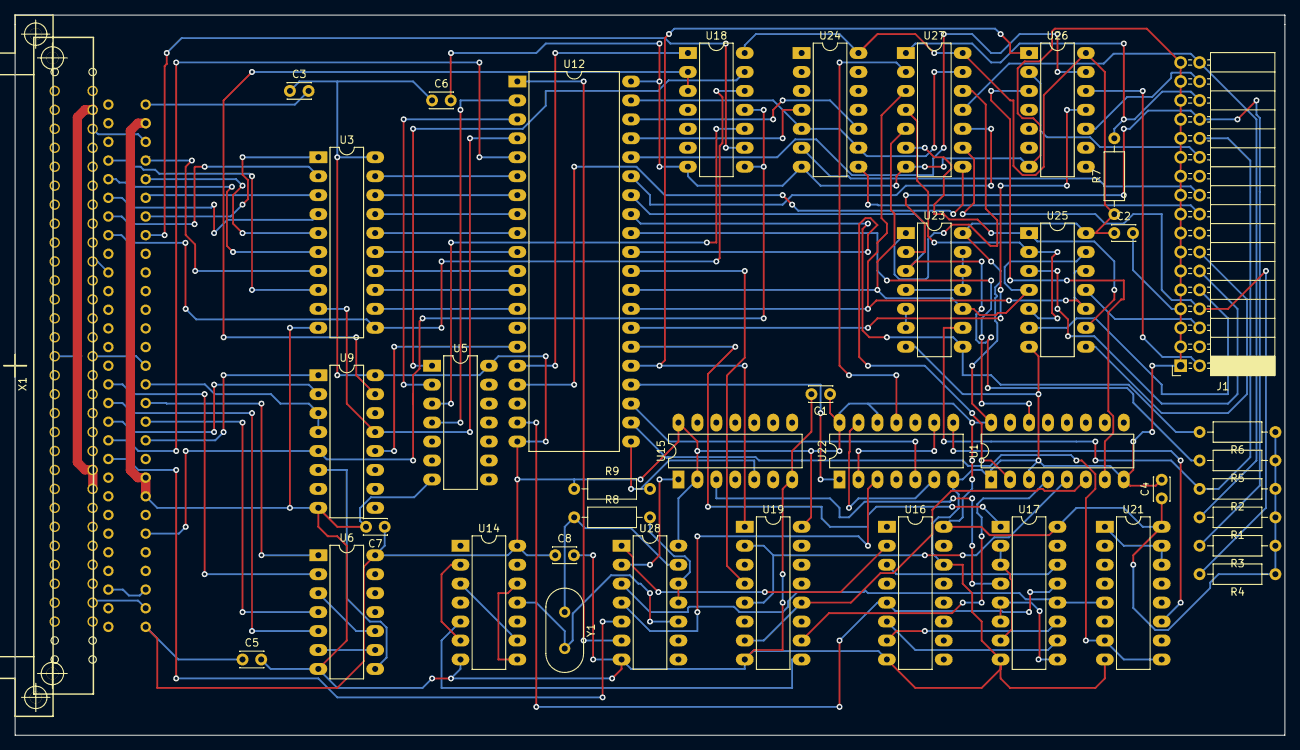
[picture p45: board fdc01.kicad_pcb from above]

Board: 2 copper layers, 170.2 x 96.5 mm, 40 parts (0 on the bottom side), 108 nets.

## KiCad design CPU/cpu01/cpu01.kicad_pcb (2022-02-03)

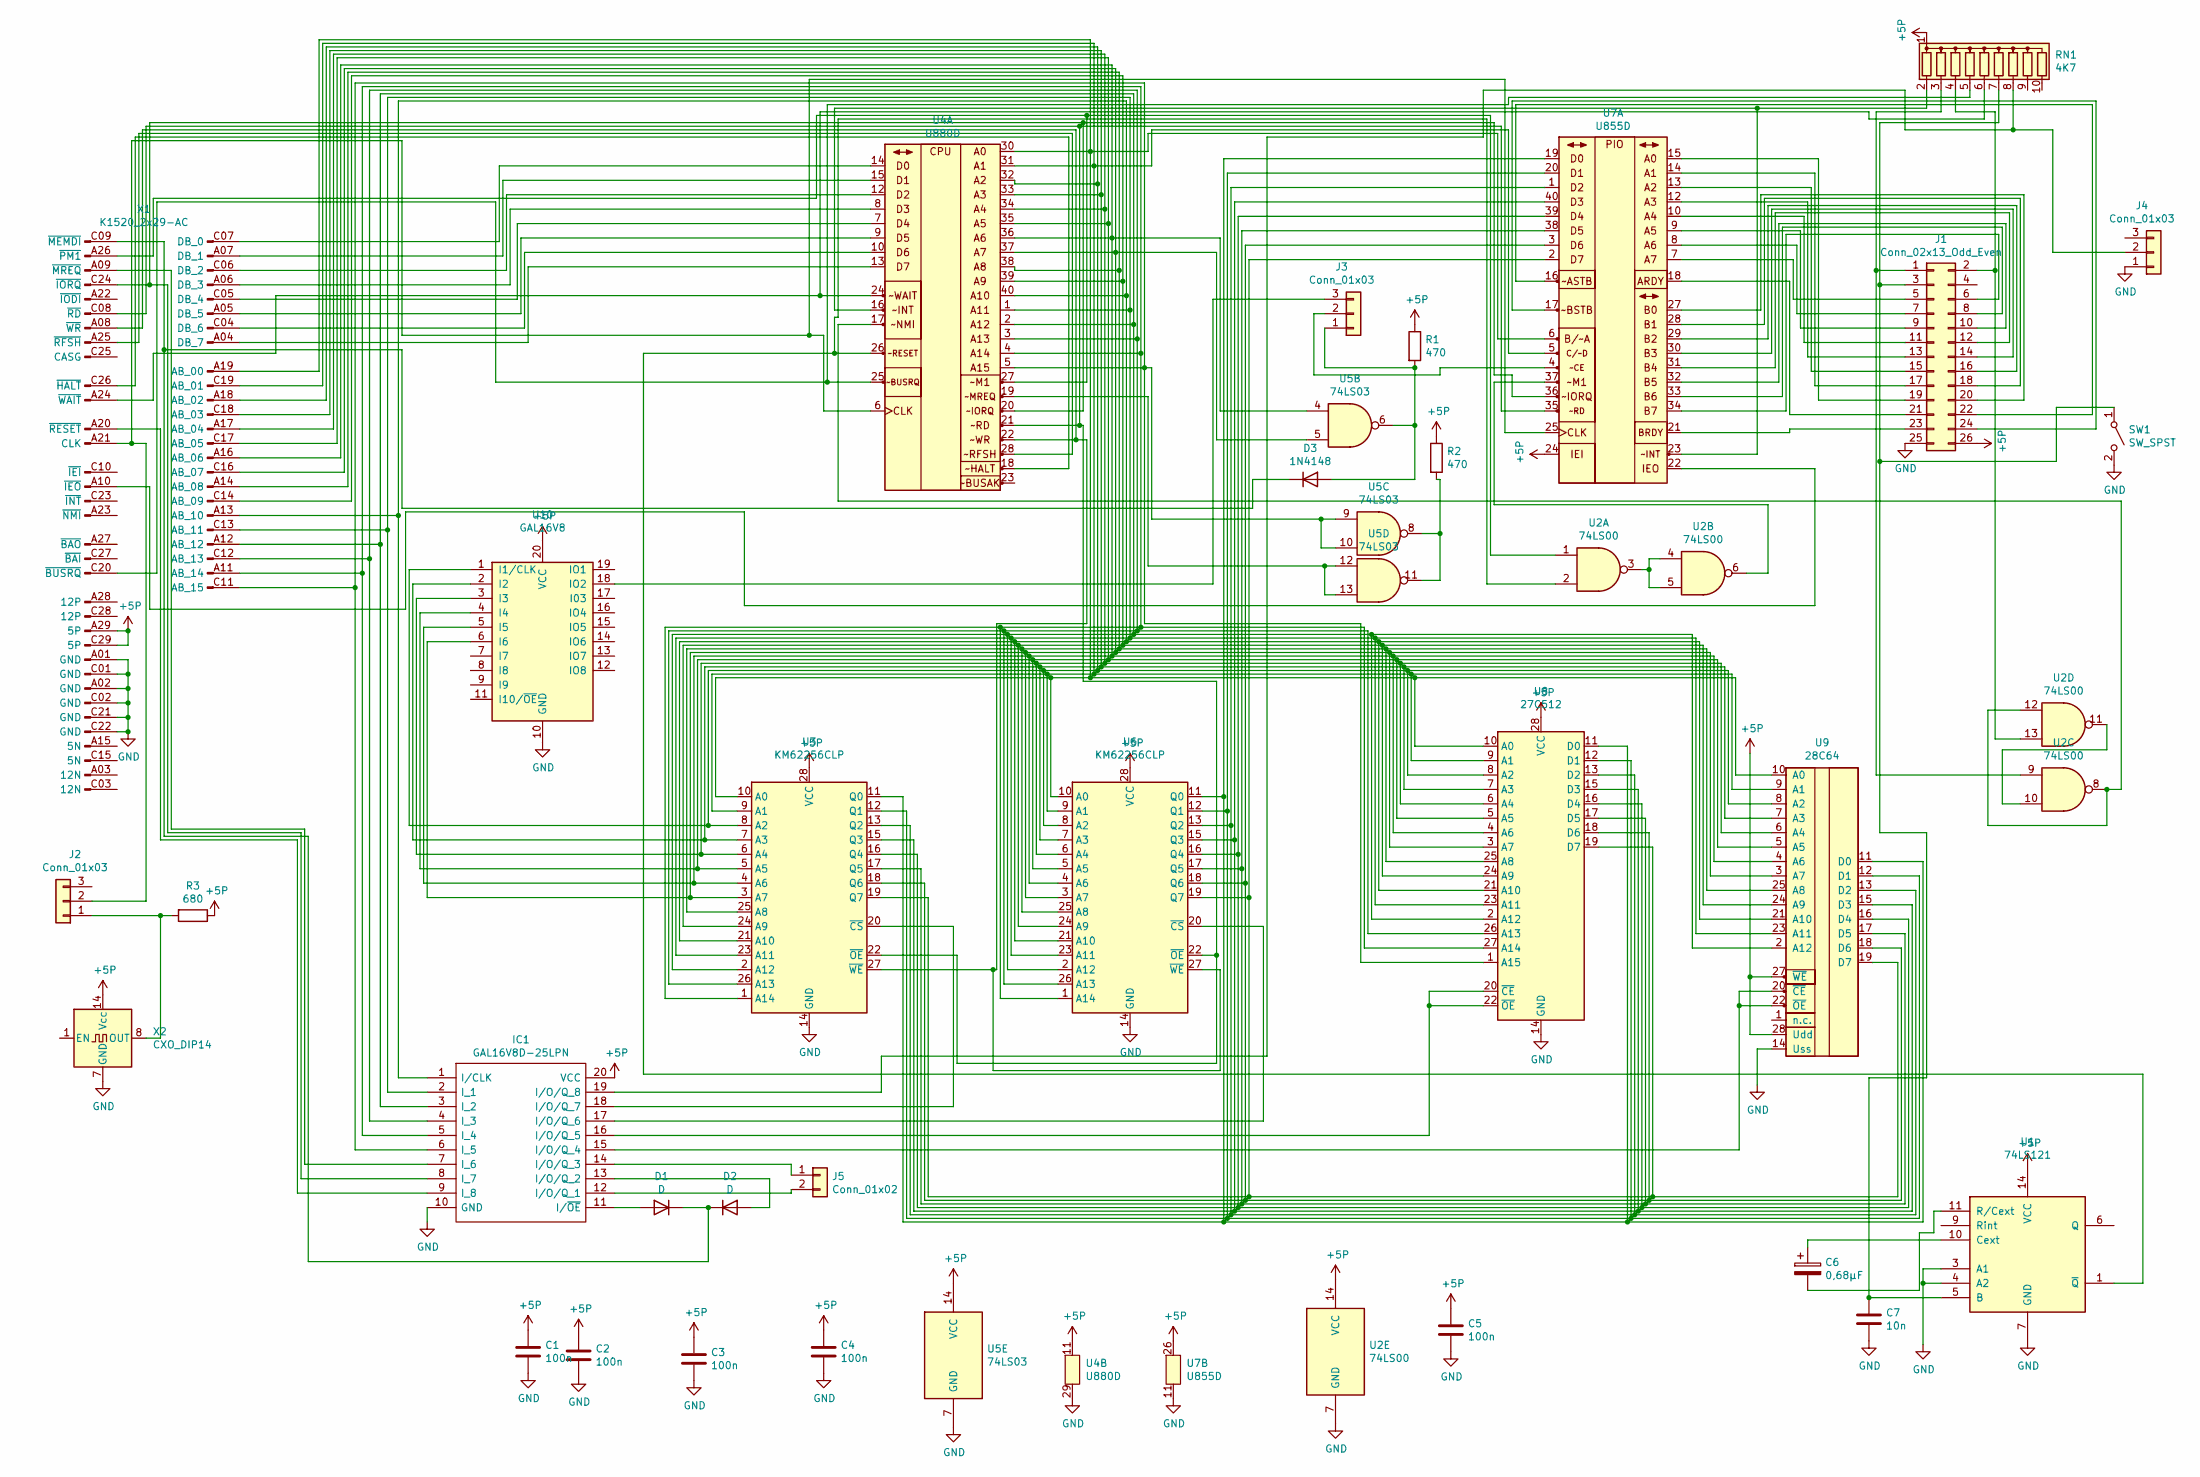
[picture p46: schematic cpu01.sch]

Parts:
C1, C2, C3, C4, C5: 100n; C_Disc_D3.0mm_W2.0mm_P2.50mm
C6: 0,68µF; CP_Radial_D4.0mm_P2.00mm
C7: 10n; C_Disc_D3.0mm_W2.0mm_P2.50mm
D1, D2: D; D_DO-15_P10.16mm_Horizontal
D3: 1N4148; D_DO-15_P10.16mm_Horizontal
IC1: GAL16V8D-25LPN; DIP762W56P254L2591H533Q20N; Manufacturer_Part_Number GAL16V8D-25LPN; Mouser Part Number 842-GAL16V8D25LPN
J1: Conn_02x13_Odd_Even; PinSocket_2x13_P2.54mm_Horizontal
J2, J3, J4: Conn_01x03; PinSocket_1x03_P2.54mm_Vertical
J5: Conn_01x02; PinSocket_1x02_P2.54mm_Vertical
R1, R2: 470; R_Axial_DIN0207_L6.3mm_D2.5mm_P10.16mm_Horizontal
R3: 680; R_Axial_DIN0207_L6.3mm_D2.5mm_P10.16mm_Horizontal
RN1: 4K7; R_Array_SIP10
SW1: SW_SPST; SW_Tactile_SKHH_Angled
U1: 74LS121; DIP-14_W7.62mm_LongPads
U2: 74LS00; DIP-14_W7.62mm_LongPads
U3, U6: KM62256CLP; DIP-28_W15.24mm
U4: U880D; DIP-40_W15.24mm_LongPads
U5: 74LS03; DIP-14_W7.62mm_LongPads
U7: U855D; DIP-40_W15.24mm_LongPads
U8: 27C512; DIP-28_W15.24mm
U9: 28C64; DIP-28_W15.24mm_LongPads
U10: GAL16V8; PLCC-20_THT-Socket
X1: K1520_2x29-AC; K1520_EFS2x29_DIN_male
X2: CXO_DIP14; Oscillator_DIP-14

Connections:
+5P: C1.1, C2.1, C3.1, C4.1, C5.1, IC1.20 (VCC), J1.26, R1.1, R2.1, R3.1, RN1.1 (common), U1.14 (VCC), U2.14 (VCC), U3.28 (VCC), U4.11 (Vcc), U5.14 (VCC), U6.28 (VCC), U7.24 (IEI), U7.26 (Vcc), U8.28 (VCC), U9.27 (~WE), U9.28 (Udd), U10.20 (VCC), X1.A29 (5P), X1.C29 (5P), X2.14 (Vcc)
GND: C1.2, C2.2, C3.2, C4.2, C5.2, C7.2, IC1.10 (GND), J1.25, J4.1, SW1.2 (B), U1.3 (A1), U1.4 (A2), U1.7 (GND), U2.7 (GND), U3.14 (GND), U4.29 (GND), U5.7 (GND), U6.14 (GND), U7.11 (GND), U8.14 (GND), U9.14 (Uss), U10.10 (GND), X1.A01 (GND), X1.A02 (GND), X1.C01 (GND), X1.C02 (GND), X1.C21 (GND), X1.C22 (GND), X2.7 (GND)
unnamed: C6.1, U1.10 (Cext)
unnamed: C6.2, U1.11 (R/Cext)
unnamed: C7.1, J1.3, RN1.7 (R6), SW1.1 (A), U1.5 (B)
unnamed: D1.1 (K), D2.1 (K), D3.1 (K), X1.C09 (~MEMDI)
unnamed: D1.2 (A), IC1.11 (I/~OE)
unnamed: D2.2 (A), IC1.13 (I/O/Q_2)
unnamed: D3.2 (A), J3.1, R1.2, U5.6
unnamed: IC1.1 (I/CLK), U3.21 (A10), U4.40 (A10), U6.21 (A10), U8.21 (A10), U9.21 (A10), X1.A13 (AB_10)
unnamed: IC1.2 (I_1), U3.23 (A11), U4.1 (A11), U6.23 (A11), U8.23 (A11), U9.23 (A11), X1.C13 (AB_11)
unnamed: IC1.3 (I_2), U3.2 (A12), U4.2 (A12), U6.2 (A12), U8.2 (A12), U9.2 (A12), X1.A12 (AB_12)
unnamed: IC1.4 (I_3), U3.26 (A13), U4.3 (A13), U6.26 (A13), U8.26 (A13), X1.C12 (AB_13)
unnamed: IC1.5 (I_4), U3.1 (A14), U4.4 (A14), U6.1 (A14), U8.27 (A14), X1.A11 (AB_14)
unnamed: IC1.6 (I_5), U4.5 (A15), U5.9, U5.10, U8.1 (A15), X1.C11 (AB_15)
unnamed: IC1.7 (I_6), X1.A09 (~MREQ)
unnamed: IC1.8 (I_7), U4.20 (~IORQ), U7.36 (~IORQ), X1.C24 (~IORQ)
unnamed: IC1.9 (I_8), X1.A20 (~RESET)
unnamed: IC1.12 (I/O/Q_1), J5.2
unnamed: IC1.14 (I/O/Q_3), J5.1
unnamed: IC1.15 (I/O/Q_4), U9.20 (~CE), U9.22 (~OE)
unnamed: IC1.16 (I/O/Q_5), U8.20 (~CE), U8.22 (~OE)
unnamed: IC1.17 (I/O/Q_6), U6.20 (~CS)
unnamed: IC1.18 (I/O/Q_7), U3.20 (~CS)
unnamed: IC1.19 (I/O/Q_8), J4.2, RN1.8 (R7)
unnamed: J1.1, RN1.3 (R2), U2.9
unnamed: J1.2, RN1.4 (R3), U2.13
unnamed: J1.5, U7.7 (A7)
unnamed: J1.6, U7.34 (B7)
unnamed: J1.7, U7.8 (A6)
unnamed: J1.8, U7.33 (B6)
unnamed: J1.9, U7.9 (A5)
unnamed: J1.10, U7.32 (B5)
unnamed: J1.11, U7.10 (A4)
unnamed: J1.12, U7.31 (B4)
unnamed: J1.13, U7.12 (A3)
unnamed: J1.14, U7.30 (B3)
unnamed: J1.15, U7.13 (A2)
unnamed: J1.16, U7.29 (B2)
unnamed: J1.17, U7.14 (A1)
unnamed: J1.18, U7.28 (B1)
unnamed: J1.19, U7.15 (A0)
unnamed: J1.20, U7.27 (B0)
unnamed: J1.21, U7.18 (ARDY)
unnamed: J1.22, U7.16 (~ASTB)
unnamed: J1.23, U7.21 (BRDY)
unnamed: J1.24, U7.17 (~BSTB)
unnamed: J2.1, R3.2, X2.8 (OUT)
unnamed: J2.2, U4.6 (CLK), U7.25 (CLK), X1.A21 (CLK)
unnamed: J3.2, U7.4 (~CE)
unnamed: J3.3, U10.18 (IO2)
unnamed: R2.2, U5.8, U5.11
unnamed: RN1.2 (R1), U4.16 (~INT), U7.23 (~INT)
unnamed: RN1.5 (R4), U4.25 (~BUSRQ), X1.C20 (~BUSRQ)
unnamed: RN1.6 (R5), U4.24 (~WAIT), X1.A24 (~WAIT)
unnamed: U1.1 (~Q), U2.2, U4.26 (~RESET)
unnamed: U2.1, U4.27 (~M1), X1.A26 (~PM1)
unnamed: U2.3, U2.4, U2.5
unnamed: U2.6, U7.37 (~M1)
unnamed: U2.10, U2.11
unnamed: U2.8, U2.12, U4.17 (~NMI)
unnamed: U3.9 (A1), U4.31 (A1), U6.9 (A1), U7.5 (C/~D), U8.9 (A1), U9.9 (A1), X1.C19 (AB_01)
unnamed: U3.10 (A0), U4.30 (A0), U6.10 (A0), U7.6 (B/~A), U8.10 (A0), U9.10 (A0), X1.A19 (AB_00)
unnamed: U3.11 (Q0), U6.11 (Q0), U7.19 (D0), U8.11 (D0), U9.11 (D0)
unnamed: U3.12 (Q1), U6.12 (Q1), U7.20 (D1), U8.12 (D1), U9.12 (D1)
unnamed: U3.13 (Q2), U6.13 (Q2), U7.1 (D2), U8.13 (D2), U9.13 (D2)
unnamed: U3.15 (Q3), U6.15 (Q3), U7.40 (D3), U8.15 (D3), U9.15 (D3)
unnamed: U3.16 (Q4), U6.16 (Q4), U7.39 (D4), U8.16 (D4), U9.16 (D4)
unnamed: U3.17 (Q5), U6.17 (Q5), U7.38 (D5), U8.17 (D5), U9.17 (D5)
unnamed: U3.18 (Q6), U6.18 (Q6), U7.3 (D6), U8.18 (D6), U9.18 (D6)
unnamed: U3.19 (Q7), U6.19 (Q7), U7.2 (D7), U8.19 (D7), U9.19 (D7)
unnamed: U3.22 (~OE), U4.21 (~RD), U6.22 (~OE), U7.35 (~RD), X1.C08 (~RD)
unnamed: U3.24 (A9), U4.39 (A9), U6.24 (A9), U8.24 (A9), U9.24 (A9), X1.C14 (AB_09)
unnamed: U3.25 (A8), U4.38 (A8), U6.25 (A8), U8.25 (A8), U9.25 (A8), X1.A14 (AB_08)
unnamed: U3.27 (~WE), U4.22 (~WR), U6.27 (~WE), X1.A08 (~WR)
unnamed: U4.7 (D4), X1.C05 (DB_4)
unnamed: U4.8 (D3), X1.A06 (DB_3)
unnamed: U4.9 (D5), X1.A05 (DB_5)
unnamed: U4.10 (D6), X1.C04 (DB_6)
unnamed: U4.12 (D2), X1.C06 (DB_2)
unnamed: U4.13 (D7), X1.A04 (DB_7)
unnamed: U4.14 (D0), X1.C07 (DB_0)
unnamed: U4.15 (D1), X1.A07 (DB_1)
unnamed: U4.18 (~HALT), X1.C26 (~HALT)
unnamed: U4.19 (~MREQ), U5.12, U5.13
unnamed: U4.28 (~RFSH), X1.A25 (~RFSH)
unnamed: U7.22 (IEO), X1.A10 (~IEO)
unnamed: U3.8 (A2), U4.32 (A2), U6.8 (A2), U8.8 (A2), U9.8 (A2), U10.1 (I1/CLK), X1.A18 (AB_02)
unnamed: U3.7 (A3), U4.33 (A3), U6.7 (A3), U8.7 (A3), U9.7 (A3), U10.2 (I2), X1.C18 (AB_03)
unnamed: U3.6 (A4), U4.34 (A4), U6.6 (A4), U8.6 (A4), U9.6 (A4), U10.3 (I3), X1.A17 (AB_04)
unnamed: U3.5 (A5), U4.35 (A5), U6.5 (A5), U8.5 (A5), U9.5 (A5), U10.4 (I4), X1.C17 (AB_05)
unnamed: U3.4 (A6), U4.36 (A6), U5.4, U6.4 (A6), U8.4 (A6), U9.4 (A6), U10.5 (I5), X1.A16 (AB_06)
unnamed: U3.3 (A7), U4.37 (A7), U5.5, U6.3 (A7), U8.3 (A7), U9.3 (A7), U10.6 (I6), X1.C16 (AB_07)

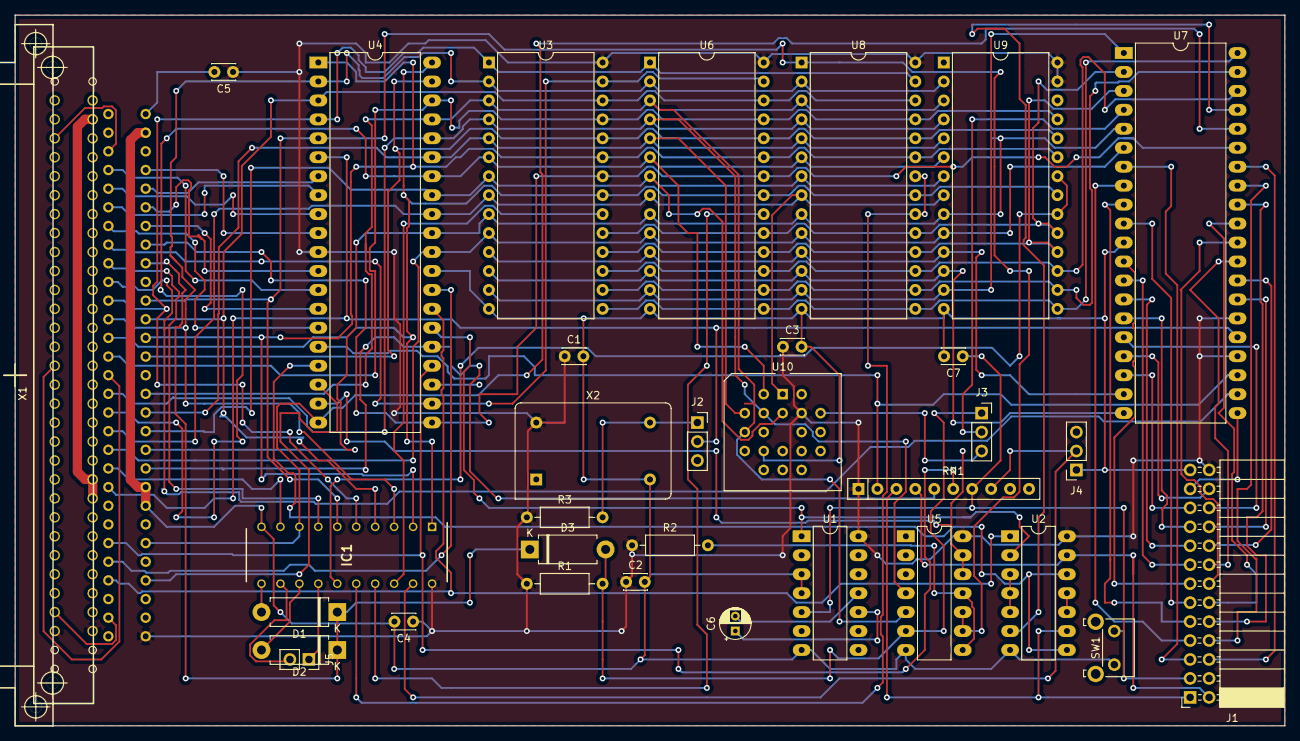
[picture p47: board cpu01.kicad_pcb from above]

Board: 2 copper layers, 170.2 x 95.2 mm, 33 parts (0 on the bottom side), 93 nets.

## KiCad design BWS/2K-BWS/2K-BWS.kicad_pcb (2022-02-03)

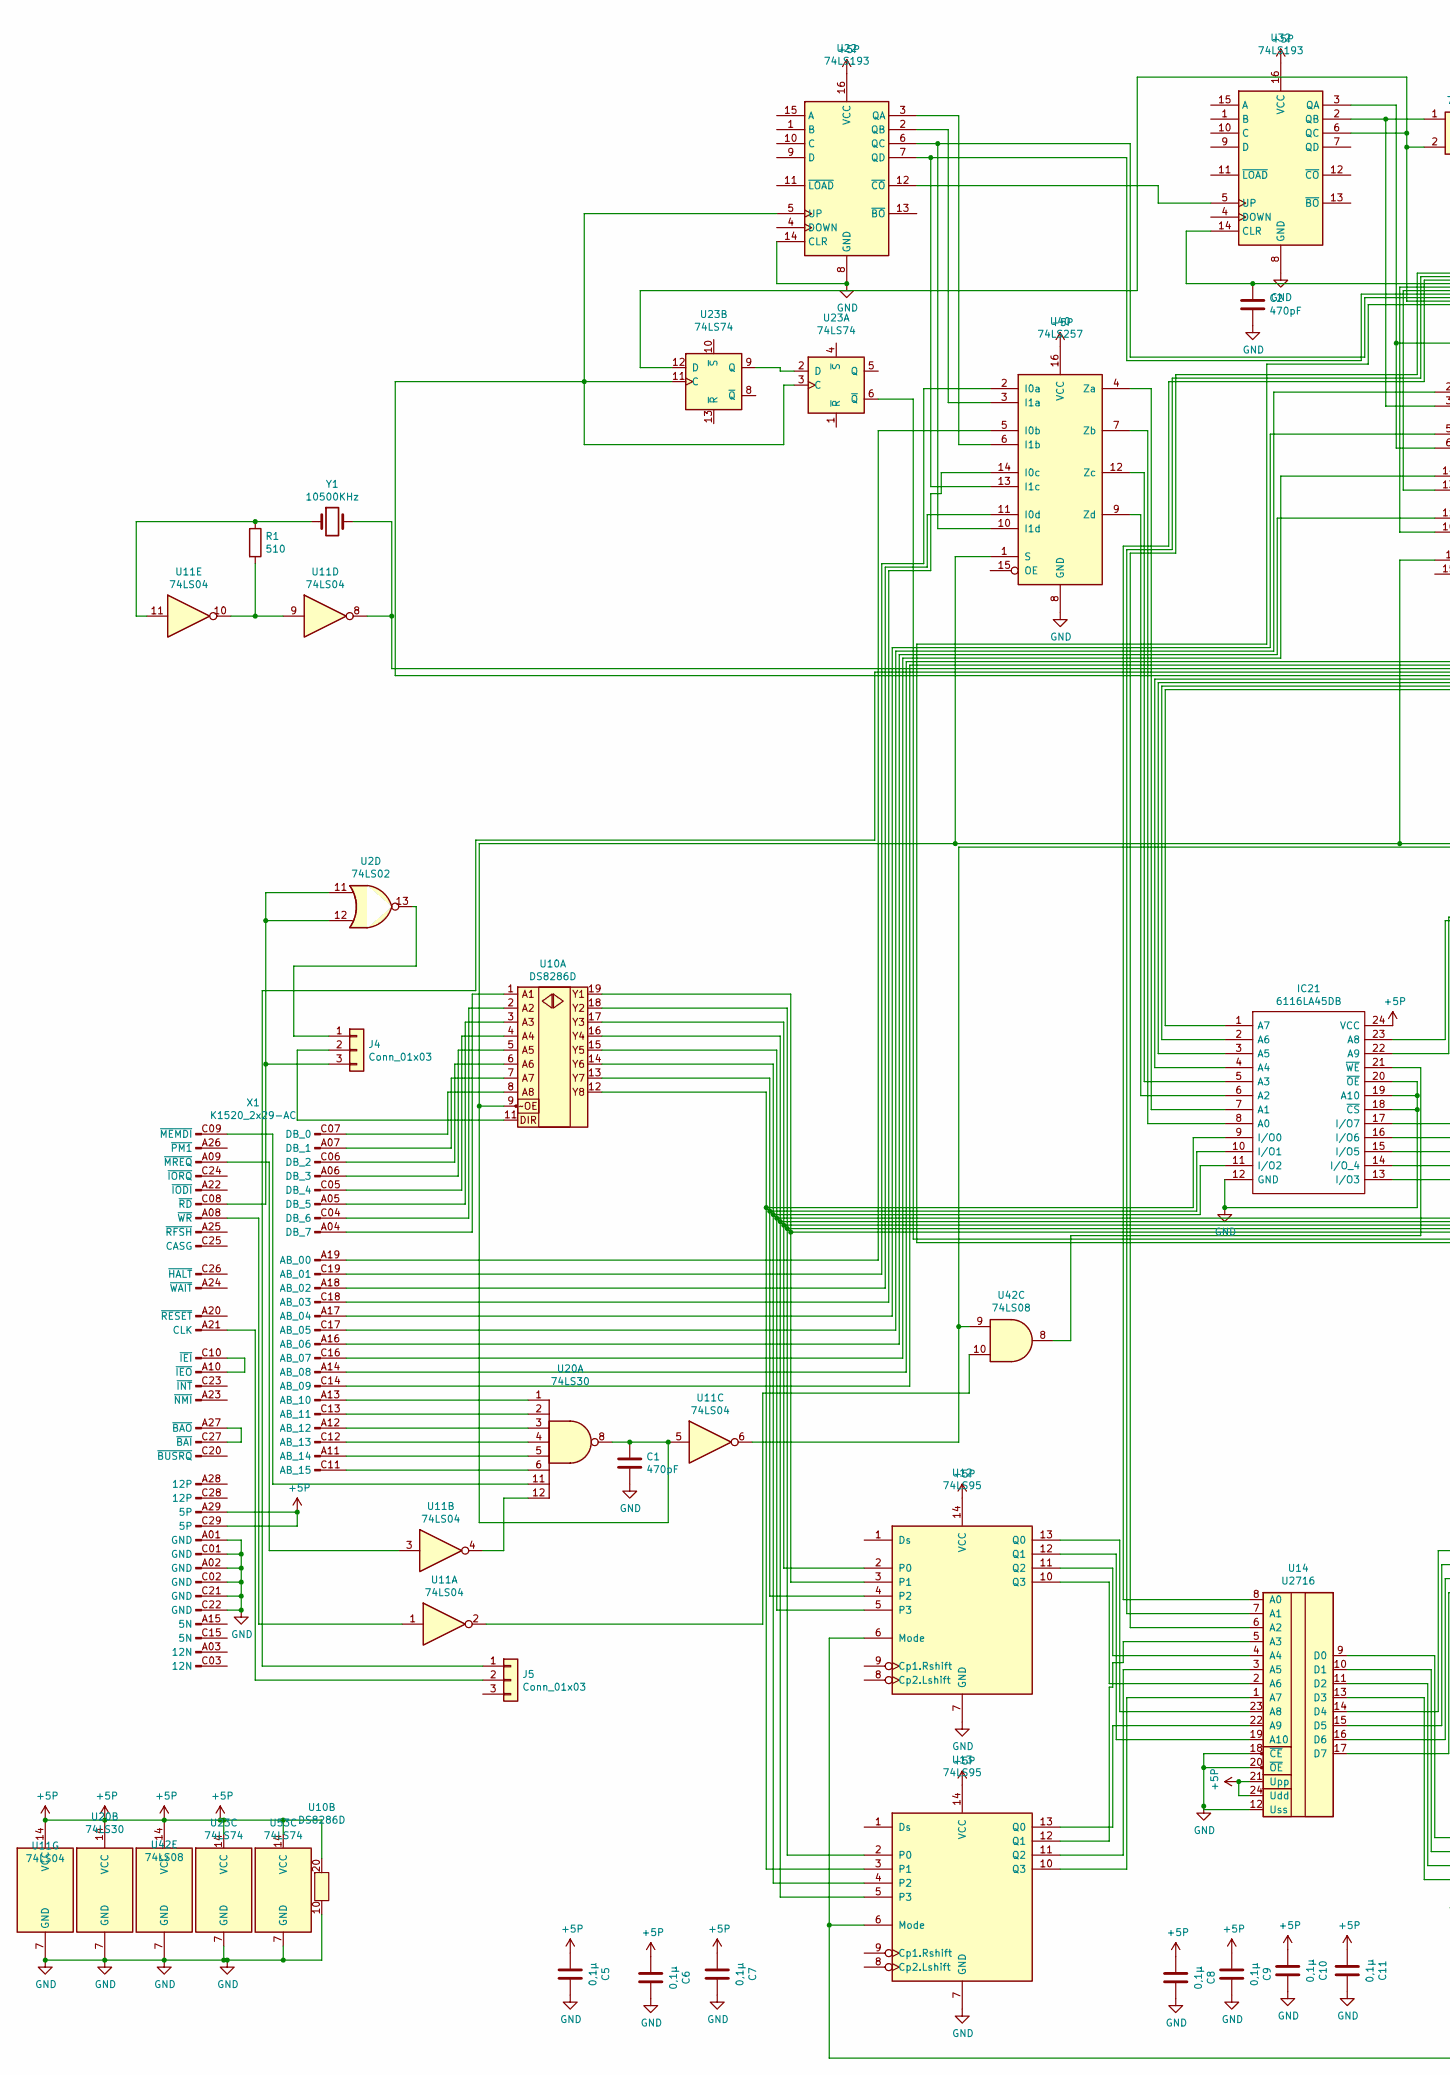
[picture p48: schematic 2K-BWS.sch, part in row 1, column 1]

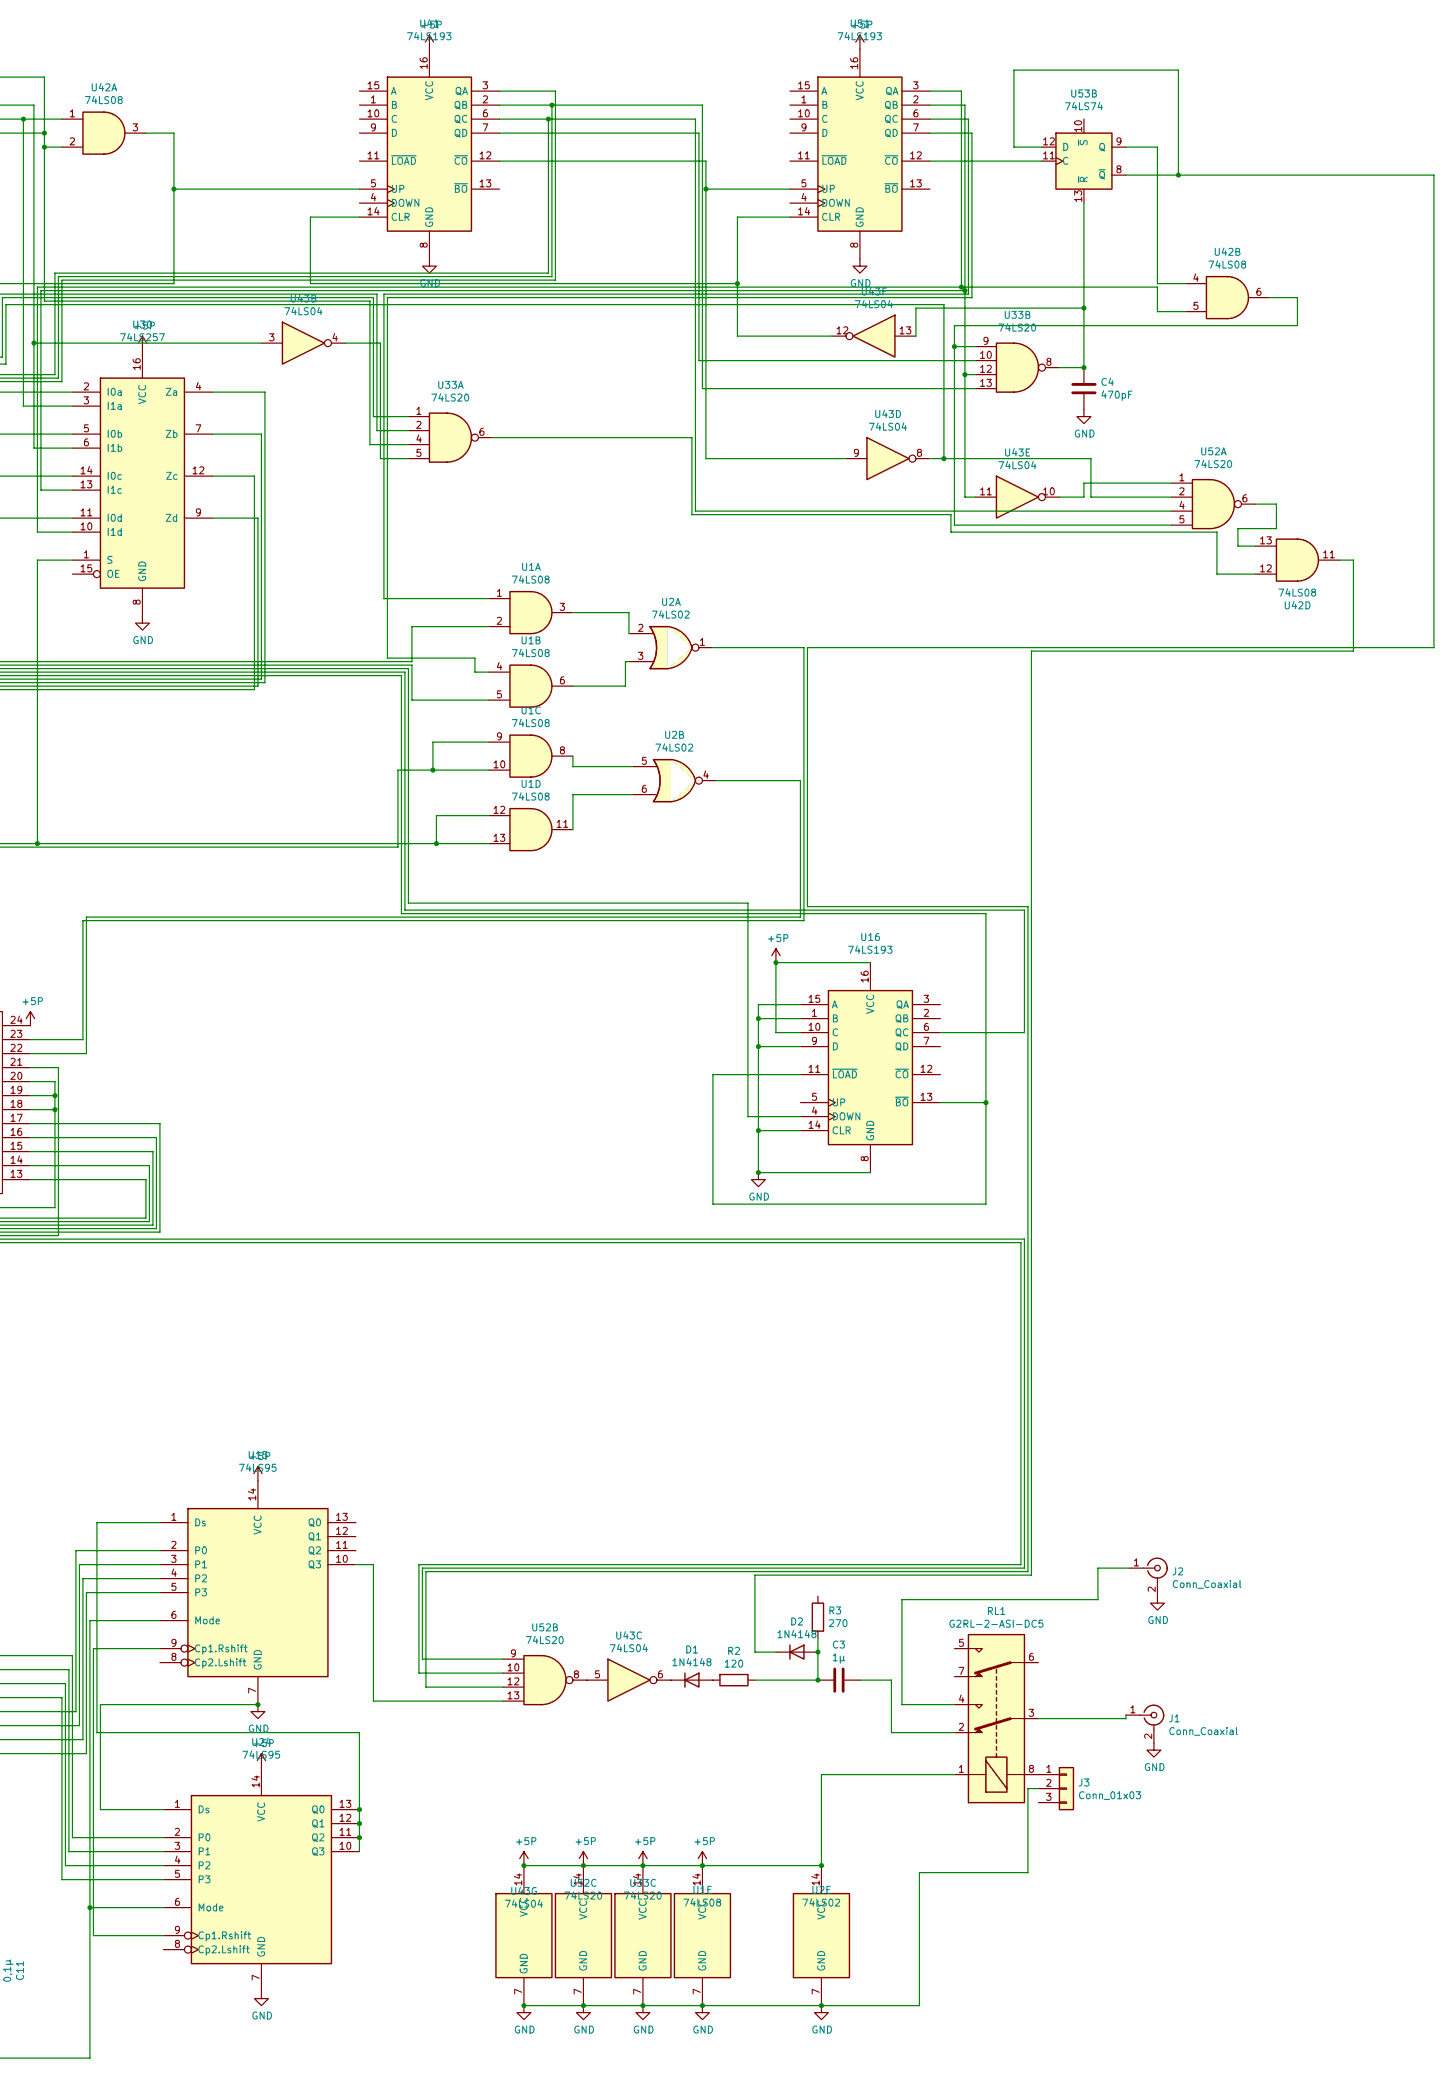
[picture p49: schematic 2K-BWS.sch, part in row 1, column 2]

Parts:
C1, C2, C4: 470pF; C_Disc_D3.0mm_W2.0mm_P2.50mm
C3: 1µ; C_Disc_D3.0mm_W2.0mm_P2.50mm
C5, C6, C7, C8, C9, C10, C11: 0,1µ; C_Disc_D3.0mm_W2.0mm_P2.50mm
D1, D2: 1N4148; D_DO-15_P10.16mm_Horizontal
IC21: 6116LA45DB; DIP-24_W15.24mm_LongPads; Manufacturer_Part_Number 6116LA45DB; Mouser Part Number 972-6116LA45DB
J1, J2: Conn_Coaxial; chinch
J3, J4, J5: Conn_01x03; PinSocket_1x03_P2.54mm_Vertical
R1: 510; R_Axial_DIN0207_L6.3mm_D2.5mm_P10.16mm_Horizontal
R2: 120; R_Axial_DIN0207_L6.3mm_D2.5mm_P10.16mm_Horizontal
R3: 270; R_Axial_DIN0207_L6.3mm_D2.5mm_P10.16mm_Horizontal
RL1: G2RL-2-ASI-DC5; Relay_DPDT_Omron_G2RL
U1, U42: 74LS08; DIP-14_W7.62mm_LongPads
U2: 74LS02; DIP-14_W7.62mm_LongPads
U10: DS8286D; DIP-20_W7.62mm_LongPads
U11, U43: 74LS04; DIP-14_W7.62mm_LongPads
U12, U13, U15, U24: 74LS95; DIP-14_W7.62mm_LongPads
U14: U2716; DIP-24_W15.24mm_LongPads
U16, U22, U32, U41, U51: 74LS193; DIP-16_W7.62mm_LongPads
U20: 74LS30; DIP-14_W7.62mm_LongPads
U23, U53: 74LS74; DIP-14_W7.62mm_LongPads
U30, U40: 74LS257; DIP-16_W7.62mm_LongPads
U33, U52: 74LS20; DIP-14_W7.62mm_LongPads
X1: K1520_2x29-AC; K1520_EFS2x29_DIN_male
Y1: 10500KHz; Crystal_HC49-4H_Vertical

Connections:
+5P: C5.2, C6.2, C7.2, C8.2, C9.2, C10.2, C11.2, IC21.24 (VCC), RL1.1, U1.14 (VCC), U2.14 (VCC), U10.20 (Vcc), U11.14 (VCC), U12.14 (VCC), U13.14 (VCC), U14.21 (Upp), U14.24 (Udd), U15.14 (VCC), U16.10 (C), U16.16 (VCC), U20.14 (VCC), U22.16 (VCC), U23.14 (VCC), U24.14 (VCC), U30.16 (VCC), U32.16 (VCC), U33.14 (VCC), U40.16 (VCC), U41.16 (VCC), U42.14 (VCC), U43.14 (VCC), U51.16 (VCC), U52.14 (VCC), U53.14 (VCC), X1.A29 (5P), X1.C29 (5P)
GND: C1.2, C2.2, C4.2, C5.1, C6.1, C7.1, C8.1, C9.1, C10.1, C11.1, IC21.12 (GND), IC21.18 (~CS), IC21.19 (A10), IC21.20 (~OE), J1.2 (Ext), J2.2 (Ext), J3.2, U1.7 (GND), U2.7 (GND), U10.10 (GND), U11.7 (GND), U12.7 (GND), U13.7 (GND), U14.12 (Uss), U14.18 (~CE), U14.20 (~OE), U15.7 (GND), U16.1 (B), U16.8 (GND), U16.9 (D), U16.14 (CLR), U16.15 (A), U20.7 (GND), U22.8 (GND), U22.14 (CLR), U23.7 (GND), U24.1 (Ds), U24.7 (GND), U30.8 (GND), U32.8 (GND), U33.7 (GND), U40.8 (GND), U41.8 (GND), U42.7 (GND), U43.7 (GND), U51.8 (GND), U52.7 (GND), U53.7 (GND), X1.A01 (GND), X1.A02 (GND), X1.C01 (GND), X1.C02 (GND), X1.C21 (GND), X1.C22 (GND)
unnamed: C1.1, U1.12, U1.13, U10.9 (~OE), U11.5, U20.8, U30.1 (S), U40.1 (S)
unnamed: C2.1, U32.14 (CLR), U41.5 (UP), U42.3
unnamed: C3.1, RL1.2
unnamed: C3.2, D2.2 (A), R2.1, R3.2
unnamed: C4.1, U33.8, U43.13, U53.13 (~R)
unnamed: D1.1 (K), U43.6
unnamed: D1.2 (A), R2.2
unnamed: D2.1 (K), U42.11
unnamed: IC21.1 (A7), U30.12 (Zc)
unnamed: IC21.2 (A6), U30.9 (Zd)
unnamed: IC21.3 (A5), U30.4 (Za)
unnamed: IC21.4 (A4), U30.7 (Zb)
unnamed: IC21.5 (A3), U40.12 (Zc)
unnamed: IC21.6 (A2), U40.9 (Zd)
unnamed: IC21.7 (A1), U40.4 (Za)
unnamed: IC21.8 (A0), U40.7 (Zb)
unnamed: IC21.9 (I/O0), U10.12 (Y8), U13.3 (P1)
unnamed: IC21.10 (I/O1), U10.13 (Y7), U12.4 (P2)
unnamed: IC21.11 (I/O2), U10.14 (Y6), U13.4 (P2)
unnamed: IC21.13 (I/O3), U10.15 (Y5), U12.5 (P3)
unnamed: IC21.14 (I/O_4), U10.16 (A4), U13.5 (P3)
unnamed: IC21.15 (I/O5), U10.17 (Y3), U12.2 (P0)
unnamed: IC21.16 (I/O6), U10.18 (Y2), U13.2 (P0)
unnamed: IC21.17 (I/O7), U10.19 (Y1), U12.3 (P1)
unnamed: IC21.21 (~WE), U42.8
unnamed: IC21.22 (A9), U2.4
unnamed: IC21.23 (A8), U2.1
unnamed: J1.1 (In), RL1.3
unnamed: J2.1 (In), RL1.4
unnamed: J3.1, RL1.8
unnamed: J4.1, U2.13
unnamed: J4.2, U10.11 (STB)
unnamed: J4.3, U2.11, U2.12, X1.C08 (~RD)
unnamed: J5.1, U16.6 (QC)
unnamed: J5.2, X1.A21 (CLK)
unnamed: R1.1, U11.11, Y1.1
unnamed: R1.2, U11.9, U11.10
unnamed: U1.1, U51.6 (QC)
unnamed: U1.2, X1.A14 (AB_08)
unnamed: U1.3, U2.2
unnamed: U1.4, U51.7 (QD)
unnamed: U1.5, X1.C14 (AB_09)
unnamed: U1.6, U2.3
unnamed: U1.8, U2.5
unnamed: U1.9, U1.10, U11.6, U42.9
unnamed: U1.11, U2.6
unnamed: U10.1 (A1), X1.A04 (DB_7)
unnamed: U10.2 (A2), X1.C04 (DB_6)
unnamed: U10.3 (A3), X1.A05 (DB_5)
unnamed: U10.4 (A4), X1.C05 (DB_4)
unnamed: U10.5 (A5), X1.A06 (DB_3)
unnamed: U10.6 (A6), X1.C06 (DB_2)
unnamed: U10.7 (A7), X1.A07 (DB_1)
unnamed: U10.8 (A8), X1.C07 (DB_0)
unnamed: U11.1, X1.A08 (~WR)
unnamed: U11.2, U42.10
unnamed: U11.3, X1.A09 (~MREQ)
unnamed: U11.4, U20.12
unnamed: U11.8, U16.4 (DOWN), Y1.2
unnamed: U12.6 (Mode), U13.6 (Mode), U15.6 (Mode), U24.6 (Mode)
unnamed: U12.10 (Q3), U14.2 (A6)
unnamed: U12.11 (Q2), U14.4 (A4)
unnamed: U12.12 (Q1), U14.19 (A10)
unnamed: U12.13 (Q0), U14.23 (A8)
unnamed: U13.10 (Q3), U14.1 (A7)
unnamed: U13.11 (Q2), U14.3 (A5)
unnamed: U13.12 (Q1), U14.5 (A3)
unnamed: U13.13 (Q0), U14.22 (A9)
unnamed: U14.6 (A2), U41.6 (QC), U52.4
unnamed: U14.7 (A1), U33.13, U41.2 (QB)
unnamed: U14.8 (A0), U41.3 (QA)
unnamed: U14.9 (D0), U24.2 (P0)
unnamed: U14.10 (D1), U24.3 (P1)
unnamed: U14.11 (D2), U24.4 (P2)
unnamed: U14.13 (D3), U24.5 (P3)
unnamed: U14.14 (D4), U15.2 (P0)
unnamed: U14.15 (D5), U15.3 (P1)
unnamed: U14.16 (D6), U15.4 (P2)
unnamed: U14.17 (D7), U15.5 (P3)
unnamed: U15.1 (Ds), U24.10 (Q3), U24.11 (Q2), U24.12 (Q1), U24.13 (Q0)
unnamed: U15.9 (Cp1.Rshift), U24.9 (Cp1.Rshift)
unnamed: U15.10 (Q3), U52.13
unnamed: U16.11 (~LOAD), U16.13 (~BO), U22.5 (UP), U23.3 (C), U23.11 (C)
unnamed: U20.1, X1.A13 (AB_10)
unnamed: U20.2, X1.C13 (AB_11)
unnamed: U20.3, X1.A12 (AB_12)
unnamed: U20.4, X1.C12 (AB_13)
unnamed: U20.5, X1.A11 (AB_14)
unnamed: U20.6, X1.C11 (AB_15)
unnamed: U20.11, X1.C09 (~MEMDI)
unnamed: U22.2 (QB), U40.3 (I1a)
unnamed: U22.3 (QA), U40.6 (I1b)
unnamed: U22.6 (QC), U33.1, U40.10 (I1d)
unnamed: U22.7 (QD), U33.2, U40.13 (I1c)
unnamed: U22.12 (~CO), U32.5 (UP)
unnamed: U23.2 (D), U23.9 (Q)
unnamed: U23.6 (~Q), U52.9
unnamed: U23.12 (D), U32.6 (QC), U33.4, U42.2
unnamed: U30.2 (I0a), X1.C17 (AB_05)
unnamed: U30.3 (I1a), U32.2 (QB), U42.1
unnamed: U30.5 (I0b), X1.A17 (AB_04)
unnamed: U30.6 (I1b), U32.3 (QA), U43.3
unnamed: U30.10 (I1d), U42.5, U51.3 (QA)
unnamed: U30.11 (I0d), X1.A16 (AB_06)
unnamed: U30.13 (I1c), U33.12, U43.11, U51.2 (QB)
unnamed: U30.14 (I0c), X1.C16 (AB_07)
unnamed: U33.5, U43.4
unnamed: U33.6, U42.12
unnamed: U33.9, U42.6, U52.5
unnamed: U33.10, U41.7 (QD)
unnamed: U40.2 (I0a), X1.C19 (AB_01)
unnamed: U40.5 (I0b), X1.A19 (AB_00)
unnamed: U40.11 (I0d), X1.A18 (AB_02)
unnamed: U40.14 (I0c), X1.C18 (AB_03)
unnamed: U41.12 (~CO), U43.9, U51.5 (UP)
unnamed: U41.14 (CLR), U43.12, U51.14 (CLR)
unnamed: U42.4, U53.9 (Q)
unnamed: U42.13, U52.6
unnamed: U43.5, U52.8
unnamed: U43.8, U52.2, U52.10
unnamed: U43.10, U52.1
unnamed: U51.12 (~CO), U53.11 (C)
unnamed: U52.12, U53.8 (~Q), U53.12 (D)
unnamed: X1.A10 (~IEO), X1.C10 (~IEI)
unnamed: X1.A27 (~BAO), X1.C27 (~BAI)

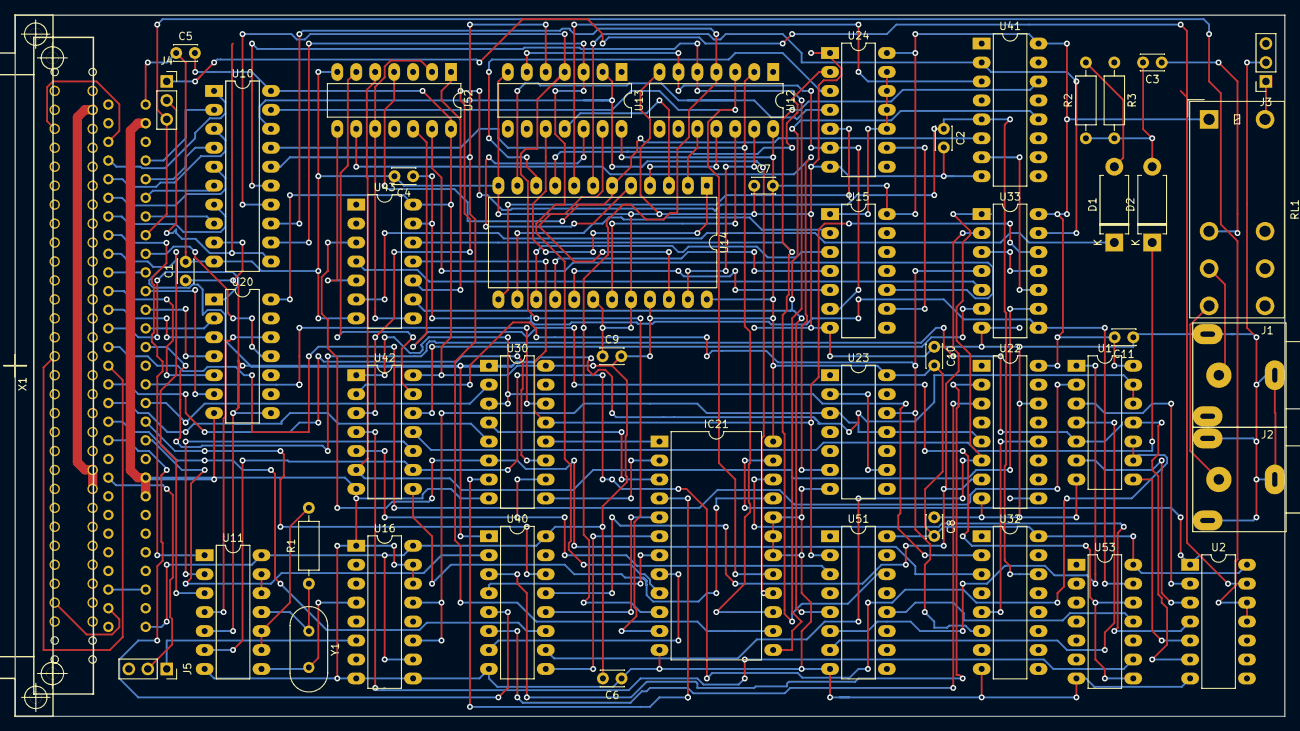
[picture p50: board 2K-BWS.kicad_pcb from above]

Board: 2 copper layers, 170.2 x 94.0 mm, 48 parts (0 on the bottom side), 127 nets.

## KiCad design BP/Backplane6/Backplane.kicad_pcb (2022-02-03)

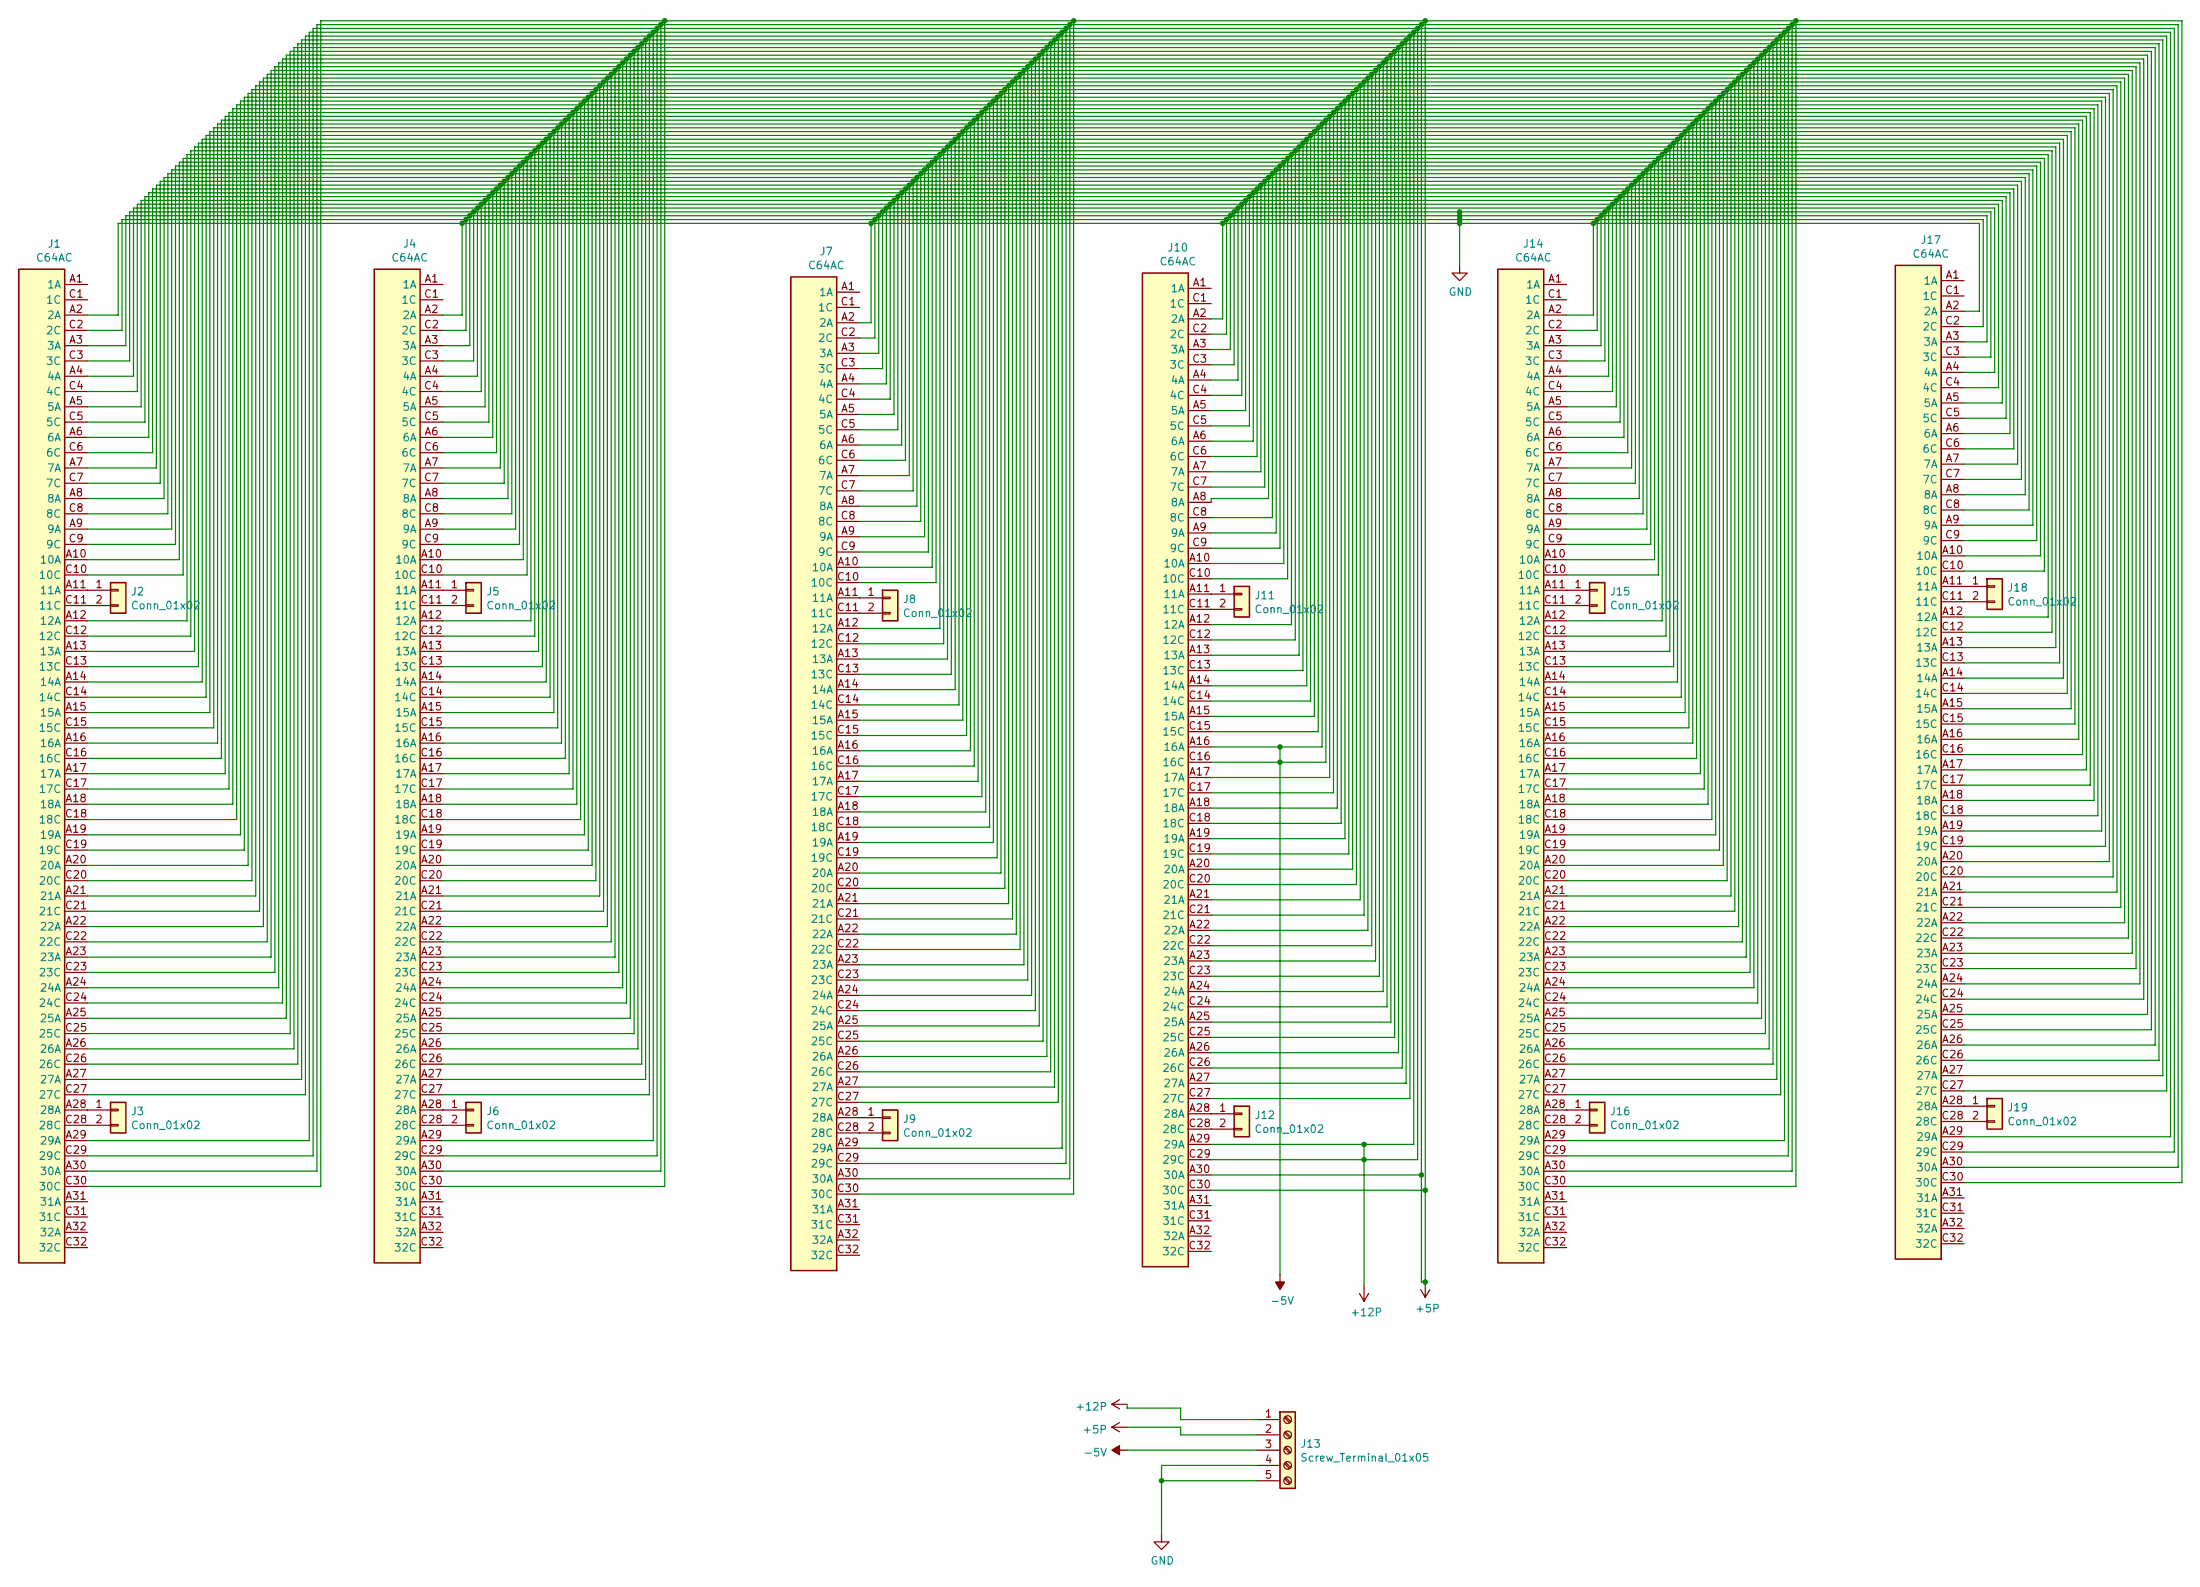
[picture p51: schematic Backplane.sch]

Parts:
J1, J4, J7, J10, J14, J17: C64AC; DIN41612_C_3x32_Female_Vertical_THT-Gross
J2, J3, J5, J6, J8, J9, J11, J12, J15, J16, J18, J19: Conn_01x02; PinSocket_1x02_P2.54mm_Vertical
J13: Screw_Terminal_01x05; JST_EH_B5B-EH-A_1x05_P2.50mm_Vertical

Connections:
+5P: J1.A30 (30A), J1.C30 (30C), J4.A30 (30A), J4.C30 (30C), J7.A30 (30A), J7.C30 (30C), J10.A30 (30A), J10.C30 (30C), J13.2, J14.A30 (30A), J14.C30 (30C), J17.A30 (30A), J17.C30 (30C)
+12P: J1.A29 (29A), J1.C29 (29C), J4.A29 (29A), J4.C29 (29C), J7.A29 (29A), J7.C29 (29C), J10.A29 (29A), J10.C29 (29C), J13.1, J14.A29 (29A), J14.C29 (29C), J17.A29 (29A), J17.C29 (29C)
-5V: J1.A16 (16A), J1.C16 (16C), J4.A16 (16A), J4.C16 (16C), J7.A16 (16A), J7.C16 (16C), J10.A16 (16A), J10.C16 (16C), J13.3, J14.A16 (16A), J14.C16 (16C), J17.A16 (16A), J17.C16 (16C)
GND: J1.A2 (2A), J1.A3 (3A), J1.C2 (2C), J1.C3 (3C), J4.A2 (2A), J4.A3 (3A), J4.C2 (2C), J4.C3 (3C), J7.A2 (2A), J7.A3 (3A), J7.C2 (2C), J7.C3 (3C), J10.A2 (2A), J10.A3 (3A), J10.C2 (2C), J10.C3 (3C), J13.4, J13.5, J14.A2 (2A), J14.A3 (3A), J14.C2 (2C), J14.C3 (3C), J17.A2 (2A), J17.A3 (3A), J17.C2 (2C), J17.C3 (3C)
unnamed: J1.A4 (4A), J4.A4 (4A), J7.A4 (4A), J10.A4 (4A), J14.A4 (4A), J17.A4 (4A)
unnamed: J1.A5 (5A), J4.A5 (5A), J7.A5 (5A), J10.A5 (5A), J14.A5 (5A), J17.A5 (5A)
unnamed: J1.A6 (6A), J4.A6 (6A), J7.A6 (6A), J10.A6 (6A), J14.A6 (6A), J17.A6 (6A)
unnamed: J1.A7 (7A), J4.A7 (7A), J7.A7 (7A), J10.A7 (7A), J14.A7 (7A), J17.A7 (7A)
unnamed: J1.A8 (8A), J4.A8 (8A), J7.A8 (8A), J10.A8 (8A), J14.A8 (8A), J17.A8 (8A)
unnamed: J1.A9 (9A), J4.A9 (9A), J7.A9 (9A), J10.A9 (9A), J14.A9 (9A), J17.A9 (9A)
unnamed: J1.A10 (10A), J4.A10 (10A), J7.A10 (10A), J10.A10 (10A), J14.A10 (10A), J17.A10 (10A)
unnamed: J1.A11 (11A), J2.1
unnamed: J1.A12 (12A), J4.A12 (12A), J7.A12 (12A), J10.A12 (12A), J14.A12 (12A), J17.A12 (12A)
unnamed: J1.A13 (13A), J4.A13 (13A), J7.A13 (13A), J10.A13 (13A), J14.A13 (13A), J17.A13 (13A)
unnamed: J1.A14 (14A), J4.A14 (14A), J7.A14 (14A), J10.A14 (14A), J14.A14 (14A), J17.A14 (14A)
unnamed: J1.A15 (15A), J4.A15 (15A), J7.A15 (15A), J10.A15 (15A), J14.A15 (15A), J17.A15 (15A)
unnamed: J1.A17 (17A), J4.A17 (17A), J7.A17 (17A), J10.A17 (17A), J14.A17 (17A), J17.A17 (17A)
unnamed: J1.A18 (18A), J4.A18 (18A), J7.A18 (18A), J10.A18 (18A), J14.A18 (18A), J17.A18 (18A)
unnamed: J1.A19 (19A), J4.A19 (19A), J7.A19 (19A), J10.A19 (19A), J14.A19 (19A), J17.A19 (19A)
unnamed: J1.A20 (20A), J4.A20 (20A), J7.A20 (20A), J10.A20 (20A), J14.A20 (20A), J17.A20 (20A)
unnamed: J1.A21 (21A), J4.A21 (21A), J7.A21 (21A), J10.A21 (21A), J14.A21 (21A), J17.A21 (21A)
unnamed: J1.A22 (22A), J4.A22 (22A), J7.A22 (22A), J10.A22 (22A), J14.A22 (22A), J17.A22 (22A)
unnamed: J1.A23 (23A), J4.A23 (23A), J7.A23 (23A), J10.A23 (23A), J14.A23 (23A), J17.A23 (23A)
unnamed: J1.A24 (24A), J4.A24 (24A), J7.A24 (24A), J10.A24 (24A), J14.A24 (24A), J17.A24 (24A)
unnamed: J1.A25 (25A), J4.A25 (25A), J7.A25 (25A), J10.A25 (25A), J14.A25 (25A), J17.A25 (25A)
unnamed: J1.A26 (26A), J4.A26 (26A), J7.A26 (26A), J10.A26 (26A), J14.A26 (26A), J17.A26 (26A)
unnamed: J1.A27 (27A), J4.A27 (27A), J7.A27 (27A), J10.A27 (27A), J14.A27 (27A), J17.A27 (27A)
unnamed: J1.A28 (28A), J3.1
unnamed: J1.C4 (4C), J4.C4 (4C), J7.C4 (4C), J10.C4 (4C), J14.C4 (4C), J17.C4 (4C)
unnamed: J1.C5 (5C), J4.C5 (5C), J7.C5 (5C), J10.C5 (5C), J14.C5 (5C), J17.C5 (5C)
unnamed: J1.C6 (6C), J4.C6 (6C), J7.C6 (6C), J10.C6 (6C), J14.C6 (6C), J17.C6 (6C)
unnamed: J1.C7 (7C), J4.C7 (7C), J7.C7 (7C), J10.C7 (7C), J14.C7 (7C), J17.C7 (7C)
unnamed: J1.C8 (8C), J4.C8 (8C), J7.C8 (8C), J10.C8 (8C), J14.C8 (8C), J17.C8 (8C)
unnamed: J1.C9 (9C), J4.C9 (9C), J7.C9 (9C), J10.C9 (9C), J14.C9 (9C), J17.C9 (9C)
unnamed: J1.C10 (10C), J4.C10 (10C), J7.C10 (10C), J10.C10 (10C), J14.C10 (10C), J17.C10 (10C)
unnamed: J1.C11 (11C), J2.2
unnamed: J1.C12 (12C), J4.C12 (12C), J7.C12 (12C), J10.C12 (12C), J14.C12 (12C), J17.C12 (12C)
unnamed: J1.C13 (13C), J4.C13 (13C), J7.C13 (13C), J10.C13 (13C), J14.C13 (13C), J17.C13 (13C)
unnamed: J1.C14 (14C), J4.C14 (14C), J7.C14 (14C), J10.C14 (14C), J14.C14 (14C), J17.C14 (14C)
unnamed: J1.C15 (15C), J4.C15 (15C), J7.C15 (15C), J10.C15 (15C), J14.C15 (15C), J17.C15 (15C)
unnamed: J1.C17 (17C), J4.C17 (17C), J7.C17 (17C), J10.C17 (17C), J14.C17 (17C), J17.C17 (17C)
unnamed: J1.C18 (18C), J4.C18 (18C), J7.C18 (18C), J10.C18 (18C), J14.C18 (18C), J17.C18 (18C)
unnamed: J1.C19 (19C), J4.C19 (19C), J7.C19 (19C), J10.C19 (19C), J14.C19 (19C), J17.C19 (19C)
unnamed: J1.C20 (20C), J4.C20 (20C), J7.C20 (20C), J10.C20 (20C), J14.C20 (20C), J17.C20 (20C)
unnamed: J1.C21 (21C), J4.C21 (21C), J7.C21 (21C), J10.C21 (21C), J14.C21 (21C), J17.C21 (21C)
unnamed: J1.C22 (22C), J4.C22 (22C), J7.C22 (22C), J10.C22 (22C), J14.C22 (22C), J17.C22 (22C)
unnamed: J1.C23 (23C), J4.C23 (23C), J7.C23 (23C), J10.C23 (23C), J14.C23 (23C), J17.C23 (23C)
unnamed: J1.C24 (24C), J4.C24 (24C), J7.C24 (24C), J10.C24 (24C), J14.C24 (24C), J17.C24 (24C)
unnamed: J1.C25 (25C), J4.C25 (25C), J7.C25 (25C), J10.C25 (25C), J14.C25 (25C), J17.C25 (25C)
unnamed: J1.C26 (26C), J4.C26 (26C), J7.C26 (26C), J10.C26 (26C), J14.C26 (26C), J17.C26 (26C)
unnamed: J1.C27 (27C), J4.C27 (27C), J7.C27 (27C), J10.C27 (27C), J14.C27 (27C), J17.C27 (27C)
unnamed: J1.C28 (28C), J3.2
unnamed: J4.A11 (11A), J5.1
unnamed: J4.A28 (28A), J6.1
unnamed: J4.C11 (11C), J5.2
unnamed: J4.C28 (28C), J6.2
unnamed: J7.A11 (11A), J8.1
unnamed: J7.A28 (28A), J9.1
unnamed: J7.C11 (11C), J8.2
unnamed: J7.C28 (28C), J9.2
unnamed: J10.A11 (11A), J11.1
unnamed: J10.A28 (28A), J12.1
unnamed: J10.C11 (11C), J11.2
unnamed: J10.C28 (28C), J12.2
unnamed: J14.A11 (11A), J15.1
unnamed: J14.A28 (28A), J16.1
unnamed: J14.C11 (11C), J15.2
unnamed: J14.C28 (28C), J16.2
unnamed: J17.A11 (11A), J18.1
unnamed: J17.A28 (28A), J19.1
unnamed: J17.C11 (11C), J18.2
unnamed: J17.C28 (28C), J19.2

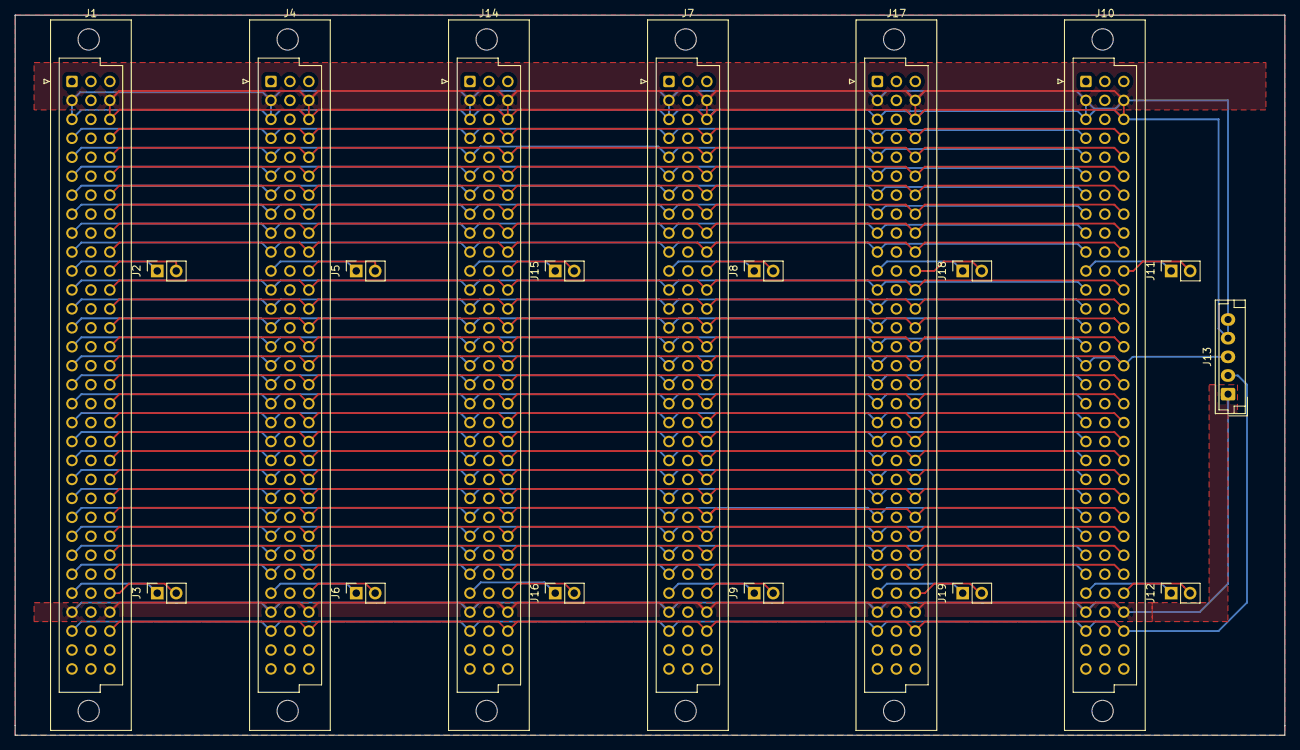
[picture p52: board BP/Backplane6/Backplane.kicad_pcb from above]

Board: 2 copper layers, 170.2 x 96.5 mm, 19 parts (0 on the bottom side), 72 nets.

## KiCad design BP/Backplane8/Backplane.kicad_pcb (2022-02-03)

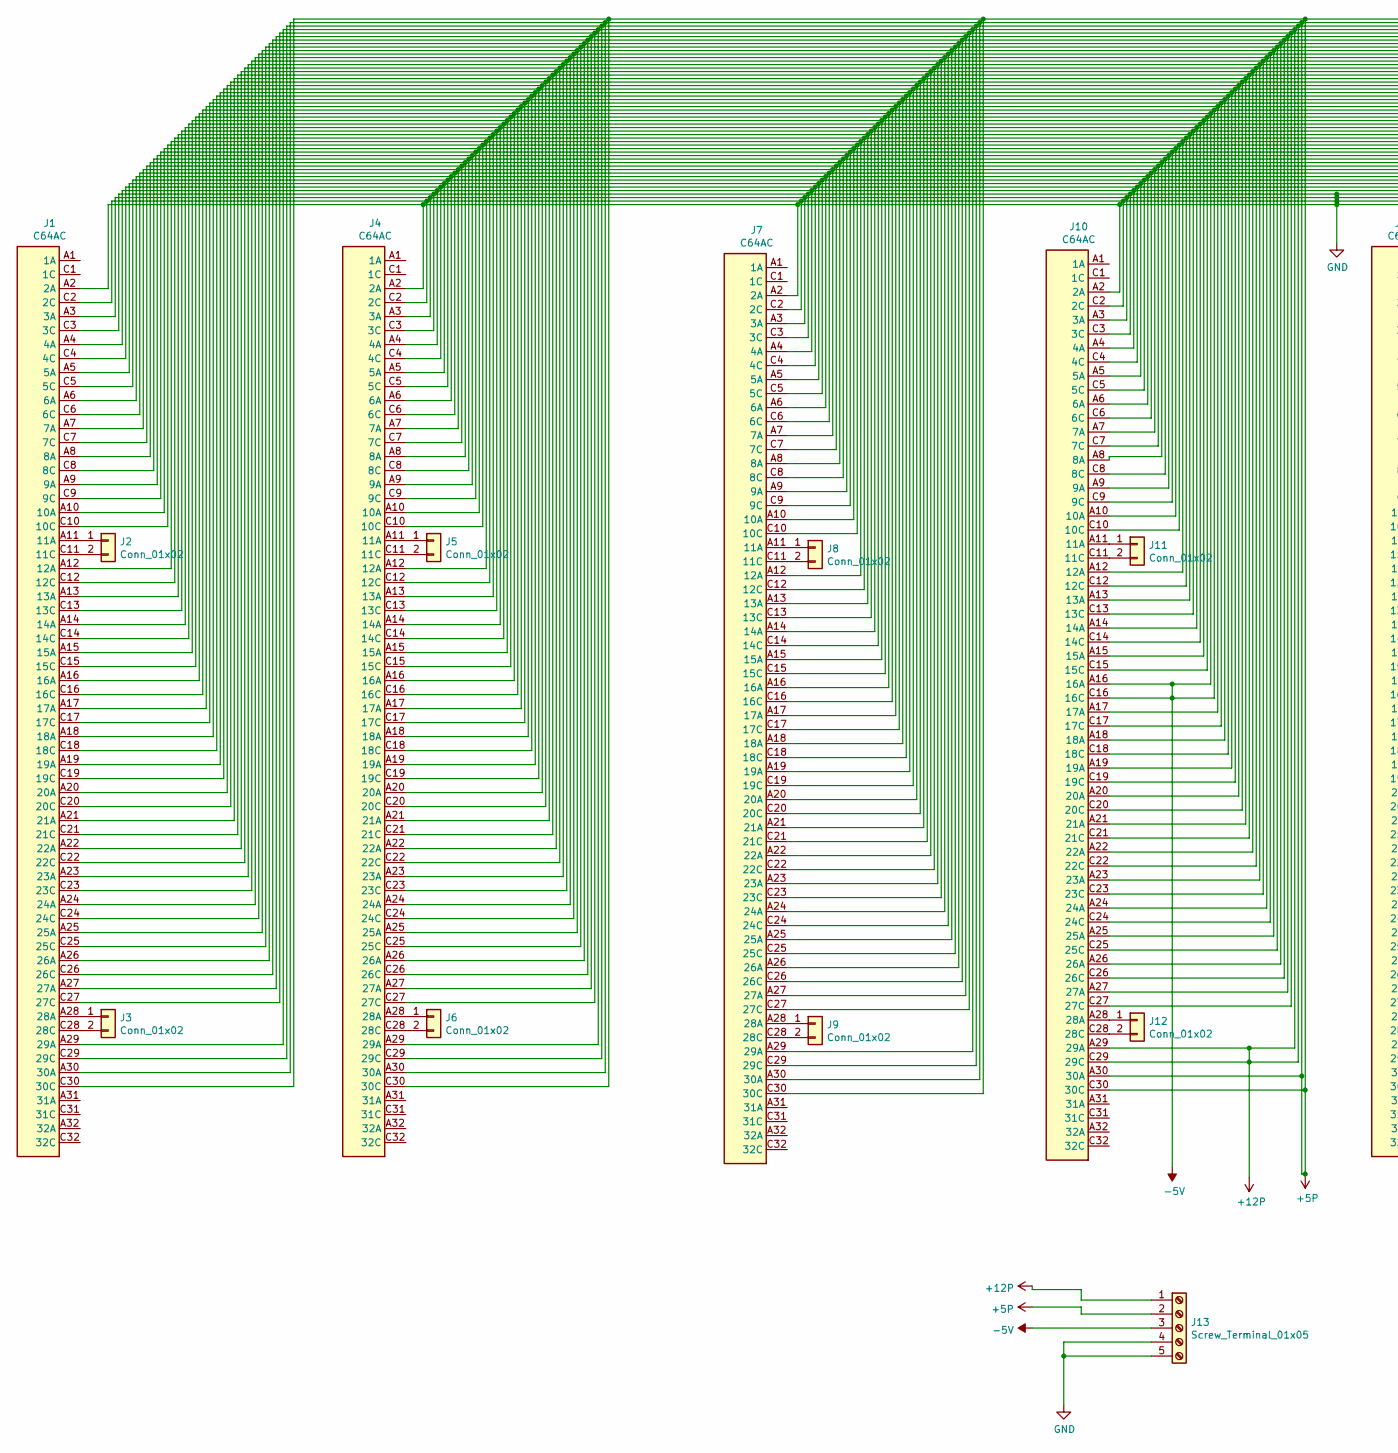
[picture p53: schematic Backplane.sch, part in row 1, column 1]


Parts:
J1, J4, J7, J10, J14, J17, J20, J23: C64AC; DIN41612_C_3x32_Female_Vertical_THT-Gross
J2, J3, J5, J6, J8, J9, J11, J12, J15, J16, J18, J19, J21, J22, J24, J25: Conn_01x02; PinSocket_1x02_P2.54mm_Vertical
J13: Screw_Terminal_01x05; JST_EH_B5B-EH-A_1x05_P2.50mm_Vertical

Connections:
+5P: J1.A30 (30A), J1.C30 (30C), J4.A30 (30A), J4.C30 (30C), J7.A30 (30A), J7.C30 (30C), J10.A30 (30A), J10.C30 (30C), J13.2, J14.A30 (30A), J14.C30 (30C), J17.A30 (30A), J17.C30 (30C), J20.A30 (30A), J20.C30 (30C), J23.A30 (30A), J23.C30 (30C)
+12P: J1.A29 (29A), J1.C29 (29C), J4.A29 (29A), J4.C29 (29C), J7.A29 (29A), J7.C29 (29C), J10.A29 (29A), J10.C29 (29C), J13.1, J14.A29 (29A), J14.C29 (29C), J17.A29 (29A), J17.C29 (29C), J20.A29 (29A), J20.C29 (29C), J23.A29 (29A), J23.C29 (29C)
-5V: J1.A16 (16A), J1.C16 (16C), J4.A16 (16A), J4.C16 (16C), J7.A16 (16A), J7.C16 (16C), J10.A16 (16A), J10.C16 (16C), J13.3, J14.A16 (16A), J14.C16 (16C), J17.A16 (16A), J17.C16 (16C), J20.A16 (16A), J20.C16 (16C), J23.A16 (16A), J23.C16 (16C)
GND: J1.A2 (2A), J1.A3 (3A), J1.C2 (2C), J1.C3 (3C), J4.A2 (2A), J4.A3 (3A), J4.C2 (2C), J4.C3 (3C), J7.A2 (2A), J7.A3 (3A), J7.C2 (2C), J7.C3 (3C), J10.A2 (2A), J10.A3 (3A), J10.C2 (2C), J10.C3 (3C), J13.4, J13.5, J14.A2 (2A), J14.A3 (3A), J14.C2 (2C), J14.C3 (3C), J17.A2 (2A), J17.A3 (3A), J17.C2 (2C), J17.C3 (3C), J20.A2 (2A), J20.A3 (3A), J20.C2 (2C), J20.C3 (3C), J23.A2 (2A), J23.A3 (3A), J23.C2 (2C), J23.C3 (3C)
unnamed: J1.A4 (4A), J4.A4 (4A), J7.A4 (4A), J10.A4 (4A), J14.A4 (4A), J17.A4 (4A), J20.A4 (4A), J23.A4 (4A)
unnamed: J1.A5 (5A), J4.A5 (5A), J7.A5 (5A), J10.A5 (5A), J14.A5 (5A), J17.A5 (5A), J20.A5 (5A), J23.A5 (5A)
unnamed: J1.A6 (6A), J4.A6 (6A), J7.A6 (6A), J10.A6 (6A), J14.A6 (6A), J17.A6 (6A), J20.A6 (6A), J23.A6 (6A)
unnamed: J1.A7 (7A), J4.A7 (7A), J7.A7 (7A), J10.A7 (7A), J14.A7 (7A), J17.A7 (7A), J20.A7 (7A), J23.A7 (7A)
unnamed: J1.A8 (8A), J4.A8 (8A), J7.A8 (8A), J10.A8 (8A), J14.A8 (8A), J17.A8 (8A), J20.A8 (8A), J23.A8 (8A)
unnamed: J1.A9 (9A), J4.A9 (9A), J7.A9 (9A), J10.A9 (9A), J14.A9 (9A), J17.A9 (9A), J20.A9 (9A), J23.A9 (9A)
unnamed: J1.A10 (10A), J4.A10 (10A), J7.A10 (10A), J10.A10 (10A), J14.A10 (10A), J17.A10 (10A), J20.A10 (10A), J23.A10 (10A)
unnamed: J1.A11 (11A), J2.1
unnamed: J1.A12 (12A), J4.A12 (12A), J7.A12 (12A), J10.A12 (12A), J14.A12 (12A), J17.A12 (12A), J20.A12 (12A), J23.A12 (12A)
unnamed: J1.A13 (13A), J4.A13 (13A), J7.A13 (13A), J10.A13 (13A), J14.A13 (13A), J17.A13 (13A), J20.A13 (13A), J23.A13 (13A)
unnamed: J1.A14 (14A), J4.A14 (14A), J7.A14 (14A), J10.A14 (14A), J14.A14 (14A), J17.A14 (14A), J20.A14 (14A), J23.A14 (14A)
unnamed: J1.A15 (15A), J4.A15 (15A), J7.A15 (15A), J10.A15 (15A), J14.A15 (15A), J17.A15 (15A), J20.A15 (15A), J23.A15 (15A)
unnamed: J1.A17 (17A), J4.A17 (17A), J7.A17 (17A), J10.A17 (17A), J14.A17 (17A), J17.A17 (17A), J20.A17 (17A), J23.A17 (17A)
unnamed: J1.A18 (18A), J4.A18 (18A), J7.A18 (18A), J10.A18 (18A), J14.A18 (18A), J17.A18 (18A), J20.A18 (18A), J23.A18 (18A)
unnamed: J1.A19 (19A), J4.A19 (19A), J7.A19 (19A), J10.A19 (19A), J14.A19 (19A), J17.A19 (19A), J20.A19 (19A), J23.A19 (19A)
unnamed: J1.A20 (20A), J4.A20 (20A), J7.A20 (20A), J10.A20 (20A), J14.A20 (20A), J17.A20 (20A), J20.A20 (20A), J23.A20 (20A)
unnamed: J1.A21 (21A), J4.A21 (21A), J7.A21 (21A), J10.A21 (21A), J14.A21 (21A), J17.A21 (21A), J20.A21 (21A), J23.A21 (21A)
unnamed: J1.A22 (22A), J4.A22 (22A), J7.A22 (22A), J10.A22 (22A), J14.A22 (22A), J17.A22 (22A), J20.A22 (22A), J23.A22 (22A)
unnamed: J1.A23 (23A), J4.A23 (23A), J7.A23 (23A), J10.A23 (23A), J14.A23 (23A), J17.A23 (23A), J20.A23 (23A), J23.A23 (23A)
unnamed: J1.A24 (24A), J4.A24 (24A), J7.A24 (24A), J10.A24 (24A), J14.A24 (24A), J17.A24 (24A), J20.A24 (24A), J23.A24 (24A)
unnamed: J1.A25 (25A), J4.A25 (25A), J7.A25 (25A), J10.A25 (25A), J14.A25 (25A), J17.A25 (25A), J20.A25 (25A), J23.A25 (25A)
unnamed: J1.A26 (26A), J4.A26 (26A), J7.A26 (26A), J10.A26 (26A), J14.A26 (26A), J17.A26 (26A), J20.A26 (26A), J23.A26 (26A)
unnamed: J1.A27 (27A), J4.A27 (27A), J7.A27 (27A), J10.A27 (27A), J14.A27 (27A), J17.A27 (27A), J20.A27 (27A), J23.A27 (27A)
unnamed: J1.A28 (28A), J3.1
unnamed: J1.C4 (4C), J4.C4 (4C), J7.C4 (4C), J10.C4 (4C), J14.C4 (4C), J17.C4 (4C), J20.C4 (4C), J23.C4 (4C)
unnamed: J1.C5 (5C), J4.C5 (5C), J7.C5 (5C), J10.C5 (5C), J14.C5 (5C), J17.C5 (5C), J20.C5 (5C), J23.C5 (5C)
unnamed: J1.C6 (6C), J4.C6 (6C), J7.C6 (6C), J10.C6 (6C), J14.C6 (6C), J17.C6 (6C), J20.C6 (6C), J23.C6 (6C)
unnamed: J1.C7 (7C), J4.C7 (7C), J7.C7 (7C), J10.C7 (7C), J14.C7 (7C), J17.C7 (7C), J20.C7 (7C), J23.C7 (7C)
unnamed: J1.C8 (8C), J4.C8 (8C), J7.C8 (8C), J10.C8 (8C), J14.C8 (8C), J17.C8 (8C), J20.C8 (8C), J23.C8 (8C)
unnamed: J1.C9 (9C), J4.C9 (9C), J7.C9 (9C), J10.C9 (9C), J14.C9 (9C), J17.C9 (9C), J20.C9 (9C), J23.C9 (9C)
unnamed: J1.C10 (10C), J4.C10 (10C), J7.C10 (10C), J10.C10 (10C), J14.C10 (10C), J17.C10 (10C), J20.C10 (10C), J23.C10 (10C)
unnamed: J1.C11 (11C), J2.2
unnamed: J1.C12 (12C), J4.C12 (12C), J7.C12 (12C), J10.C12 (12C), J14.C12 (12C), J17.C12 (12C), J20.C12 (12C), J23.C12 (12C)
unnamed: J1.C13 (13C), J4.C13 (13C), J7.C13 (13C), J10.C13 (13C), J14.C13 (13C), J17.C13 (13C), J20.C13 (13C), J23.C13 (13C)
unnamed: J1.C14 (14C), J4.C14 (14C), J7.C14 (14C), J10.C14 (14C), J14.C14 (14C), J17.C14 (14C), J20.C14 (14C), J23.C14 (14C)
unnamed: J1.C15 (15C), J4.C15 (15C), J7.C15 (15C), J10.C15 (15C), J14.C15 (15C), J17.C15 (15C), J20.C15 (15C), J23.C15 (15C)
unnamed: J1.C17 (17C), J4.C17 (17C), J7.C17 (17C), J10.C17 (17C), J14.C17 (17C), J17.C17 (17C), J20.C17 (17C), J23.C17 (17C)
unnamed: J1.C18 (18C), J4.C18 (18C), J7.C18 (18C), J10.C18 (18C), J14.C18 (18C), J17.C18 (18C), J20.C18 (18C), J23.C18 (18C)
unnamed: J1.C19 (19C), J4.C19 (19C), J7.C19 (19C), J10.C19 (19C), J14.C19 (19C), J17.C19 (19C), J20.C19 (19C), J23.C19 (19C)
unnamed: J1.C20 (20C), J4.C20 (20C), J7.C20 (20C), J10.C20 (20C), J14.C20 (20C), J17.C20 (20C), J20.C20 (20C), J23.C20 (20C)
unnamed: J1.C21 (21C), J4.C21 (21C), J7.C21 (21C), J10.C21 (21C), J14.C21 (21C), J17.C21 (21C), J20.C21 (21C), J23.C21 (21C)
unnamed: J1.C22 (22C), J4.C22 (22C), J7.C22 (22C), J10.C22 (22C), J14.C22 (22C), J17.C22 (22C), J20.C22 (22C), J23.C22 (22C)
unnamed: J1.C23 (23C), J4.C23 (23C), J7.C23 (23C), J10.C23 (23C), J14.C23 (23C), J17.C23 (23C), J20.C23 (23C), J23.C23 (23C)
unnamed: J1.C24 (24C), J4.C24 (24C), J7.C24 (24C), J10.C24 (24C), J14.C24 (24C), J17.C24 (24C), J20.C24 (24C), J23.C24 (24C)
unnamed: J1.C25 (25C), J4.C25 (25C), J7.C25 (25C), J10.C25 (25C), J14.C25 (25C), J17.C25 (25C), J20.C25 (25C), J23.C25 (25C)
unnamed: J1.C26 (26C), J4.C26 (26C), J7.C26 (26C), J10.C26 (26C), J14.C26 (26C), J17.C26 (26C), J20.C26 (26C), J23.C26 (26C)
unnamed: J1.C27 (27C), J4.C27 (27C), J7.C27 (27C), J10.C27 (27C), J14.C27 (27C), J17.C27 (27C), J20.C27 (27C), J23.C27 (27C)
unnamed: J1.C28 (28C), J3.2
unnamed: J4.A11 (11A), J5.1
unnamed: J4.A28 (28A), J6.1
unnamed: J4.C11 (11C), J5.2
unnamed: J4.C28 (28C), J6.2
unnamed: J7.A11 (11A), J8.1
unnamed: J7.A28 (28A), J9.1
unnamed: J7.C11 (11C), J8.2
unnamed: J7.C28 (28C), J9.2
unnamed: J10.A11 (11A), J11.1
unnamed: J10.A28 (28A), J12.1
unnamed: J10.C11 (11C), J11.2
unnamed: J10.C28 (28C), J12.2
unnamed: J14.A11 (11A), J15.1
unnamed: J14.A28 (28A), J16.1
unnamed: J14.C11 (11C), J15.2
unnamed: J14.C28 (28C), J16.2
unnamed: J17.A11 (11A), J18.1
unnamed: J17.A28 (28A), J19.1
unnamed: J17.C11 (11C), J18.2
unnamed: J17.C28 (28C), J19.2
unnamed: J20.A11 (11A), J21.1
unnamed: J20.A28 (28A), J22.1
unnamed: J20.C11 (11C), J21.2
unnamed: J20.C28 (28C), J22.2
unnamed: J23.A11 (11A), J24.1
unnamed: J23.A28 (28A), J25.1
unnamed: J23.C11 (11C), J24.2
unnamed: J23.C28 (28C), J25.2


Board: 2 copper layers, 170.2 x 96.5 mm, 25 parts (0 on the bottom side), 80 nets.

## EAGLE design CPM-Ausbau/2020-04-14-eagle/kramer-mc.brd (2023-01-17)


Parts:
8X1K: G08R; SIL9
C7: CPOL-EUE2-5; E2-5
IC1, IC2: 74LS138N; DIL16
IC6, IC19: 74LS00N; DIL14
IC8: Z80CPU; DIL40
IC9: Z80PIO; DIL40
IC17: 27512; DIL28
IC18: ATF16V8BP3; DIL20
IC21: LP621024CM; SOP32L
JP1: JP2E; JP2
LED1: TLLG4400; LED3MM
PIEPSER: EFBAA40D101
QG1: XO-14; DIL14S
R4: 1K; 0207/10
R28: 470; 0207/10
R29, R30, R31, R32, R33: 4k7; 0207/10
S1: 10-XX; B3F-10XX
SV1: ML34
SV2: ML6
SV3: ML26L
SV4: ML20

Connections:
4MHZ: JP1.1, QG1.8 (OUT)
/BUSRQ: SV4.2; also elsewhere on the board
/CSBWS: IC18.15 (O5), SV1.25; also elsewhere on the board
/CSRAM: IC18.19 (O1), IC21.22 (!CS1)
/CSROM: IC17.20 (!CE), IC18.16 (O4)
/IEI: SV1.16; also elsewhere on the board
/IEO: SV1.15; also elsewhere on the board
/IORQ: IC8.20 (IORQ), IC9.36 (IORQ), SV4.12; also elsewhere on the board
/M1: IC8.27 (M1), IC19.13 (I1); also elsewhere on the board
/MEMDI: IC18.9 (I8), SV1.14; also elsewhere on the board
/MREQ: IC8.19 (MREQ), IC18.7 (I6), SV1.13; also elsewhere on the board
/RD: IC8.21 (RD), IC17.22 (!OE), IC21.24 (!OE), SV1.12; also elsewhere on the board
/RESET: C7.+, IC6.9 (I0), IC8.26 (RESET), IC19.12 (I0), R31.1, S1.2 (S1), SV4.1; also elsewhere on the board
/WAIT: SV4.11; also elsewhere on the board
/WR: IC8.22 (WR), IC21.29 (!WE), SV1.11; also elsewhere on the board
A0: IC8.30 (A0), IC9.6 (PORTSEL), IC17.10 (A0), IC21.12 (A0), SV1.17; also elsewhere on the board
A1: IC8.31 (A1), IC9.5 (CONTSEL), IC17.9 (A1), IC21.11 (A1), SV1.18; also elsewhere on the board
A2: IC8.32 (A2), IC17.8 (A2), IC21.10 (A2), SV1.19; also elsewhere on the board
A3: IC8.33 (A3), IC17.7 (A3), IC21.9 (A3), SV1.20; also elsewhere on the board
A4: IC8.34 (A4), IC17.6 (A4), IC21.8 (A4), SV1.21; also elsewhere on the board
A5: IC8.35 (A5), IC17.5 (A5), IC21.7 (A5), SV1.22; also elsewhere on the board
A6: IC8.36 (A6), IC17.4 (A6), IC19.4 (I0), IC21.6 (A6), SV1.23; also elsewhere on the board
A7: IC8.37 (A7), IC17.3 (A7), IC19.5 (I1), IC21.5 (A7), SV1.24; also elsewhere on the board
A8: IC8.38 (A8), IC17.25 (A8), IC21.27 (A8), SV1.27; also elsewhere on the board
A9: IC8.39 (A9), IC17.24 (A9), IC21.26 (A9), SV1.28; also elsewhere on the board
A10: IC8.40 (A10), IC17.21 (A10), IC18.1 (CLK), IC21.23 (A10), SV1.29; also elsewhere on the board
A11: IC8.1 (A11), IC17.23 (A11), IC18.2 (I1), IC21.25 (A11), SV1.30; also elsewhere on the board
A12: IC8.2 (A12), IC17.2 (A12), IC18.3 (I2), IC21.4 (A12), SV1.31; also elsewhere on the board
A13: IC8.3 (A13), IC17.26 (A13), IC18.4 (I3), IC21.28 (A13), SV1.32; also elsewhere on the board
A14: IC8.4 (A14), IC17.27 (A14), IC18.5 (I4), IC21.3 (A14), SV1.33; also elsewhere on the board
A15: IC8.5 (A15), IC17.1 (A15), IC18.6 (I5), IC21.31 (A15), SV1.34; also elsewhere on the board
BRAM: IC6.13 (I1), IC18.18 (O2)
CLK: IC8.6 (CLK), IC9.25 (CLK), JP1.2
D0: IC8.14 (D0), IC9.19 (D0), IC17.11 (O0), IC21.13 (I/O0), SV1.3; also elsewhere on the board
D1: IC8.15 (D1), IC9.20 (D1), IC17.12 (O1), IC21.14 (I/O1), SV1.4; also elsewhere on the board
D2: IC8.12 (D2), IC9.1 (D2), IC17.13 (O2), IC21.15 (I/O2), SV1.5; also elsewhere on the board
D3: IC8.8 (D3), IC9.40 (D3), IC17.15 (O3), IC21.17 (I/O3), SV1.6; also elsewhere on the board
D4: IC8.7 (D4), IC9.39 (D4), IC17.16 (O4), IC21.18 (I/O4), SV1.7; also elsewhere on the board
D5: IC8.9 (D5), IC9.38 (D5), IC17.17 (O5), IC21.19 (I/O5), SV1.8; also elsewhere on the board
D6: IC8.10 (D6), IC9.3 (D6), IC17.18 (O6), IC21.20 (I/O6), SV1.9; also elsewhere on the board
D7: IC8.13 (D7), IC9.2 (D7), IC17.19 (O7), IC21.21 (I/O7), SV1.10; also elsewhere on the board
GND: C7.-, IC1.4 (G2A), IC1.8 (GND), IC2.4 (G2A), IC2.5 (G2B), IC2.8 (GND), IC6.7 (GND), IC8.29 (GND), IC9.11 (GND), IC17.14 (GND), IC18.10 (GND), IC19.7 (GND), IC21.16 (GND), QG1.7 (GND), R4.1, R28.1, S1.4 (P1), SV2.5, SV4.19, SV4.20; also elsewhere on the board
KA1: 8X1K.9, IC9.27 (B0), SV3.1
KA2: 8X1K.8, IC9.28 (B1), SV3.2
KA3: 8X1K.7, IC9.29 (B2), SV3.3
KA4: 8X1K.6, IC9.30 (B3), SV3.4
KA5: 8X1K.5, IC9.31 (B4), SV3.5
KA6: 8X1K.4, IC9.32 (B5), SV3.6
KA7: 8X1K.3, IC9.33 (B6), SV3.7
KA8: 8X1K.2, IC9.34 (B7), SV3.8
KB1: SV3.9
KB2: IC1.15 (Y0), SV3.10
KB3: SV3.11
KB4: IC1.14 (Y1), SV3.12
KB5: IC1.13 (Y2), SV3.13
KB6: IC1.12 (Y3), SV3.14
KB7: IC1.11 (Y4), SV3.15
KB8: IC1.10 (Y5), SV3.16
KB9: IC1.9 (Y6), SV3.17
KB10: IC1.7 (Y7), SV3.18
KB11: IC2.15 (Y0), SV3.19
KB12: IC2.14 (Y1), SV3.20
KB13: IC2.13 (Y2), SV3.21
KB14: IC2.12 (Y3), SV3.22
KC1: IC2.11 (Y4), SV3.23
KC2: IC2.10 (Y5), SV3.24
KC3: IC2.9 (Y6), SV3.25
KC4: IC2.7 (Y7), SV3.26
unnamed: IC19.9 (I0), IC19.10 (I1), IC19.11 (O)
unnamed: IC8.11 (VCC), IC18.20 (VCC)
unnamed: IC6.8 (O), IC6.12 (I0), LED1.A
unnamed: LED1.K (C), R28.2
unnamed: IC9.9 (A5), PIEPSER.1
unnamed: PIEPSER.2, R4.2
unnamed: IC9.4 (CE), IC19.6 (O)
unnamed: IC9.37 (M1), IC19.8 (O)
unnamed: IC8.17 (NMI), R29.1
unnamed: IC8.16 (INT), R30.1
unnamed: IC8.24 (WAIT), R33.1
unnamed: IC8.25 (BUSRQ), R32.1
PA1: IC1.1 (A), IC2.1 (A), IC9.14 (A1)
PA2: IC1.2 (B), IC2.2 (B), IC9.13 (A2)
PA3: IC1.3 (C), IC2.3 (C), IC9.12 (A3)
PA4: IC1.5 (G2B), IC2.6 (G1), IC9.10 (A4)
RAMDI: IC6.10 (I1), IC6.11 (O), IC18.8 (I7)
SERIAL-IN: IC9.7 (A7), SV2.3
SERIAL-OUT: IC9.15 (A0), SV2.4
TAKT: JP1.3, SV4.3; also elsewhere on the board
VCC: 8X1K.1, IC1.6 (G1), IC1.16 (VCC), IC2.16 (VCC), IC6.14 (VCC), IC9.24 (IEI), IC9.26 (VCC), IC17.28 (VCC), IC19.14 (VCC), IC21.2 (A16), IC21.30 (CS2), IC21.32 (VCC), QG1.14 (VCC), R29.2, R30.2, R31.2, R32.2, R33.2, SV1.1, SV1.2, SV2.1; also elsewhere on the board

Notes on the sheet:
GAL16V8 mit ADRDEC5.ABL
Tastatur: geschlachtete Cherry-Keyboard mit Stecker versehen. Bezeichnungen des Bus': Folienkontakte vlnr C4..C1 B14.. B1 A8..A1 B und C sind die Zeilen, A die Spalten B1, B3 und C4 gehen auf PIN7 74LS138 1
74LS138 1
74LS138 0
Kassetteninterface
128K SRAM M5M51108 gibt es nicht in EAGLE
Anzeige Speichumschaltung on: EPROM enabled off: EPROM disabled
JP Taktquelle 1-2: 4MHz von CPU-Karte 2-3 Takt von Bildschirmkarte


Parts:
C1: 1µF; C050-025X075
C13: 470p; C050-024X044
C14: 47p; C050-024X044
D2: 1N4148DO35-10; DO35-10
IC3: 6264 8KSRAM; DIL28-6
IC4: 74LS00N; DIL14
IC5: 74LS165N; DIL16
IC10': 74LS245N; DIL20
IC11, IC43: 74LS04N; DIL14
IC12-13': 74S373N; DIL20
IC14: 2716; DIL24
IC16: 74LS193N; DIL16
IC22, IC32, IC41, IC51: 74LS193; DIL16
IC23, IC53: 74LS74N; DIL14
IC30, IC40, IC50': 74LS157N; DIL16
IC33, IC52: 74LS20N; DIL14
IC42: 74LS08N; DIL14
J1: J2X2MM; 04C
JP2: JP1E; JP1
Q1: 10,7MHz; HC49U-V
R1: 510; 0309/12
R2: 1k; 0309/12
R3: 150; 0309/12
R27: 560; 0309/12
SV5: ML34
SV6: ML20
SV8: MA10-1

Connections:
93,75KHZ: IC22.12 (CO), IC32.5 (UP)
15625HZ-64µS: C13.1, IC32.14 (CLR), IC41.5 (UP), IC42.3 (O)
/A'4: IC33.5 (I3), IC43.4 (O)
/BUSRQ: SV6.2; also elsewhere on the board
/CSBWS: IC4.12 (I0), IC4.13 (I1), IC10'.19 (G), IC30.1 (!A!/B), IC40.1 (!A!/B), IC50'.1 (!A!/B), SV5.25; also elsewhere on the board
/IEI: SV5.16; also elsewhere on the board
/IEO: SV5.15; also elsewhere on the board
/IORQ: SV6.12; also elsewhere on the board
/MEMDI: SV5.14; also elsewhere on the board
/MREQ: SV5.13; also elsewhere on the board
/RD: IC10'.1 (DIR), SV5.12; also elsewhere on the board
/RESET: SV6.1; also elsewhere on the board
/WAIT: SV6.11; also elsewhere on the board
/WR: IC4.1 (I0), IC4.2 (I1), SV5.11; also elsewhere on the board
A0: IC40.2 (1A), SV5.17; also elsewhere on the board
A1: IC40.5 (2A), SV5.18; also elsewhere on the board
A2: IC40.11 (3A), SV5.19; also elsewhere on the board
A3: IC40.14 (4A), SV5.20; also elsewhere on the board
A4: IC30.2 (1A), SV5.21; also elsewhere on the board
A5: IC30.5 (2A), SV5.22; also elsewhere on the board
A6: IC30.11 (3A), SV5.23; also elsewhere on the board
A7: IC30.14 (4A), SV5.24; also elsewhere on the board
A8: IC50'.2 (1A), SV5.27; also elsewhere on the board
A9: IC50'.5 (2A), SV5.28; also elsewhere on the board
A10: IC50'.11 (3A), SV5.29; also elsewhere on the board
A11: IC50'.14 (4A), SV5.30; also elsewhere on the board
A12: SV5.31; also elsewhere on the board
A13: SV5.32; also elsewhere on the board
A14: SV5.33; also elsewhere on the board
A15: SV5.34; also elsewhere on the board
A'0: IC22.3 (QA), IC40.3 (1B)
A'1: IC22.2 (QB), IC40.6 (2B)
A'2: IC22.6 (QC), IC33.1 (I0), IC40.10 (3B)
A'3: IC22.7 (QD), IC33.2 (I1), IC40.13 (4B)
A'4: IC30.3 (1B), IC32.3 (QA), IC43.3 (I)
A'5: IC30.6 (2B), IC32.2 (QB), IC42.1 (I0)
A'6: IC30.10 (3B), SV8.2
A'7: IC30.13 (4B), SV8.4
A'8: IC50'.3 (1B), SV8.6
A'9: IC50'.6 (2B), SV8.8
A'10: IC50'.10 (3B), SV8.10
A'11: IC50'.13 (4B)
A''0: IC3.10 (A0), IC40.4 (1Y)
A''1: IC3.9 (A1), IC40.7 (2Y)
A''2: IC3.8 (A2), IC40.9 (3Y)
A''3: IC3.7 (A3), IC40.12 (4Y)
A''4: IC3.6 (A4), IC30.4 (1Y)
A''5: IC3.5 (A5), IC30.7 (2Y)
A''6: IC3.4 (A6), IC30.9 (3Y)
A''7: IC3.3 (A7), IC30.12 (4Y)
A''8: IC3.25 (A8), IC50'.4 (1Y)
A''9: IC3.24 (A9), IC50'.7 (2Y)
A''10: IC50'.9 (3Y), J1.1
A''11: IC50'.12 (4Y)
AUSTASTJEDEZWEITEZEILE: IC52.12 (I2), JP2.1
BA: IC43.5 (I), IC52.8 (O)
BILD: IC5.9 (QH), IC52.13 (I3)
BILDRAND49,75HZ: IC52.9 (I0), IC53.8 (!Q), IC53.12 (D)
BILDSYNCHRON: IC42.12 (I0), IC52.6 (O)
BLA: IC33.9 (I0), IC42.6 (O), IC52.4 (I2)
D0: IC10'.2 (A1), SV5.3; also elsewhere on the board
D1: IC10'.3 (A2), SV5.4; also elsewhere on the board
D2: IC10'.4 (A3), SV5.5; also elsewhere on the board
D3: IC10'.5 (A4), SV5.6; also elsewhere on the board
D4: IC10'.6 (A5), SV5.7; also elsewhere on the board
D5: IC10'.7 (A6), SV5.8; also elsewhere on the board
D6: IC10'.8 (A7), SV5.9; also elsewhere on the board
D7: IC10'.9 (A8), SV5.10; also elsewhere on the board
D'0: IC3.11 (I/O1), IC10'.18 (B1), IC12-13'.3 (1D)
D'1: IC3.12 (I/O2), IC10'.17 (B2), IC12-13'.4 (2D)
D'2: IC3.13 (I/O3), IC10'.16 (B3), IC12-13'.7 (3D)
D'3: IC3.15 (I/O4), IC10'.15 (B4), IC12-13'.8 (4D)
D'4: IC3.16 (I/O5), IC10'.14 (B5), IC12-13'.13 (5D)
D'5: IC3.17 (I/O6), IC10'.13 (B6), IC12-13'.14 (6D)
D'6: IC3.18 (I/O7), IC10'.12 (B7), IC12-13'.17 (7D)
D'7: IC3.19 (I/O8), IC10'.11 (B8), IC12-13'.18 (8D)
D''0: IC12-13'.2 (1Q), IC14.5 (A3)
D''1: IC12-13'.5 (2Q), IC14.4 (A4)
D''2: IC12-13'.6 (3Q), IC14.3 (A5)
D''3: IC12-13'.9 (4Q), IC14.2 (A6)
D''4: IC12-13'.12 (5Q), IC14.1 (A7)
D''5: IC12-13'.15 (6Q), IC14.23 (A8)
D''6: IC12-13'.16 (7Q), IC14.22 (A9)
D''7: IC12-13'.19 (8Q), IC14.19 (A10)
GND: C13.2, C14.2, IC3.20 (!CS1), IC4.7 (GND), IC5.8 (GND), IC5.15 (INH), IC10'.10 (GND), IC11.7 (GND), IC12-13'.1 (OC), IC12-13'.10 (GND), IC14.12 (GND), IC14.18 (!CE), IC14.20 (!OE), IC16.8 (GND), IC16.9 (D), IC16.14 (CLR), IC16.15 (A), IC22.8 (GND), IC22.14 (CLR), IC23.7 (GND), IC30.8 (GND), IC30.15 (G), IC32.8 (GND), IC33.7 (GND), IC40.8 (GND), IC40.15 (G), IC41.8 (GND), IC42.7 (GND), IC43.7 (GND), IC50'.8 (GND), IC50'.15 (G), IC51.8 (GND), IC52.7 (GND), IC53.7 (GND), R2.2, SV6.19, SV6.20; also elsewhere on the board
IC41-QD: IC33.10 (I1), IC41.7 (QD), IC43.9 (I), SV8.1
IC51-QA: IC42.5 (I1), IC51.3 (QA), SV8.3
IC51-QB: IC33.12 (I2), IC43.11 (I), IC51.2 (QB), SV8.5
IC51-QC: IC51.6 (QC), SV8.7
IC51-QD: IC51.7 (QD), SV8.9
unnamed: IC43.8 (O), IC52.2 (I1), JP2.2
unnamed: IC41.12 (CO), IC51.5 (UP)
unnamed: IC23.12 (D), IC32.6 (QC), IC33.4 (I2), IC42.2 (I1)
unnamed: IC23.2 (D), IC23.9 (Q)
unnamed: IC41.14 (CLR), IC43.12 (O), IC51.14 (CLR)
unnamed: IC51.12 (CO), IC53.11 (CLK)
unnamed: IC3.21 (A10), J1.2
unnamed: IC42.4 (I0), IC53.9 (Q)
unnamed: IC4.3 (O), IC4.4 (I0)
unnamed: C14.1, IC33.8 (O), IC43.13 (I), IC53.13 (CLR)
unnamed: IC43.10 (O), IC52.1 (I0)
unnamed: IC5.2 (CLK), IC11.9 (I), IC11.10 (O), R1.1
unnamed: IC11.12 (O), IC12-13'.11 (ENC)
unnamed: D2.A, IC43.6 (O)
unnamed: IC11.8 (O), IC16.4 (DN), Q1.2
unnamed: IC11.11 (I), Q1.1, R1.2
unnamed: IC5.1 (SH/!LD), IC11.13 (I), IC16.11 (LD), IC16.13 (BO)
unnamed: D2.C, R3.2
unnamed: C1.2, R2.1, R3.1, R27.1
unnamed: IC4.5 (I1), IC4.11 (O)
unnamed: IC3.22 (!OE), IC4.8 (O)
unnamed: IC3.27 (!WE), IC4.6 (O), IC4.9 (I0), IC4.10 (I1)
O0: IC5.6 (H), IC14.9 (O0)
O1: IC5.5 (G), IC14.10 (O1)
O2: IC5.4 (F), IC14.11 (O2)
O3: IC5.3 (E), IC14.13 (O3)
O4: IC5.14 (D), IC14.14 (O4)
O5: IC5.13 (C), IC14.15 (O5)
O6: IC5.12 (B), IC14.16 (O6)
O7: IC5.11 (A), IC14.17 (O7)
R1: IC14.8 (A0), IC41.3 (QA)
R2: IC14.7 (A1), IC33.13 (I3), IC41.2 (QB)
R4: IC14.6 (A2), IC41.6 (QC), IC52.5 (I3)
SYNC: IC42.11 (O), R27.2
TAKT: IC16.6 (QC), IC22.5 (UP), IC23.3 (CLK), IC23.11 (CLK), SV6.3; also elsewhere on the board
VCC: IC3.2 (A12), IC3.23 (A11), IC3.26 (CS2), IC3.28 (VCC), IC4.14 (VCC), IC5.16 (VCC), IC10'.20 (VCC), IC11.14 (VCC), IC12-13'.20 (VCC), IC14.21 (VPP), IC14.24 (VCC), IC16.1 (B), IC16.10 (C), IC16.16 (VCC), IC22.16 (VCC), IC23.14 (VCC), IC30.16 (VCC), IC32.16 (VCC), IC33.14 (VCC), IC40.16 (VCC), IC41.16 (VCC), IC42.14 (VCC), IC43.14 (VCC), IC50'.16 (VCC), IC51.16 (VCC), IC52.14 (VCC), IC53.14 (VCC), J1.3, SV5.1, SV5.2; also elsewhere on the board
VSS: IC3.14 (VSS)
ZEILENRAND: IC23.6 (!Q), IC52.10 (I1)
ZEILENSYNCHRON: IC33.6 (O), IC42.13 (I1)

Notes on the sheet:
Alternative zu 2xD195
bei 74LS165 negiert
A[0..15] Adreßbus CPU A'[0..15] Adeßbus für BWS A''[0..15] Adreßbus von Zeitbasis
Bildwiederholspeicher
Zeichengenerator
3 Multiplexer für max 8kB BWS
Quarz A B C D Teiler 9MHz 1 0 1 0 1:6 10,5MHz 0 1 1 0 1:7 12MHz 1 1 1 0 1:8
BAS-Mischer nach ; AVR-Video V6.3 40x25 ; Jan Baare 10.10.06 ; ; ATMEGA-8 16MHZ
A[0..15]: Adreßbus CPU A'[0..15]: von Zeitbasis erzeugte Adressen A''[0..15]: Adreßbus Bildwiederholspeicher
Dunkeltastung jede zweite Zeile oder A'6 bei 2k BWS
16:1
6:1
für Dunkeltastung jede zweite Zeile bei 1k BWS Jumper setzen
BS 1k 2k
1k BWS 2-3 4-5 6-7 8-9 2k BWS 1-2 3-4 5-6 7-8 9-10 mit Jumper verbinden
314:1


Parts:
C9: 100n; C025-025X050
C10, C11: 1µ; E2,5-6E
C12: 470n; C150-064X183
D5, D6: 1N4148DO35-10; DO35-10
IC15: D100; DIL14
R48, R53: 470; 0207/10
R50, R56, R58: 1k; 0207/10
R51: 12k; 0207/10
R52: 47k; 0207/10
R54: 10k; 0207/10
R55: 2k0; 0207/10
R57: 160; 0207/10
R59: 6k8; 0207/10
R60: 22k; 0207/10
R61: 180; 0207/10
SV7: ML6
T1, T3: BC547; TO92
T4: BC337; TO92
U$1: MB111; DIL8
X1: MAB5SH

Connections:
GND: C11.-, D6.A, IC15.7 (GND), R51.1, R53.1, R55.2, R59.2, SV7.5, T1.1 (E), T4.1 (E), U$1.6 (GND1), X1.2; also elsewhere on the board
unnamed: IC15.6 (O), SV7.3
unnamed: SV7.4, U$1.2 (C)
unnamed: R48.2, X1.3
unnamed: C9.1, R48.1
unnamed: C9.2, R51.2, R52.1, T4.2 (B)
unnamed: R50.1, T3.2 (B), T4.3 (C)
unnamed: R57.1, U$1.1 (A)
unnamed: C10.+, R52.2, R53.2, T3.1 (E)
unnamed: IC15.1 (I0), IC15.2 (I1), R58.2, U$1.5 (OUT1)
unnamed: C10.-, D5.A, D6.C
unnamed: C11.+, D5.C, R54.1, R55.1
unnamed: R60.2, X1.1
unnamed: R54.2, T1.2 (B)
unnamed: IC15.4 (I0), IC15.5 (I1), R56.2, T1.3 (C)
unnamed: IC15.9 (I0), IC15.10 (I1), IC15.11 (O), R61.2
unnamed: C12.1, IC15.13 (I1), R61.1
unnamed: C12.2, IC15.8 (O), R59.1, R60.1
unnamed: IC15.3 (O), IC15.12 (I0)
PE: X1.PE, X1.PE@ (PE)
VCC: IC15.14 (VCC), R50.2, R56.1, R57.2, R58.1, SV7.1, T3.3 (C), U$1.7 (VCC1); also elsewhere on the board

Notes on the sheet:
zur CPU-Platine
Kassettenrekorder


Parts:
C2, C3: 22µ/10V; E2,5-5
C4: 2n2; C025-025X050
C5: 220p; C025-025X050
C6: 470p; C025-025X050
D3, D4: 1N4148DO35-7; DO35-7
FDC1: FDCU8272; DIL40
FDC4: 74LS193; DIL16
FDC5: 74LS138N; DIL16
FDC7: 74LS175N; DIL16
FDC8, FDC13: 74LS04N; DIL14
FDC9: 74LS32N; DIL14
FDC10: 74LS37N; DIL14
FDC11: 74LS02N; DIL14
FDC12: 74LS06N; DIL14
FDCX1: ML34
FDCX2: ML20
N1, N2: A302; DIL04
Q2: 4MHz; HC49U-V
R5: 4k7; 0207/10
R6: 1K; 0207/10
R7, R8, R11, R12, R13, R14, R19: 220; 0207/10
R9, R10: 220k; 0207/10
R15, R16, R17, R18, R20: 330; 0207/10
R21, R22, R23, R24: 1k; 0207/10
R25, R26: 470; 0207/10
SV9: ML34

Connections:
/BUSRQ: FDCX2.2; also elsewhere on the board
/CSBWS: FDCX1.25; also elsewhere on the board
/DIR: FDC12.12 (O), SV9.18
/DRVSA: FDC10.3 (O), SV9.14
/DRVSB: FDC10.6 (O), SV9.12
/IEI: FDCX1.16; also elsewhere on the board
/IEO: FDCX1.15; also elsewhere on the board
/INDEX: FDC8.13 (I), R11.2, R15.1, SV9.8
/IORQ: FDC9.2 (I1), FDC9.12 (I0), FDCX2.10; also elsewhere on the board
/M1: FDC13.3 (I), FDCX2.13; also elsewhere on the board
/MEMDI: FDCX1.14; also elsewhere on the board
/MOTEA: N2.4 (OUT), SV9.10
/MOTEB: N1.4 (OUT), SV9.16
/MREQ: FDCX1.13; also elsewhere on the board
/RD: FDC9.1 (I0), FDCX1.12; also elsewhere on the board
/RDATA: FDC9.5 (I1), FDC10.10 (I1), R19.2, R20.2, SV9.30
/READY: FDC13.13 (I), R13.1, R17.2, SV9.34
/RESET: FDC7.1 (CLR), FDC10.13 (I1), FDCX2.1; also elsewhere on the board
/SIDE1: FDC12.6 (O), SV9.32
/STEP: FDC12.8 (O), SV9.20
/TRACK0: FDC11.6 (I1), R12.2, R16.2, SV9.26
/WAIT: FDCX2.9; also elsewhere on the board
/WDATE: FDC12.4 (O), SV9.22
/WGATE: FDC12.10 (O), SV9.24
/WPT: FDC13.11 (I), R14.2, R18.2, SV9.28
/WR: FDC9.13 (I1), FDCX1.11; also elsewhere on the board
A0: FDC1.5 (A0), FDCX1.17; also elsewhere on the board
A1: FDC5.1 (A), FDCX1.18; also elsewhere on the board
A2: FDC5.2 (B), FDCX1.19; also elsewhere on the board
A3: FDC5.3 (C), FDCX1.20; also elsewhere on the board
A4: FDC5.6 (G1), FDCX1.21; also elsewhere on the board
A5: FDCX1.22; also elsewhere on the board
A6: FDCX1.23; also elsewhere on the board
A7: FDC5.4 (G2A), FDCX1.24; also elsewhere on the board
A8: FDCX1.27; also elsewhere on the board
A9: FDCX1.28; also elsewhere on the board
A10: FDCX1.29; also elsewhere on the board
A11: FDCX1.30; also elsewhere on the board
A12: FDCX1.31; also elsewhere on the board
A13: FDCX1.32; also elsewhere on the board
A14: FDCX1.33; also elsewhere on the board
A15: FDCX1.34; also elsewhere on the board
D0: FDC1.6 (D0), FDC7.4 (D1), FDCX1.3; also elsewhere on the board
D1: FDC1.7 (D1), FDC7.5 (D2), FDCX1.4; also elsewhere on the board
D2: FDC1.8 (D2), FDCX1.5; also elsewhere on the board
D3: FDC1.9 (D3), FDCX1.6; also elsewhere on the board
D4: FDC1.10 (D4), FDC7.12 (D3), FDCX1.7; also elsewhere on the board
D5: FDC1.11 (D5), FDC7.13 (D4), FDCX1.8; also elsewhere on the board
D6: FDC1.12 (D6), FDCX1.9; also elsewhere on the board
D7: FDC1.13 (D7), FDCX1.10; also elsewhere on the board
GND: C2.-, C3.-, C5.1, C6.2, FDC1.20 (GND), FDC4.8 (GND), FDC4.10 (C), FDC4.14 (CLR), FDC5.8 (GND), FDC7.8 (GND), FDC8.7 (GND), FDC9.7 (GND), FDC10.7 (GND), FDC11.7 (GND), FDC12.7 (GND), FDC13.7 (GND), FDCX2.19, FDCX2.20, N1.3 (GND), N2.3 (GND), R15.2, R16.1, R17.1, R18.1, R20.1, SV9.1, SV9.3, SV9.5, SV9.7, SV9.9, SV9.11, SV9.13, SV9.15, SV9.17, SV9.19, SV9.21, SV9.23, SV9.25, SV9.27, SV9.29, SV9.31, SV9.33; also elsewhere on the board
MA: FDC7.6 (!Q2), R8.2
MB: FDC7.3 (!Q1), R7.2
unnamed: FDC1.14 (DRQ), R5.1
unnamed: FDC1.2 (RD), FDC9.3 (O)
unnamed: FDC1.15 (DACK), R6.1
unnamed: FDC7.14 (!Q4), FDC10.12 (I0)
unnamed: FDC1.29 (DS0), FDC10.2 (I1), FDC13.9 (I)
unnamed: FDC1.28 (DS1), FDC13.5 (I)
unnamed: FDC10.1 (I0), FDC10.4 (I0), FDC13.6 (O)
unnamed: FDC10.5 (I1), FDC13.8 (O)
unnamed: D3.C, R7.1
unnamed: C2.+, D3.A, N1.2 (IN), R9.1
unnamed: C3.+, D4.A, N2.2 (IN), R10.1
unnamed: D4.C, R8.1
unnamed: FDC1.17 (INDEX), FDC8.12 (O)
unnamed: FDC1.33 (FLT/T0), FDC11.4 (O)
unnamed: FDC1.35 (READY), FDC13.12 (O)
unnamed: FDC1.34 (WP/TS), FDC13.10 (O)
unnamed: FDC11.10 (O), FDC12.9 (I)
unnamed: FDC11.8 (I0), FDC12.2 (O), R21.2
unnamed: FDC11.5 (I0), FDC11.9 (I1), FDC13.2 (O)
unnamed: C4.1, FDC8.4 (O), R22.2
unnamed: FDC8.3 (I), Q2.1, R22.1
unnamed: FDC8.6 (O), FDC8.9 (I), Q2.2, R23.1
unnamed: C4.2, FDC8.5 (I), R23.2
unnamed: FDC1.19 (CLK), FDC4.4 (DN), FDC8.8 (O)
unnamed: FDC4.1 (B), FDC4.5 (UP), FDC4.15 (A), R24.2
unnamed: FDC1.22 (DW), FDC4.7 (QD), FDC4.9 (D)
unnamed: FDC4.3 (QA), FDC9.9 (I0)
unnamed: FDC4.2 (QB), FDC9.10 (I1)
unnamed: FDC4.6 (QC), FDC8.11 (I)
unnamed: FDC9.8 (O), FDC11.3 (I1)
unnamed: FDC8.10 (O), FDC11.2 (I0)
unnamed: FDC8.1 (I), FDC9.6 (O)
unnamed: FDC10.8 (O), R25.1
unnamed: C5.2, FDC9.4 (I0), R25.2
unnamed: FDC1.39 (/RWSEEK), FDC13.1 (I)
unnamed: FDC1.37 (FR/STP), FDC12.1 (I)
unnamed: FDC1.30 (WRDATA), FDC12.3 (I)
unnamed: FDC1.27 (HDSEL), FDC12.5 (I)
unnamed: FDC1.25 (WE), FDC12.11 (I)
unnamed: FDC1.38 (LCT/DR), FDC12.13 (I)
unnamed: FDC1.3 (WR), FDC9.11 (O), R26.1
unnamed: FDC1.1 (RESET), FDC10.11 (O)
unnamed: FDC1.16 (TC), FDC7.10 (Q3)
unnamed: FDC7.9 (CLK), FDC11.13 (O)
unnamed: C6.1, FDC11.11 (I0), R26.2
unnamed: FDC5.5 (G2B), FDC13.4 (O)
unnamed: FDC1.4 (CS), FDC5.9 (Y6)
unnamed: FDC5.15 (Y0), FDC11.12 (I1)
RDDATA: FDC1.23 (RDDATA), FDC8.2 (O)
TAKT: FDCX2.3; also elsewhere on the board
VCC: FDC1.40 (VCC), FDC4.16 (VCC), FDC5.16 (VCC), FDC7.16 (VCC), FDC8.14 (VCC), FDC9.14 (VCC), FDC10.14 (VCC), FDC11.14 (VCC), FDC12.14 (VCC), FDC13.14 (VCC), FDCX1.1, FDCX1.2, N1.1 (VCC), N2.1 (VCC), R5.2, R6.2, R9.2, R10.2, R11.1, R12.1, R13.2, R14.1, R19.1, R21.1, R24.1; also elsewhere on the board
VCO: FDC1.24 (VCO), FDC10.9 (I0)
WRCLK: FDC1.21 (WRCLK), FDC11.1 (O)

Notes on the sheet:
Kramer I/O Adressen: AAAAAAA A 76543721 0 01111000 X TC 78H,79H 01111010 0 Status 7CH 01111010 1 Daten 7DH 01111011 X /DACK 7E,7FH
7X/5X/3X/1X 0/1 2/3 4/5 6/7 8/9 A/B C/D E/F

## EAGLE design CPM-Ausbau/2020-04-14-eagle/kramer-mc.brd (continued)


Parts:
C8: 1n; C050-024X044
D1: 7SEG-CK; 7SEG-13
FDCX3: ML34
FDCX4: ML20
IC7: 74LS74N; DIL14
IC10: 74LS03D; SO14
IC12: V40511D; DIL16
IC13: 74LS06N; DIL14
LED4: TLLG4400; LED3MM
R34, R35, R36, R37, R38, R39: 4k7; 0309/12
R40: 200; 0309/12
R41, R42, R44, R45, R46, R47, R49: 680; 0309/12
R43: 470; 0309/12
S4: 10-XX; B3F-10XX
S5: 316-917

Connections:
/BUSRQ: FDCX4.2; also elsewhere on the board
/CSBWS1: FDCX3.25
/IEI: FDCX3.16; also elsewhere on the board
/IEO: FDCX3.15; also elsewhere on the board
/IORQ: FDCX4.10, IC10.5 (I1); also elsewhere on the board
/M1: FDCX4.13; also elsewhere on the board
/MEMDI: FDCX3.14; also elsewhere on the board
/MREQ: FDCX3.13, IC10.4 (I0); also elsewhere on the board
/RD: FDCX3.12; also elsewhere on the board
/RESET1: FDCX4.1
/WAIT: FDCX4.9, IC10.3 (O), R39.1; also elsewhere on the board
/WR: FDCX3.11; also elsewhere on the board
A0: FDCX3.17, IC12.7 (IA), IC13.1 (I); also elsewhere on the board
A1: FDCX3.18, IC12.1 (IB); also elsewhere on the board
A2: FDCX3.19, IC12.2 (IC); also elsewhere on the board
A3: FDCX3.20, IC12.6 (ID); also elsewhere on the board
A4: FDCX3.21; also elsewhere on the board
A5: FDCX3.22; also elsewhere on the board
A6: FDCX3.23; also elsewhere on the board
A7: FDCX3.24; also elsewhere on the board
A8: FDCX3.27; also elsewhere on the board
A9: FDCX3.28; also elsewhere on the board
A10: FDCX3.29; also elsewhere on the board
A11: FDCX3.30; also elsewhere on the board
A12: FDCX3.31; also elsewhere on the board
A13: FDCX3.32; also elsewhere on the board
A14: FDCX3.33; also elsewhere on the board
A15: FDCX3.34; also elsewhere on the board
D0: FDCX3.3; also elsewhere on the board
D1: FDCX3.4; also elsewhere on the board
D2: FDCX3.5; also elsewhere on the board
D3: FDCX3.6; also elsewhere on the board
D4: FDCX3.7; also elsewhere on the board
D5: FDCX3.8; also elsewhere on the board
D6: FDCX3.9; also elsewhere on the board
D7: FDCX3.10; also elsewhere on the board
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

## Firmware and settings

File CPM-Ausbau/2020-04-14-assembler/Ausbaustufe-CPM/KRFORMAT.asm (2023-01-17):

	;.Z80
	;TITLE 'Disketten-INIT'
	; CP/M Kommando KRFORMAT lies Kramer-Format

	;Programm arbeitet in Verbindung mit Monitor

	; Vereinbarungen
CFDC:	EQU	07CH		;FLOPPY CONTROLLER
DFDC:	EQU	07DH
ZFDC:	EQU	070H
FMTAB:	EQU	0300H
CTAB:	EQU	0F800H
RESLT:	EQU	CTAB+9
BDOS:	EQU	5
CI:	EQU	0EA09H		;Monitoradressen
RESTR:	EQU	000H
TCPLS:	EQU	0EA33H		; in CBIOS Sprungtabelle
OBYTE:	EQU	0F545H
	ORG	100H
;--------------------------------------------------------------------------
; HAUPTPROGRAMM
;--------------------------------------------------------------------------
;INIFD:	ld	a, 20h		; 0010 0000 FDC	Reset
;	out	(ZFDC),a
;	ld	a, 13h		; 0001 0011 Terminal Count aktivieren, Motor LW	1+2 an
;	out	(ZFDC),a
;	LD	A,03H		;***************************  TC High aktiv, beide Motoren
;	OUT	(ZFDC),A
;;	ld	(ZFDC1),a	; aktuelle Ausgabe speichern

FORM:	LD	DE,TEXT		;Textausgabe
	LD	C,9
	CALL	BDOS
	CALL	CI		;Warten auf Konsoleneingabe
	CP	79H		;kleines y 
	JR	Z,INIFD1	
	LD	A,0		;Ende des Formatierens,	 Motoren aus
	OUT	(ZFDC),A
	JP	RESTR		;zurück zum Monitor, dann sollten dieMotoren ausgehen
INIFD1:	EQU	$
;INIFD1:	LD	B,0		;INITIALISIERUNG P8272
;INIFD2:	DJNZ	INIFD2
;	IN	A,(CFDC)
;	CP	80H
;	JR	Z,SPEZI
;	IN	A,(DFDC)
;	JR	INIFD1
;SPEZI:	LD	HL,STAB-1	;PARAMETER LADEN
;	LD	BC,0303H	;SPECIFY-Kommando (Initialisieren) 03 in C, B Länge 3  3BYTES
;	CALL	WCOM1		;SCHREIBEN COMM

	CALL	RECAL		;Kopf auf Spur 0

	LD	C,0		;Spur 0
FORM0:	LD	B,1		;Sektor
	LD	E,0		;Kopfauswahl für beidseitige Laufwerke
	LD	A,C
	LD	(CTAB+2),A	;Spurnummer für 0F Kommando Spur suchen
	PUSH	BC
	CALL	SEEK		;Spur einstellen
	POP	BC
	LD	HL,FMTAB+010H*4-1	;Tabellenende
	LD	A,010H		;Anzahl Sektoren
FORM2:	LD	(HL),1		;Setzen N Zahl der Datenbytes per Sektor?? 1:256
	DEC	HL
	LD	(HL),A		;Set R  Record oder Sektor Nummer
	DEC	HL
	LD	(HL),E		;SET Head (Kopf)
	DEC	HL
	LD	(HL),C		;SET C  Cylinder, Spur nummer
	DEC	HL
	DEC	A		;Dec Sektornummer
	JR	NZ,FORM2
	LD	(HL),0E5H	; Füllbyte  HL steht auf FMTAB-1 stimmt, getestet
	DEC	HL
	LD	(HL),53		;GAP Lückenlänge
	DEC	HL
	LD	(HL),010H	;EOT (Letzte Sektornummer)	 
	DEC	HL
	LD	(HL),1		;N, 1=256 Bytes pro Sektor
	DEC	HL
	LD	(HL),0		; HDS DS1 DS0
	DEC	HL		;HL: FMTAB-6  stimmt, getestet
	PUSH	BC
	PUSH	AF
;	Call	obyte		; A auf Bildschirm ausgeben
	LD	B,6		;Anzahl Kommandobytes für FDC
	LD	C,04DH		;Kommando Format a Track
	CALL	WCOM1		; In FDC schreiben
	CALL	F4		;Ausführung     eine Spur formatieren
	CALL	TC	;*****	OUT	(TC),A		; ENDE Impuls
	CALL	RRSLT
	POP	AF
	POP	BC
	JP	NZ,RESTR2	;Fehler
	INC	C
	PUSH	AF
	PUSH	BC
	Call	obyte
	POP	BC
	POP	AF
	LD	A,C
	CP	40
	JR	NZ,FORM0
	JR	FORM

TEXT:	DEFM	'FORMAT Y23VO',0DH,0AH
	DEFM	'40 TRACKS, 16 SECTORS, 256 BYTES',0DH,0AH
	DEFM	'Program KRFORMAT Kramer-Format',0DH,0AH
	DEFM	'Diskette ? (y)',0DH,0AH,'$'

	;Formatierschleife für eine Spur
F4:	LD	C,DFDC		;wieso steht hier D und nicht C??, Abschreibefehler C muß hin
	LD	B,010H*4	;ANZAHL ID
FORM3:	IN	A,(CFDC)
	RLCA			;RQM Test  Bit 7 des Hauptstatusregisters  =1 U8272 fertig und bereit
	JR	NC,FORM3
	RLCA			;DIO
	RLCA			;NON-DMA
	RET	NC		;Fertig? 0: ja
	OUTI			; out (HL) to port BC  inc HL dec BC
	JR	NZ,FORM3
	RET

;SEITE 2

;--------------------------------------------------------------------------
; UNTERPROGRAMME
;--------------------------------------------------------------------------
TC:	JP	TCPLS		;TC LOW Puls erzeugen CBIOS-Routine
;--------------------------------------------------------------------------

RECAL:	LD	BC,0207H	;SPUR 0 einstellen  Länge 2 in B, Kommando 07H in C
	CALL	RDY		;Drive ready
;--------------------------------------------------------------------------
SENSE:	LD	BC,0108H	;Prüfe Interruptstatus
	CALL	WCOM
	CALL	RBYTE		;RESULT REG 0:IC1,IC2,SE,EC,NR,HD,US1,US2
	LD	B,A
	CP	080H
	CALL	NZ,RBYTE	;PCN holen
	BIT 	5,B		;SEEK ENDE?
	JR	Z,SENSE
	RET
;--------------------------------------------------------------------------
STAB:	DB	1FH		;XXXX=Schrittzeit SRT,XXXX=Kopfabfallzeit HUT 
	DB	33H		;XXXXXXX= Kopfladezeit HLT, X= NoDMA ND
;--------------------------------------------------------------------------
SDS:	LD	BC,0204H	;Prüfe LW-Status Kommando 04H Länge 2
	CALL	WCOM
	CALL	RBYTE		; Status Reg 3: FAULT,WP,RDY,TO,TS,HD,US1,U
	RET
;--------------------------------------------------------------------------
SEEK:	LD	BC,030FH	;COMM SPUR einstellen
	CALL	RDY		;Kommando senden
	CALL	SENSE
SKBSY:	IN	A,(CFDC)
	AND	0FH
	JR	NZ,SKBSY
	RET
;--------------------------------------------------------------------------
RDY:	PUSH	BC		;Laufwerk betriebsfähig?
	CALL	SDS
	POP	BC
	BIT	5,A		; Ready-Bit in Statusreg. 3
	CALL	Z,RESTR3		;Fehler
;--------------------------------------------------------------------------
WCOM:	LD	HL,CTAB		;COMM in FDC schreiben
				;IN: B Anzahl der BYTES, C COMM
WCOM1:	CALL	DELAY
	IN	A,(CFDC)
	AND	0C0H
	CP	080H		;RQM, DIO = OUT
	JR	NZ,WCOM1
	LD	A,C
	OUT	(DFDC),A
	INC	HL
	LD	C,(HL)
	DJNZ	WCOM1
	RET
;--------------------------------------------------------------------------
DELAY:	PUSH	BC		;Verzögerung für Statusflag 8272
	LD	B,0FH
DEL1:	DJNZ	DEL1
	POP	BC
	RET
;--------------------------------------------------------------------------
RBYTE:	CALL	DELAY		; Ein Byte lesen
	CALL	IRDY
	IN	A,(DFDC)
	RET
;--------------------------------------------------------------------------
RRSLT:	LD	B,6		;Lese 7 Result-Bytes
	CALL	RBYTE
	LD	HL,RESLT
	LD	(HL),A
	AND	0C0H		;ERROR?
	LD	C,A
RESL1:	CALL	RBYTE
	INC	HL
	LD	(HL),A
	DJNZ	RESL1
	LD	A,C		;Fehlermeldung Status-REG 0
	OR	A
	RET
;--------------------------------------------------------------------------
IRDY:	IN	A,(CFDC)
	RLCA
	JR	NC,IRDY		; warten auf RQM=1  8272 fertig?
	AND	080H
	RLCA
	JR	NC,IRDY	
	RET	C
;--------------------------------------------------------------------------
;Fehlerbehandlung: Sprung in Monitor
RESTR1:	LD	A,'1'
	LD	(0FD3FH),A 	;einfach auf den Bildspeicher
	JP	RESTR
RESTR2:	LD	A,'2'
	LD	(0FDBFH),A 	;einfach auf den Bildspeicher
	JP	RESTR
RESTR3:	LD	A,'3'
	LD	(0FE3FH),A 	;einfach auf den Bildspeicher
	JP	RESTR

;--------------------------------------------------------------------------
	;END
